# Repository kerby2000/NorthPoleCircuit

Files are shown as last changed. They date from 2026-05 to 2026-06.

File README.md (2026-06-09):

# North Pole BLE Audio Card

This is a work-in-progress derivative of the original
[Janky Jingle Crew NorthPoleCircuit](https://github.com/Janky-Jingle-Crew/NorthPoleCircuit).

The goal is to turn the original moving magnetic Christmas PCB card into a BLE-enabled audio postcard / mini-diorama with rechargeable battery power, real audio playback, capacitive touch controls, Hall checkpoints, and addressable RGB lighting.

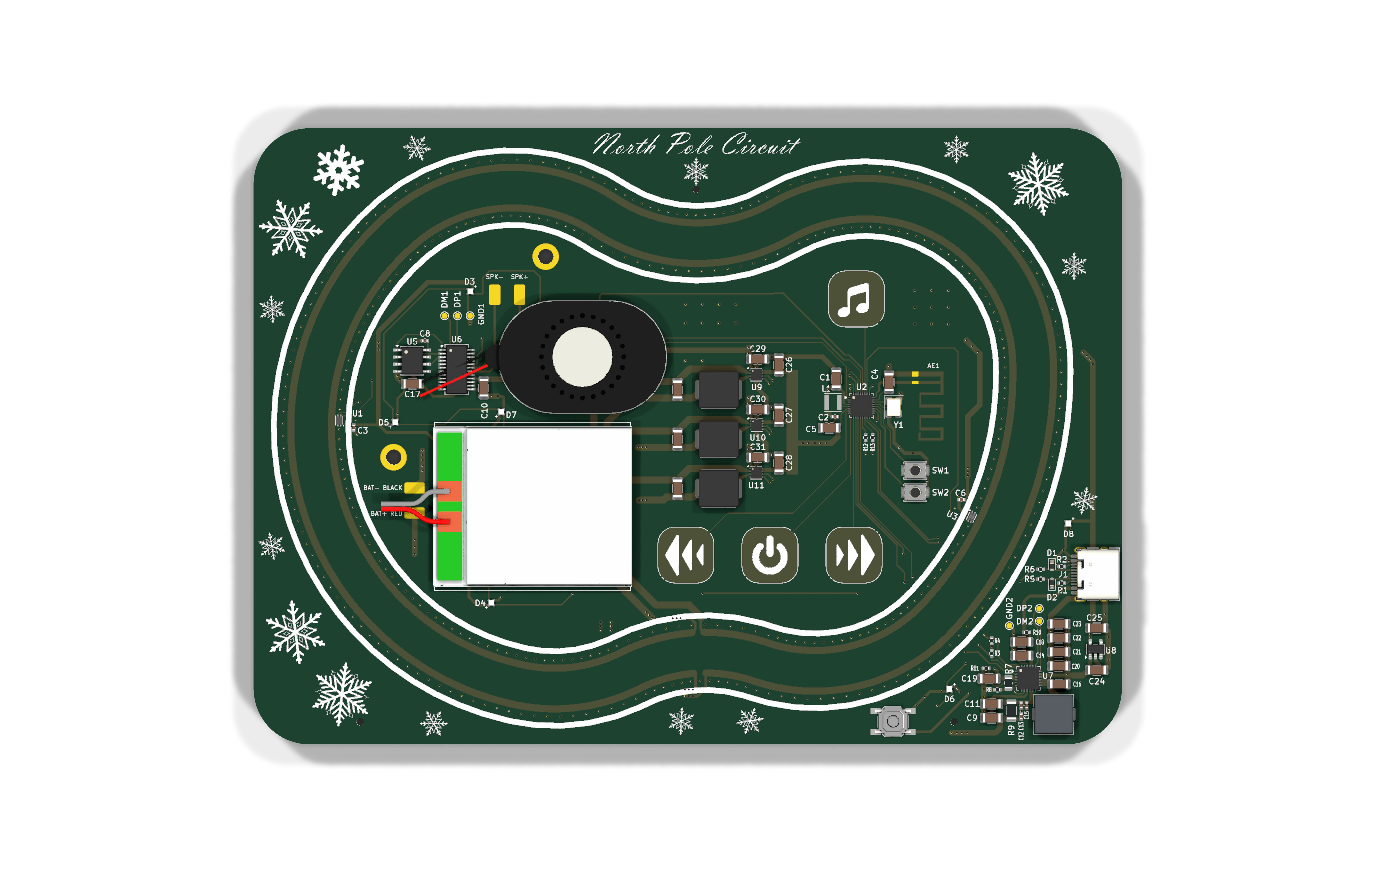
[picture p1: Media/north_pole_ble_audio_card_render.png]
North Pole BLE Audio Card PCB render


## Status

Current state: hardware revision in progress.

- KiCad 10 PCB project is included under `PCB/`.
- Draft JLCPCB manufacturing files are included under `PCB/production/`.
- Firmware bring-up scaffold lives under `Firmware/northpole_ch592_bringup/` and is based on the WCH CH592 EVT BLE Peripheral project.
- The board has not yet been validated on real hardware.
- The audio playback IC sourcing is still a risk and should be checked before ordering.

Do not treat the current production files as a proven release. Review ERC/DRC, BOM sourcing, assembly rotations, antenna keepout, LiPo safety, and audio availability before manufacturing.

## Repository Layout

```text
PCB/                     KiCad 10 hardware project and draft manufacturing files
Firmware/                CH592X BLE/audio firmware bring-up project and docs
audio_assets/            WT2003 external-flash manifest and copy-order packer
Code/                    Original upstream firmware, kept for reference only
CAD/                     Original upstream mechanical assets
Media/                   Original media plus new PCB renders
CHANGES_FROM_ORIGINAL.md Summary of the redesign
```

## Hardware Overview

This redesign keeps the magnetic track idea from the original project, but changes most of the control electronics.

Main blocks in the current KiCad design:

- CH592X BLE MCU
- 3 x DRV8837 H-bridge motor drivers
- WT2003H4-24SS audio playback IC
- PY25Q64HA SPI NOR flash for audio assets
- IP5209 1S LiPo charge / boost PMIC
- ME6211 3.3 V regulator
- 2 x DRV5032 Hall sensors
- 4 capacitive touch buttons
- 6 x 1010 addressable RGB LEDs, currently JLCPCB `C41347988`
- USB-C input
- 32 MHz crystal
- WCH-style PCB BLE antenna footprint
- J3 WCH-LinkE/debug Tag-Connect footprint
- J4 WT2003 USB update Tag-Connect footprint
- thin speaker and 1S LiPo battery placement helpers

## Opening The PCB

Use KiCad 10.

Open:

```text
PCB/NorthPoleCircuit_PCB.kicad_pro
```

The local custom libraries are kept in the repo:

- `PCB/cust_sym.kicad_sym`
- `PCB/cust_fp/`
- `PCB/footprints.pretty/`

## Manufacturing Files

Draft manufacturing outputs are in:

```text
PCB/production/
```

Included files:

- `NorthPoleCircuit_PCB14.zip` - Gerber/drill archive
- `bom.csv` - JLCPCB BOM
- `positions.csv` - JLCPCB pick-and-place
- `designators.csv` - Fabrication Toolkit designator output

Before ordering, re-export these from KiCad/Fabrication Toolkit and compare against the files here.

## Firmware

Firmware for this revision is under [Firmware/](./Firmware/). The initial target is `Firmware/northpole_ch592_bringup/`, copied from a working WCH CH592 EVT BLE Peripheral example and then modified at the application layer.

Important hardware notes:

- J3 is WCH-LinkE/debug: 1=3.3V target reference, 2=TIO/SWDIO/PB14, 4=TCK/SWDCK/PB15, 5=GND, 3/6=NC.
- PB14/PB15 are shared with IP5209 I2C through R15/R14 0 ohm links. Do not expect IP5209 I2C access during active WCH-LinkE debugging.
- J4 is intended as WT2003 USB update only, not ARM SWD, but the current PCB revision is blocked for update use: pin 1 is unconnected, so J4 has D+/D-/GND only. Do not use it for WT2003 USB update until +5 V is routed or a rework power path is documented.
- PB0 controls global DRV8837 `~SLEEP`; idle/fault state is `/SLEEP` low and all bridge IN pins low.

The existing `Code/` directory is from the original upstream NorthPoleCircuit project and is not firmware for the CH592X BLE/audio redesign.

## Major Changes

See [CHANGES_FROM_ORIGINAL.md](./CHANGES_FROM_ORIGINAL.md).

Short version:

- single BLE-capable CH592X control architecture
- rechargeable LiPo power path
- audio playback IC and speaker path
- capacitive touch buttons
- Hall checkpoint sensing
- addressable RGB LEDs
- revised KiCad 10 PCB with custom artwork and JLCPCB metadata

## Attribution

Original project:

- [Janky Jingle Crew - NorthPoleCircuit](https://github.com/Janky-Jingle-Crew/NorthPoleCircuit)

Related inspiration:

- [Jeff McBride - Gauss Speedway](https://jeffmcbride.net/gauss-speedway/)

This repository is a derivative redesign. The original concept, mechanical idea, and much of the visual/magnetic-track inspiration belong to the original authors.

## License

TODO.

Before publishing a release or manufacturing publicly, verify the license/permission status of the upstream NorthPoleCircuit project. If the upstream project has no explicit open-source license, only the new original work in this redesign can be licensed without additional permission.

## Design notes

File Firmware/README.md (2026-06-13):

# Firmware

Firmware for the CH592X BLE/audio revision now has a MounRiver/WCH EVT based bring-up project under `Firmware/northpole_ch592_bringup/`.

The original upstream firmware still exists in `../Code/`, but it targets the original NorthPoleCircuit architecture. Treat it as reference material only. New code should live under `Firmware/` and should be written around the current KiCad design: CH592X BLE MCU, 3 x DRV8837 phase drivers, WT2003H4 audio playback IC, PY25Q64HA audio flash, IP5209 LiPo charge/boost PMIC, ME6211 3.3 V regulator, 2 x DRV5032 Hall sensors, 4 capacitive touch pads, and 6 x addressable RGB LEDs.

## Current Implementation Status

The bring-up framework has been started under this folder and the active target project is copied from the WCH CH592 EVT BLE `Peripheral` example.

- KiCad hardware audit script: `tools/extract_kicad_pinmap.py`
- Generated hardware audit: `docs/hardware_pin_audit.md`
- Generated firmware hardware notes: `northpole_ch592_bringup/APP/include/board_pins_autogen_notes.h`
- MounRiver project: `northpole_ch592_bringup/`
- Safe board pin framework: `northpole_ch592_bringup/APP/include/board.h`, `northpole_ch592_bringup/APP/include/board_pins.h`, `northpole_ch592_bringup/APP/northpole/board.c`
- Bring-up and production entry split: `northpole_ch592_bringup/APP/northpole/app_bringup.c`, `northpole_ch592_bringup/APP/northpole/app_production.c`
- Diagnostic shell scaffold: `northpole_ch592_bringup/APP/northpole/shell.c`
- Peripheral driver scaffolds: motor, Hall, touch, RGB, audio, IP5209, battery, BLE, settings

The selected first target toolchain direction is WCH CH592 EVT SDK native style through MounRiver Studio. See `docs/toolchain.md`.

The unmodified WCH EVT BLE `Peripheral` example builds locally with the MounRiver-bundled `riscv-none-embed-gcc`. The copied North Pole bring-up project also builds locally.

## CH592 Upload Path Status

Primary development/debug path:

```text
MounRiver Studio + WCH-LinkE
```

MounRiver/WCH-LinkE remains the primary development path. A MounRiver LED probe under `mounriver_ch592_led_probe/` builds, downloads, verifies, resets, and runs through MounRiver.

The official native USB ISP GUI path is also proven on the CH592X-EVT-R1-LinkE board:

```text
WCHISPStudio V3.9
Internal tool: WCHISPTool_CH57x-59x V3.10
CH592 USB Download device: 4348:55E0
Driver: official WCH CH375/WCHLink driver stack
```

Secondary and experimental paths are tracked separately:

```text
docs/ch592_upload_matrix.md
docs/ch592_usb_isp_test_plan.md
docs/wlink_attach_debug.md
```

Current policy:

- Daily development/debug: MounRiver, WCH-LinkUtility, or PlatformIO custom `wlink` with manual Download-mode entry.
- Emergency/field flashing: WCHISPStudio GUI native USB ISP is proven; a Windows official CMD tool has not been found yet.
- PlatformIO: `wlink` upload is usable after manual Download-mode entry; native USB ISP through `wchisp` remains experimental.
- PlatformIO bundled `wchisp -V` / no-verify is not acceptable because a no-verify image did not run.
- Do not swap the CH592 USB Download driver with Zadig during normal work. WCHISPStudio and `wchisp` need different driver bindings for `4348:55E0`.

Critical recovery note:

If WCH-LinkUtility, MounRiver, or `wlink` suddenly stop identifying the CH592 after ISP/config
experiments, the chip may be protected. WCHISPStudio can still flash in this state, but WCH-Link
debug attach fails. The recovery that worked was:

```powershell
# Put CH592 into USB Download mode.
# Use Zadig only on USB Module / 4348:55E0, not WCH-Link / 1A86:8010.
$wchisp = "$env:USERPROFILE\.platformio\packages\tool-wchisp\wchisp.exe"
& $wchisp config unprotect
```

See `docs/ch592_unprotect_recovery.md`. Keep `Code and data protection mode` unchecked during
bring-up.

If the bootloader no longer stays visible long enough for normal tools, see
`docs/ch592_brick_recovery.md` and the polling recovery script
`tools/ch592_recovery/revive_ch59x.py`.

## Commands

Regenerate the hardware audit:

```powershell
python Firmware\tools\extract_kicad_pinmap.py --repo-root .
```

Run the build wrapper in audit-only mode:

```powershell
powershell -ExecutionPolicy Bypass -File Firmware\tools\build.ps1 -AuditOnly
```

Build wrappers for the intended profiles:

```powershell
powershell -ExecutionPolicy Bypass -File Firmware\tools\build.ps1 -Profile evt-baseline
powershell -ExecutionPolicy Bypass -File Firmware\tools\build.ps1 -Profile bringup
powershell -ExecutionPolicy Bypass -File Firmware\tools\build.ps1 -Profile production
powershell -ExecutionPolicy Bypass -File Firmware\tools\build_mvp_demo.ps1
powershell -ExecutionPolicy Bypass -File Firmware\tools\build_matrix.ps1
```

These wrappers default to `C:\WCH\CH592EVT` and `C:\MounRiver\MounRiver_Studio2`. Build outputs are expected under `Firmware/build/`, which is ignored by git.

The MVP demo wrapper writes its flashable image to:

```text
Firmware/build/mvp_demo/northpole_ch592_bringup.hex
```

Use this only with the documented Rev-A rework state:
`docs/mvp_demo.md`, `docs/rev_a_mvp_rework_state.md`, and
`docs/first_integrated_demo_checklist.md`.

Run host-side logic tests:

```powershell
python -m unittest discover Firmware\host_tests
```

Smoke-test scripts for first-board validation:

```powershell
python Firmware\tools\usb_shell_smoke_test.py --port COM7
python Firmware\tools\ble_diag_smoke_test.py --scan
```

## Hardware Audit Result

The current generated audit passes the major firmware-facing connections. The suspected WT2003 UART issue is not a board blocker in the current PCB: U2 UART nets reach WT2003 RX/TX through R12/R13 series resistors. The WCH UART backend and WT2003HX V2.00 protocol layer exist in the MounRiver bring-up project, but WT2003 command responses, BUSY timing, and playback still need hardware validation before production use.

## Firmware Strategy

Use two top-level firmware entry points with shared drivers:

- `main_production.c` - the final user-facing firmware. It should expose only safe controls, run quiet logging, enforce current/time limits, handle faults cleanly, and default to low-power idle.
- `main_bringup.c` - a diagnostic firmware with explicit test hooks for board validation. It should expose raw sensor readings, manual peripheral commands, motor safety interlocks, and verbose status output.

Both builds should share the same board support and peripheral drivers. The split should be at the application layer, not by duplicating low-level code.

Recommended structure:

```text
Firmware/
  README.md
  platformio.ini or wch_project/
  include/
    board.h
    build_profile.h
    fault.h
  src/
    main_production.c
    main_bringup.c
    board.c
    clock.c
    log.c
    fault.c
    power_ip5209.c
    battery.c
    touch.c
    rgb_ws2812.c
    hall.c
    motor_drv8837.c
    motor_track.c
    audio_wt2003.c
    audio_assets.c
    ble_service.c
    settings.c
    diagnostics.c
  tools/
    flash.ps1 or flash.sh
    read_log.ps1 or read_log.sh
    audio_asset_pack.py
```

If the selected CH592X toolchain makes separate entry files awkward, use one entry file plus a compile-time profile:

```c
#if defined(FIRMWARE_PROFILE_BRINGUP)
    app_bringup_run();
#else
    app_production_run();
#endif
```

## Shared Firmware Rules

- All outputs must start in the safest state: motor driver inputs low, motor enables off, RGB LED output idle, audio stopped or muted, unused pins configured deliberately.
- Production and bring-up builds must use the same `board.c` pin map so a wiring fix is made once.
- Motor commands must have a timeout/deadman. If the main loop stalls, BLE disconnects, or the command stream stops, PWM should go to zero and the DRV8837s should disable.
- Keep BLE, LED timing, touch sampling, and motor PWM from blocking each other. Use timer/DMA/peripheral support where possible, especially for WS2812 timing.
- Do not allow raw motor bridge commands in production BLE services.
- Keep current limits conservative until real board measurements exist.
- Store board revision, firmware profile, firmware version, and build date in a readable diagnostic command.
- Every bring-up command that can heat the coils, stress the battery, or make sound must be explicit and bounded.

## Toolchain And Project Setup

1. Select the CH592X build path.
   - Prefer the WCH-supported CH592X SDK/toolchain if it gives reliable BLE examples and flashing.
   - Confirm the linker script, startup code, BLE stack library, USB/UART support, and flash programming path before writing board-specific code.
   - Record the exact SDK version and flashing adapter in this README once selected.

2. Create a minimal firmware project.
   - Build an empty CH592X app.
   - Flash it to a known-good dev board or first PCB if available.
   - Confirm reset, boot mode, programming connection, and a basic delay loop.

3. Add build profiles.
   - `production`: optimized, limited logs, watchdog enabled, safe feature set.
   - `bringup`: verbose logs, diagnostic command interface, asserts enabled, extra telemetry.

4. Add repeatable commands.
   - Build production firmware.
   - Build bring-up firmware.
   - Flash selected profile.
   - Capture serial logs.
   - Stamp firmware version and git commit into the build.

5. Create the board pin map.
   - Extract every CH592X pin assignment from `../PCB/NorthPoleCircuit_PCB.kicad_sch`.
   - Define pins once in `board.h` and `board.c`.
   - Include signal direction, reset state, active polarity, alternate function, and safety notes.
   - Verify peripheral mux conflicts before writing drivers.

## Production Firmware Plan

The production firmware should behave like a finished BLE audio postcard, not like a test fixture.

Core production behavior:

- Boot into a safe idle state.
- Run a short self-test that checks firmware identity, stored settings, battery status if available, and peripheral readiness.
- Advertise BLE with a stable device name.
- Support touch controls for local operation.
- Play predefined scenes that coordinate audio, RGB animation, and track motion.
- Use Hall sensor events to synchronize or correct sled movement when possible.
- Use conservative motor acceleration, speed, duty, and runtime limits.
- Enter a low-power idle mode when inactive.
- Expose clear fault behavior: low battery, motor overrun timeout, audio failure, BLE command invalid, storage/settings invalid.

Suggested production touch mapping:

- Touch 1: play/pause current scene.
- Touch 2: next scene or next track.
- Touch 3: brightness or volume step.
- Touch 4: BLE/config action, long-press for pairing/config reset.

Suggested production BLE services:

- Device information: firmware version, board revision, profile, battery/status.
- Playback control: play, pause, stop, next scene, volume.
- Lighting control: brightness, selected palette, animation mode.
- Motion control: safe scene-level speed/intensity only. No raw phase commands.
- Settings: persistent volume, brightness, demo mode, shipping/low-power mode.
- Diagnostics: read-only fault/status counters.

Production safety requirements:

- Motor PWM starts disabled and only enables inside a scene or validated motion command.
- Motor runtime has a hard maximum per activation.
- Motor duty and acceleration are capped by constants measured during bring-up.
- BLE disconnect or invalid command leaves the active scene in a known state.
- Low battery or unstable supply prevents motor start.
- Watchdog resets into motor-off/audio-off/RGB-off state.

## Bring-Up Firmware Plan

The bring-up firmware should make the board easy to validate one subsystem at a time. It should be allowed to expose unsafe low-level commands, but each risky command must require arming and must time out automatically.

Preferred interfaces:

- Serial diagnostic shell over the available debug UART or USB CDC if practical.
- Optional BLE diagnostic service after BLE is proven.
- Human-readable command responses with machine-readable values where possible.

Suggested diagnostic commands:

```text
help
version
status
faults
pins
rail status
rail battery
touch raw
touch stream
touch threshold <pad> <value>
rgb off
rgb one <index> <r> <g> <b>
rgb chase <brightness>
hall read
hall stream
audio status
audio version
audio qstatus
audio qcount-ext
audio qperiph
audio volume <0-31>
audio play-index <file_id>
audio play-name <name-no-ext>
audio stop
i2c scan
ip5209 read
motor arm <seconds>
motor off
motor phase <driver> <a|b|coast|brake> <duty>
motor pwm <driver> <forward|reverse> <duty>
motor step <direction> <steps> <duty>
motor sweep <direction> <duty> <seconds>
scene demo
sleep
reset
```

Bring-up firmware guardrails:

- `motor arm` is required before any motor command.
- The arm window expires automatically.
- Motor duty has a compile-time bring-up maximum that starts very low.
- The shell prints the active current/duty/time limit before enabling motor outputs.
- Audio starts at low volume.
- RGB brightness starts low to limit current.
- Commands that change persistent settings should require explicit confirmation.

## Board Bring-Up Checklist

Use the bring-up firmware only after the hardware passes basic power checks. Do not connect a LiPo cell until the USB power path, charge behavior, and battery pad polarity are verified.

Required bench equipment:

- Current-limited bench supply.
- USB-C power meter or current-limited USB source.
- Digital multimeter.
- Oscilloscope or logic analyzer.
- CH592X-compatible programmer/debug adapter.
- BLE scanner phone or desktop BLE tool.
- Known-good small speaker or dummy load as appropriate.
- Magnet or assembled sled for Hall testing.
- Thermal camera or contact thermometer for motor/PMIC checks.

### Stage 0: Pre-Power Inspection

1. Confirm board revision and assembly options.
2. Inspect USB-C, IP5209, ME6211, CH592X, WT2003H4, DRV8837s, Hall sensors, RGB LEDs, and crystal orientation.
3. Check for solder bridges around the QFN/SSOP/QFP fine-pitch parts.
4. Measure resistance to ground on VBUS, battery pad, boosted rail if exposed, and 3.3 V.
5. Confirm battery pad polarity against board markings.
6. Confirm no visible copper damage around the antenna and matching network.
7. Record photos before applying power.

Exit criteria:

- No hard short on the main rails.
- Battery polarity is confirmed.
- Visual inspection has no unresolved assembly defects.

### Stage 1: Power Path Smoke Test

1. Power from USB-C with a conservative current limit and no battery installed.
2. Measure VBUS at the connector and downstream power path.
3. Measure battery pad voltage and confirm charge behavior is sane with no battery attached.
4. Measure the ME6211 3.3 V output.
5. Check rail ripple and startup shape with the oscilloscope.
6. Touch-check or thermal-check the IP5209, regulator, MCU, and audio IC for abnormal heating.
7. Repeat USB-C plug orientation tests.
8. If using a battery simulator or protected cell, verify charge current and termination behavior before installing a real cell.

Exit criteria:

- 3.3 V is within tolerance.
- No component heats unexpectedly.
- USB-C orientation does not change behavior.
- Battery/charger behavior is understood before a LiPo is attached.

### Stage 2: CH592X Programming And Clock Bring-Up

1. Connect the programmer/debug adapter.
2. Confirm the target can be identified.
3. Flash a minimal bring-up image.
4. Verify reset behavior and boot mode.
5. Start a debug UART or USB log if available.
6. Confirm the system clock and 32 MHz crystal behavior.
7. Blink or toggle a harmless GPIO if one is available, or print a heartbeat log.

Exit criteria:

- Firmware can be flashed repeatedly.
- Reset and boot are reliable.
- A stable debug log or heartbeat exists.

### Stage 3: Safe Pin Initialization

1. Boot the bring-up firmware with all high-power outputs disabled.
2. Verify DRV8837 input pins and enables are inactive after reset and after firmware startup.
3. Verify the RGB data line does not produce random LED colors at boot.
4. Verify audio control pins do not start playback or pop the speaker.
5. Confirm unused pins are configured to avoid floating high-current states.
6. Save oscilloscope captures of sensitive outputs during reset.

Exit criteria:

- Firmware startup does not move the sled, flash the LEDs unexpectedly, or start audio.
- All unsafe outputs remain off until commanded.

### Stage 4: Low-Speed Digital Interfaces

1. Run `i2c scan`.
2. Confirm the IP5209 responds if its I2C interface is present and enabled on this board.
3. Read battery/charge/status registers if supported.
4. Log fallback ADC or GPIO status if the PMIC interface is not usable.
5. Verify pullups, bus idle levels, and clock/data waveforms.

Exit criteria:

- I2C bus does not hang.
- Power/battery status path is either working or documented as unavailable.

### Stage 5: Capacitive Touch

1. Read raw counts from all 4 pads with the board untouched.
2. Read raw counts while touching each pad individually.
3. Repeat with USB powered, battery powered, and while audio/RGB/motor are idle.
4. Tune baseline tracking, debounce, hysteresis, and long-press timing.
5. Check false touches near the track, battery, speaker, and antenna areas.
6. Store initial thresholds as conservative defaults.

Exit criteria:

- Each pad has clear touch/no-touch separation.
- False triggers are rare during idle.
- Long press and short press behavior is repeatable.

### Stage 6: RGB LED Chain

1. Start with global brightness capped low.
2. Light one LED red, green, and blue to verify color order.
3. Step through all 6 LEDs to verify chain order and soldering.
4. Run a low-brightness chase pattern.
5. Check supply ripple and current draw at increasing brightness levels.
6. Confirm BLE and touch still work while LEDs update.

Exit criteria:

- All 6 LEDs respond in the expected order.
- Color order is documented.
- Production brightness limit is chosen from measured current draw.

### Stage 7: Hall Sensors

1. Read idle state from HALL1 and HALL2.
2. Move a magnet over each sensor and record transition polarity.
3. Test with the actual sled magnet orientation.
4. Decide whether polling or interrupts are more reliable.
5. Tune debounce and minimum interval filtering.
6. Log events while manually moving the sled around the track.

Exit criteria:

- Both Hall sensors detect the sled reliably.
- Event polarity and timing are documented.
- Production filtering constants are chosen.

### Stage 8: Audio Playback

1. Confirm WT2003H4 power rails and reset state.
2. Verify UART idle level and baud rate.
3. Run `audio version`, `audio qperiph`, and `audio qcount-ext`.
4. After the J4 +5 V update-power issue is fixed or a rework path is documented, program or install one minimal known-good `0001.mp3` asset, then disconnect WT2003 USB.
5. Set `audio volume 5` and play a short low-volume test file with `audio play-index 1`.
6. Test stop, volume, next-file, and error/status responses.
7. Measure current draw and check for speaker pops at startup/shutdown.
8. Document the audio file naming, indexing, and flash programming process.

Exit criteria:

- At least one audio file plays reliably.
- Volume and stop commands work.
- Audio asset packaging is repeatable.

### Stage 9: BLE Bring-Up

1. Advertise a bring-up device name that includes the board/profile.
2. Confirm discovery with a phone or desktop BLE scanner.
3. Connect, disconnect, and reconnect repeatedly.
4. Expose read-only version/status first.
5. Add safe commands for RGB, audio, and touch status.
6. Add production-level playback/settings controls after the basic service is stable.
7. Test BLE while RGB animations and touch scanning are active.

Exit criteria:

- Advertising and reconnect are reliable.
- GATT characteristics are documented.
- BLE does not break timing-sensitive peripherals.

### Stage 10: DRV8837 And Track Motor Bring-Up

Do this last. Use a current-limited supply and start with the lowest possible duty cycle. Keep the board accessible for temperature checks.

1. Confirm motor/coil resistance and expected current before enabling firmware control.
2. Scope each DRV8837 input while outputs are still disabled or unloaded if practical.
3. Enable one DRV8837 at a time with very low duty and short duration.
4. Test coast, brake, forward, and reverse behavior where applicable.
5. Verify no shoot-through command sequence is possible in the driver abstraction.
6. Measure supply current and component temperature after each short pulse.
7. Increase duty only after current and heating are understood.
8. Bring up phase stepping without the sled, then with the sled.
9. Determine phase order, direction sign, starting duty, running duty, acceleration ramp, and maximum safe runtime.
10. Use Hall events to validate speed and position assumptions.
11. Save measured safe limits into production constants.

Exit criteria:

- All 3 DRV8837 channels respond correctly.
- The sled can move under firmware control.
- Thermal/current limits are measured and documented.
- Production motor constants are conservative.

### Stage 11: Integrated Demo

1. Build one simple scene: touch starts audio, RGB animation, and low-speed sled movement.
2. Use Hall checkpoints to log movement timing during the scene.
3. Test scene stop from touch and BLE.
4. Test fault paths: BLE disconnect, low battery condition if simulated, motor timeout, audio failure.
5. Run a repeated demo loop and monitor battery voltage, current, and component temperature.
6. Tune scene timing, brightness, volume, and motor intensity.

Exit criteria:

- The board runs an integrated demo without resets or unsafe heating.
- The user-facing controls are understandable.
- Fault handling returns to a safe state.

## Driver Implementation Notes

### `board.c` / `board.h`

- Own all pin names, alternate functions, active polarity, and safe reset states.
- Provide `board_init_safe_pins()` before any subsystem driver starts.
- Provide `board_print_pin_map()` for bring-up firmware.

### `fault.c`

- Centralize faults and warnings.
- Track sticky faults until reset or explicit clear.
- Production faults should shut down motor/audio where appropriate.

### `log.c`

- Bring-up profile: verbose serial logs and command responses.
- Production profile: compact event counters and optional BLE-readable status.

### `power_ip5209.c` / `battery.c`

- Read PMIC status if available.
- Provide battery state abstraction even if the first revision only supports coarse status.
- Gate motor start on acceptable supply conditions.

### `touch.c`

- Support raw reads, baseline tracking, thresholds, debounce, short press, and long press.
- Bring-up firmware should stream raw values.
- Production firmware should emit semantic events only.

### `rgb_ws2812.c`

- Keep timing isolated from BLE and motor PWM.
- Provide global brightness limiting.
- Include color order and LED order constants discovered during bring-up.

### `hall.c`

- Support direct reads, optional interrupts, timestamped events, debounce, and event counters.
- Production code should consume events without depending on exact mechanical timing.

### `audio_wt2003.c`

- Wrap WT2003HX UART protocol details behind clear commands: init, status, query, play file, stop, pause, next/previous, output mode, sleep, and volume.
- Keep frame encode/parser tests for datasheet examples, plus timeouts and error reporting.
- Keep the audio asset manifest in firmware or generated from the audio packaging tool.

### `motor_drv8837.c` / `motor_track.c`

- Low-level driver owns each DRV8837 input state and PWM duty.
- Track driver owns phase stepping, direction, ramping, run timeout, and Hall feedback.
- Production code commands motion intent, not raw bridge state.
- Bring-up code may command raw bridge state only while armed.

### `ble_service.c`

- Start with read-only status.
- Add safe write characteristics one group at a time.
- Keep raw diagnostics out of the production profile unless they are read-only.

### `settings.c`

- Store persistent user settings with versioning and checksum.
- Include factory reset path from touch long-press and diagnostic command.
- Never let corrupt settings produce unsafe motor or audio behavior.

## Test And Validation Plan

Bench validation:

- Each driver has a bring-up command that proves it independently.
- Each risky command has a timeout.
- Every subsystem logs pass/fail and measured values.
- Capture rail voltage/current notes for each stage.

Firmware validation:

- Production and bring-up profiles both build from a clean checkout.
- Static pin map review matches the schematic.
- Startup state leaves high-power outputs disabled.
- Watchdog or main-loop health monitor is tested.
- Settings corruption path is tested.
- BLE reconnect path is tested.

System validation:

- Integrated demo runs from USB power.
- Integrated demo runs from battery after charger validation.
- Touch works while audio and RGB are active.
- BLE remains usable during a running scene.
- Motor current and temperature remain inside measured limits.
- The board can recover from reset during a scene without leaving outputs enabled.

Release validation:

- Tag firmware version.
- Save build artifacts for production and bring-up profiles.
- Record audio asset pack version.
- Record board revision and any required hardware rework.
- Update this README with measured limits and known issues.

## Initial Milestones

1. Create CH592X firmware skeleton and confirm flashing.
2. Add `main_bringup.c`, logging, and safe pin initialization.
3. Add board pin map from the KiCad schematic.
4. Bring up power/status and basic digital interfaces.
5. Bring up touch, RGB, Hall, audio, then BLE.
6. Bring up DRV8837/motor control last.
7. Create `main_production.c` with safe scene-level behavior.
8. Tune production constants from measured board data.
9. Run integrated demo and fault testing.
10. Freeze firmware release candidate and keep bring-up firmware available for future board revisions.

## Known Risks To Track

- WT2003H4 sourcing, UART protocol details, and audio asset layout.
- CH592X peripheral mux conflicts once exact pins are confirmed.
- WS2812 timing interference from BLE stack interrupts.
- Capacitive touch thresholds changing with battery state, enclosure, humidity, or hand position.
- DRV8837 current and heating during track operation.
- BLE antenna tuning and nearby copper/mechanical effects.
- IP5209 telemetry availability and behavior on this exact variant.
- LiPo charge current, battery protection, and safe shipping/storage behavior.

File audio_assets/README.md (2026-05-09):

# WT2003 Audio Assets

This folder tracks the intended WT2003 external-flash audio set. The files themselves are not committed by default.

Use short root-directory names such as `0001.mp3`. Keep the name before the extension to 8 characters or fewer. Filename playback uses the name without the extension, for example `audio play-name 0001`.

Index playback depends on copy order, not filename sort order. Use `pack_audio_assets.py` to create an ordered folder, then copy that folder's contents to the WT2003 USB drive through J4.

First hardware validation should use one low-volume file named `0001.mp3` only. Disconnect the WT2003 USB cable before UART playback; the chip may ignore serial commands while mounted as USB storage on a computer.

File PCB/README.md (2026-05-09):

# PCB

This folder contains the KiCad 10 hardware project for the BLE/audio redesign.

Open `NorthPoleCircuit_PCB.kicad_pro` in KiCad 10.

Local project assets:

- `cust_sym.kicad_sym` - custom symbols
- `cust_fp/` - custom footprints used by the board
- `footprints.pretty/` - local STEP models referenced by the PCB
- `production/` - draft manufacturing outputs

The production files are draft outputs for review. Re-export them from KiCad/Fabrication Toolkit before ordering boards.

## Firmware And Bring-Up

The detailed CH592X firmware implementation and first-board bring-up plan is maintained in `../Firmware/README.md`.

Use the bring-up/test firmware profile first. It should keep all high-power outputs disabled at boot and expose explicit diagnostic hooks for power, touch, RGB LEDs, Hall sensors, audio, BLE, and DRV8837 motor testing before running the production firmware.

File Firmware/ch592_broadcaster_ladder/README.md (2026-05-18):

# CH592 Broadcaster Ladder

This is a dev-board-only BLE isolation project.

It starts from the WCH `EVT/EXAM/BLE/Broadcaster` structure that is already proven on the CH592X-EVT-R1-LinkE board. The goal is to change one thing at a time until the first failing change is found.

Build from repo root:

```powershell
& .\Firmware\tools\build.ps1 -Profile broadcaster-ladder
```

Expected scanner result:

```text
abc
```

Build with only the advertising payload changed:

```powershell
& .\Firmware\tools\build.ps1 -Profile broadcaster-ladder -ExtraDefine LADDER_ADV_NORTHPOLE=1
```

Expected scanner result:

```text
NorthPole BLE
```

or short name:

```text
NPB
```

Build with the exact NorthPole broadcaster module:

```powershell
& .\Firmware\tools\build.ps1 -Profile broadcaster-ladder -ExtraDefine LADDER_USE_NORTHPOLE_BROADCASTER=1
```

Expected scanner result:

```text
NorthPole BLE
```

Build with the NorthPole support modules linked but not initialized:

```powershell
& .\Firmware\tools\build.ps1 -Profile broadcaster-ladder -ExtraDefine @('LADDER_USE_NORTHPOLE_BROADCASTER=1','LADDER_LINK_NORTHPOLE_MODULES=1','APP_USB_CDC_SHELL_ENABLE=0')
```

Expected scanner result:

```text
NorthPole BLE
```

Build with low-risk NorthPole state initialization:

```powershell
& .\Firmware\tools\build.ps1 -Profile broadcaster-ladder -ExtraDefine @('LADDER_USE_NORTHPOLE_BROADCASTER=1','LADDER_LINK_NORTHPOLE_MODULES=1','LADDER_INIT_NORTHPOLE_CORE=1','APP_USB_CDC_SHELL_ENABLE=0')
```

Expected scanner result:

```text
NorthPole BLE
```

Build with NorthPole board safe-pin initialization:

```powershell
& .\Firmware\tools\build.ps1 -Profile broadcaster-ladder -ExtraDefine @('LADDER_USE_NORTHPOLE_BROADCASTER=1','LADDER_LINK_NORTHPOLE_MODULES=1','LADDER_INIT_NORTHPOLE_CORE=1','LADDER_INIT_NORTHPOLE_BOARD_SAFE=1','APP_USB_CDC_SHELL_ENABLE=0')
```

This is expected to be risky on CH592X-EVT-R1-LinkE because the dev-board pinout is not the NorthPole PCB pinout.

Build with the rest of the NorthPole app/profile sources linked but not initialized:

```powershell
& .\Firmware\tools\build.ps1 -Profile broadcaster-ladder -ExtraDefine @('LADDER_USE_NORTHPOLE_BROADCASTER=1','LADDER_LINK_NORTHPOLE_MODULES=1','LADDER_INIT_NORTHPOLE_CORE=1','LADDER_INIT_NORTHPOLE_BOARD_SAFE=1','LADDER_LINK_FULL_NORTHPOLE_APP=1','APP_USB_CDC_SHELL_ENABLE=0')
```

Expected scanner result:

```text
NorthPole BLE
```

Build with the exact NorthPole `peripheral_main.c` as `main`, using broadcaster-smoke mode:

```powershell
& .\Firmware\tools\build.ps1 -Profile broadcaster-ladder -ExtraDefine @('LADDER_USE_NORTHPOLE_MAIN=1','APP_DEV_BOARD_BLE_BROADCASTER_SMOKE=1','APP_USB_CDC_SHELL_ENABLE=0')
```

Expected scanner result:

```text
NorthPole BLE
```

Flash output:

```text
Firmware\build\broadcaster_ladder_abc\broadcaster_ladder.hex
Firmware\build\broadcaster_ladder_northpole\broadcaster_ladder.hex
Firmware\build\broadcaster_ladder_northpole_module\broadcaster_ladder.hex
Firmware\build\broadcaster_ladder_northpole_linked\broadcaster_ladder.hex
Firmware\build\broadcaster_ladder_init_core\broadcaster_ladder.hex
Firmware\build\broadcaster_ladder_init_board_safe\broadcaster_ladder.hex
Firmware\build\broadcaster_ladder_full_link\broadcaster_ladder.hex
Firmware\build\broadcaster_ladder_northpole_main\broadcaster_ladder.hex
```

Do not use this project as production firmware. It exists only to isolate CH592 BLE bring-up behavior before the NorthPole target board arrives.

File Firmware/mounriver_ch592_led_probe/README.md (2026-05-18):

# MounRiver CH592 LED Probe

This is a MounRiver/WCH-SDK-native LED probe for the CH592X-EVT-R1-LinkE development board.

It is copied from the WCH `LCD` example project structure and replaces only the application file with a simple LED test. It is separate from the North Pole firmware and is only for proving that MounRiver-built firmware runs on the dev board.

## Source

The project links to the WCH SDK at:

```text
C:\WCH\CH592EVT\EVT\EXAM\SRC
```

Keep the SDK in that location.

## Known-Good MounRiver Settings

This probe was successfully built and downloaded from MounRiver with these project settings stored in `mounriver_ch592_led_probe.wvproj`:

| Setting | Value |
|---|---|
| Vendor/toolchain | WCH / RISC-V |
| Series / MCU | CH59X / CH592X |
| Link setting | WCH-Link |
| SDK linked folders | `C:\WCH\CH592EVT\EVT\EXAM\SRC\Ld`, `RVMSIS`, `Startup`, `StdPeriphDriver` |
| Build output | `obj/mounriver_ch592_led_probe.hex` |
| Flash MCU type | `CH59x` |
| Flash address | `0x00000000` |
| Flash clock speed | Low |
| Flash operations | erase, program, verify, reset |
| Debug OpenOCD config | `${WCH:OpenOCD:default}/bin/wch-riscv.cfg` |

Keep the SDK installed at `C:\WCH\CH592EVT\`. The MounRiver project uses absolute links into that SDK tree.

## Programming Path

On this CH592X-EVT-R1-LinkE board, the working MounRiver path appears to be:

```text
PC -> WCH-LinkE USB interface -> WCH-LinkE controller -> CH592 debug/download interface
```

The project is configured as a WCH-Link project, not as a direct CH592 USB bootloader project.

The board still needs to be placed in Download mode because this board/firmware state does not yet support normal always-available debug attach from reset. Download mode gives the WCH tool a reliable short window to take control, erase/program/verify, then reset and run the flashed application.

This is different from PlatformIO `isp`, which uses the CH592 native USB bootloader device directly:

| Path | Physical interface | Needs Download mode | Uses WCH-LinkE |
|---|---|---:|---:|
| MounRiver working path | WCH-LinkE to target debug/download wiring | Yes on this board/setup | Yes |
| PlatformIO `isp` | PC USB to CH592 native USB bootloader | Yes | No |
| PlatformIO `wch-link` / `wlink` | WCH-LinkE to TCK/TIO debug wires | Normally no, if debug attach works | Yes |

## LED / LCD Mapping

From the CH592X-EVT-R1-LinkE schematic:

| LED | MCU pin | Notes |
|---|---|---|
| D4 / LED2 | Header net `LED2` | Not directly tied to PA4 unless jumpered |
| D3 / LED1 | Header net `LED1` | Not directly tied to PB23 unless jumpered |
| D1 power | 3.3 V rail | Always on, not firmware-controlled |

The current probe toggles PA4 and PB23 alternately every 250 ms. PA4 and PB23 are also LCD segment pins on this dev board, so without jumpers the visible result can be blinking LCD segments instead of LEDs. That still proves the downloaded program is running.

To blink the board LEDs, add jumper wires from the MCU header pins to the LED header pins:

| Jumper | Expected result |
|---|---|
| PA4 to `LED2` | D4 / LED2 blinks |
| PB23 to `LED1` | D3 / LED1 blinks, but this pin is also the Download/reset-side pin and may affect boot behavior |

## MounRiver Use

1. Open MounRiver Studio.
2. If this probe was already imported, remove it from the MounRiver workspace first. Do not delete project contents from disk.
3. Open `Firmware\mounriver_ch592_led_probe\mounriver_ch592_led_probe.wvproj`, or import the folder as an existing project.
4. Confirm the linked folders `Ld`, `RVMSIS`, `Startup`, and `StdPeriphDriver` are not marked invalid.
5. Build the `obj` configuration.
6. Flash the generated HEX using the MounRiver download path that already works on your machine.
7. After reset, D4 and D3 should alternate. If only D4 blinks, PB23 is being held or affected by Download wiring.

Expected generated file:

```text
Firmware\mounriver_ch592_led_probe\obj\mounriver_ch592_led_probe.hex
```

If MounRiver still reports `CH59x_common.h` missing, check that this SDK file exists:

```text
C:\WCH\CH592EVT\EVT\EXAM\SRC\StdPeriphDriver\inc\CH59x_common.h
```

This project does not test BLE, USB CDC, audio, or the North Pole board.

Upload path status and command-line experiments are tracked in:

```text
Firmware/docs/ch592_upload_matrix.md
Firmware/docs/ch592_usb_isp_test_plan.md
Firmware/docs/wlink_attach_debug.md
```

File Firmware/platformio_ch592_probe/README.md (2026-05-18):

# CH592X PlatformIO Probe

This is a small PlatformIO probe project for the CH592X-EVT-R1-LinkE development board. It is only for isolating upload paths from VS Code. It is not the source of truth for the North Pole firmware.

The active North Pole firmware remains the WCH EVT/MounRiver project in:

```text
Firmware/northpole_ch592_bringup/
```

The known-good LED probe is:

```text
Firmware/mounriver_ch592_led_probe/
```

## Status

| Path | Status | Notes |
|---|---|---|
| MounRiver GUI download through WCH-LinkE | PASS | Golden reference. Same HEX runs on the board. |
| WCHISPStudio native USB ISP GUI | PASS | WCHISPStudio V3.9 / WCHISPTool_CH57x-59x V3.10 works with the official WCH driver. |
| PlatformIO `ch592x_wlink_download_mode` | PASS | Requires manually putting CH592 into Download mode first. Uses `wlink --chip CH59X --speed low --erase`. |
| PlatformIO `ch592x_wlink_mounriver_hex_download_mode` | PASS | Same `wlink` path, but flashes the known-good MounRiver HEX. |
| PlatformIO `ch592x_isp_mounriver_hex` | EXPERIMENTAL | Keeps one USB ISP target for future bootloader experiments. Current result was verify mismatch or WinUSB/WCH-driver conflict. |

Do not treat any no-verify `wchisp` result as a successful flash on this board.

## Build Only

The default environment is intentionally build-only:

```powershell
pio run -d Firmware\platformio_ch592_probe
```

If you accidentally run upload against `ch592x_build_only`, it fails with an explanatory message.

## WCH-LinkE Download-Mode Upload

This is the first confirmed working PlatformIO-controlled WCH-LinkE path.

Required sequence:

1. Power the CH592X-EVT-R1-LinkE board.
2. Put the CH592 into Download mode.
3. Run one of the commands below before Download mode times out.

Build and upload the PlatformIO probe firmware:

```powershell
pio run -d Firmware\platformio_ch592_probe -e ch592x_wlink_download_mode -t upload
```

Upload the known-good MounRiver HEX through the same `wlink` path:

```powershell
pio run -d Firmware\platformio_ch592_probe -e ch592x_wlink_mounriver_hex_download_mode -t upload
```

Before using the MounRiver HEX upload target, build the MounRiver probe so this generated file exists:

```text
Firmware\mounriver_ch592_led_probe\obj\mounriver_ch592_led_probe.hex
```

The custom upload command shape is:

```powershell
wlink flash --chip CH59X --speed low --erase <firmware.hex>
```

Known direct command that passed:

```powershell
C:\Users\lukin\.platformio\packages\tool-wlink\wlink.exe flash --chip CH59X --speed low --erase --address 0x00000000 "Firmware\mounriver_ch592_led_probe\obj\mounriver_ch592_led_probe.hex"
```

`wlink` warns that `--address` is ignored for Intel HEX and ELF inputs, so the PlatformIO wrapper omits it and relies on the HEX load addresses.

PlatformIO's packaged `tool-wlink @ 0.23.241116+sha.f44158e` contains a 32-bit `wlink.exe`:

```text
C:\Users\lukin\.platformio\packages\tool-wlink\wlink.exe
PE machine: 0x014C, x86 / PE32
wlink --version: 0.1.1
```

The downloaded upstream `wlink 0.1.2` x86 build works with the same Download-mode sequence. The x64 build can list the probe through `nusb`, but currently fails on status/flash with:

```text
USB error: incompatible driver is installed for this interface
```

Do not replace PlatformIO's managed `tool-wlink` package by hand. `wlink 0.1.2` was tested and is not retained in this repository because PlatformIO's packaged `wlink 0.1.1` already works in Download mode.

## Experimental USB ISP

This environment uses the CH592 native USB Download/ISP bootloader and PlatformIO's bundled `wchisp`. It does not use WCH-LinkE.

```powershell
pio run -d Firmware\platformio_ch592_probe -e ch592x_isp_mounriver_hex -t upload
```

Known result on this board:

| Test | Result |
|---|---|
| `ch592x_isp_mounriver_hex` with WinUSB/libusb driver | FAIL, verify mismatch |
| `ch592x_isp_mounriver_hex` with official WCH driver | FAIL, `wchisp` cannot open `4348:55E0` |
| Standalone `wchisp 0.3.0` with official WCH driver | FAIL, `wchisp` cannot open `4348:55E0` |
| WCHISPStudio V3.9 native USB ISP GUI | PASS |

This target is retained only for future USB bootloader experiments. The current recommended CLI path is `ch592x_wlink_download_mode`.

Driver note:

```text
CH592 USB Download VID:PID: 4348:55E0
Official WCHISPStudio expects the WCH CH375/WCHLink driver stack.
ch32-rs/wchisp expects WinUSB/libusb/nusb.
Windows can bind only one driver to that USB interface at a time.
```

Do not switch the working WCH driver binding with Zadig unless deliberately testing `wchisp`.

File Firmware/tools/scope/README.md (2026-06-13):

# IP5209 LX Scope Capture

These tools automate HANMATEK DOS1104 / OWON-compatible SCPI captures through the local InstrumentKit driver used by the Magnetic Levitation Chess hardware project.

## Safety

Use a short ground spring or very short ground lead if possible.
Scope ground is earth-referenced; connect only to board GND.
Do not connect scope ground to LX, VBAT, VOUT, or any non-ground node.
Start with 1x probes.

Expected signals:

- CH1 CSIN: DC around battery voltage, about 3.7-4.1 V.
- CH2 LX: switching node, may swing from near 0 V to around 5 V with ringing.
- CH3 optional: +5V/VOUT.
- CH4 optional: KEY or VREG.

## Connections

Minimum setup:

```text
CH1 = L2 CSIN / battery side of boost inductor
CH2 = L2 LX side / IP5209 LX switching node
Scope GND = local board GND near U7/IP5209
```

Optional 4-channel setup:

```text
CH3 = +5V/VOUT
CH4 = VREG
```

The workflow now assumes this 4-channel setup. CH4 can still be used for KEY with
`--ch4 key` when explicitly debugging button timing.

## Quick Scope Check

```powershell
python Firmware\tools\scope\ip5209_lx_capture.py --check-scope
```

The default InstrumentKit path is:

```text
C:\Users\lukin\Documents\VS code projects\InstrumentKit\src
```

Override it with `--instrumentkit-src` if needed.

## Capture Commands

```powershell
python Firmware\tools\scope\ip5209_lx_capture.py --mode idle
python Firmware\tools\scope\ip5209_lx_capture.py --mode wake-single --battery-voltage 3.9 --usb-state disconnected
python Firmware\tools\scope\ip5209_lx_capture.py --mode steady-switching --ch3 vout --ch4 vreg
python Firmware\tools\scope\ip5209_lx_capture.py --mode load-test --load-ohms 220 --ch3 vout --ch4 vreg
```

Add optional DMM references when the CSV voltage scale looks suspicious:

```powershell
python Firmware\tools\scope\ip5209_lx_capture.py --rewrite-report-only --ch2-dmm-v 3.87
python Firmware\tools\scope\ip5209_lx_capture.py --mode wake-single --ch3 vout --ch4 vreg --ch2-dmm-v 3.87 --ch3-dmm-v 2.8 --ch4-dmm-v 3.1
```

The report will flag `CSV_SCALE_SUSPECT` when raw waveform means disagree with
DMM references. The analyzer does not silently correct voltages; it reports the
ratio so the scope/driver scaling can be debugged.

Or run the guided workflow:

```powershell
powershell -ExecutionPolicy Bypass -File Firmware\tools\scope\ip5209_capture_workflow.ps1 -BatteryVoltage 3.9 -UsbState disconnected
```

## Outputs

Evidence is written under:

```text
Firmware/docs/ip5209_scope_evidence/
```

The latest markdown report is written to:

```text
Firmware/docs/ip5209_lx_scope_report.md
```

The report is rebuilt from a local capture manifest so captures from separate `idle`, `wake-single`, `steady-switching`, and `load-test` commands remain visible together.

Generated CSV and image captures are ignored by Git by default. Keep selected evidence intentionally only when it is small and useful for a hardware decision.

## Motor Bridge PWM Capture

The current target-board `bringup` firmware enables the timer PWM backend by
default:

```text
APP_MOTOR_PWM_BACKEND_ENABLE=1
```

Build and flash the normal bring-up image before motor captures:

```powershell
powershell -ExecutionPolicy Bypass -File Firmware\tools\build.ps1 -Profile bringup
```

If the shell reports `motor wave-status ... backend=0`, the flashed HEX was
built with the old safe default and cannot generate wave motion.

Probe setup for bridge B:

```text
CH1 = B2 / /PWM_B2
CH2 = B1 / /PWM_B1
Scope GND = board GND
```

Use the same CH1=IN2, CH2=IN1 convention for the other bridges:

```text
Bridge A: CH1 = A2 / /PWM_A2, CH2 = A1 / /PWM_A1
Bridge G: CH1 = G2 / /PWM_G2, CH2 = G1 / /PWM_G1
```

Scope-only setup, leaving the scope running:

```powershell
python Firmware\tools\scope\motor_bridge_pwm_capture.py --mode setup-only
```

Capture a short B forward command through the USB CDC shell:

```powershell
python Firmware\tools\scope\motor_bridge_pwm_capture.py --port COM19 --mode single-forward --duty-permille 50 --duration-ms 300
```

The default acquisition mode is `run-stop`: the script starts the scope, starts
the motor command, stops the scope while the waveform is still active, then saves
the screenshot and waveform. This is more reliable on the DOS1104 than depending
on a single-trigger capture during early bring-up.

To capture and print CH592 PWMX register state while the command is active:

```powershell
python Firmware\tools\scope\motor_bridge_pwm_capture.py --port COM19 --mode single-forward --duty-permille 50 --duration-ms 1000 --pwm-debug --verbose-shell
```

Expected with PWM backend enabled:

- `single-forward`: CH2/B1 pulses at about 20 kHz, CH1/B2 low.
- `single-reverse`: CH1/B2 pulses at about 20 kHz, CH2/B1 low.

If you specifically want to debug the scope trigger path, force single-trigger
mode:

```powershell
python Firmware\tools\scope\motor_bridge_pwm_capture.py --port COM19 --mode single-forward --acquire-mode single-trigger --trigger-sweep SINGle --trigger-channel 2 --trigger-level 1.5 --duration-ms 1000
```

If the command is accepted but both traces remain flat, run the static input
diagnostic before debugging PWM routing:

```text
motor diag-inputs B forward 5000
motor diag-inputs B reverse 5000
motor diag-inputs B brake 5000
```

This command drives the DRV8837 input nets as static GPIO while the bridge is
wake-enabled. For bridge B, `forward` should make B1 high and B2 low; `reverse`
should make B2 high and B1 low; `brake` should make both high. Use this only
for deliberate bridge-output checks.

The same checks can be automated through the scope helper:

```powershell
python Firmware\tools\scope\motor_bridge_pwm_capture.py --port COM19 --mode diag-forward --duration-ms 5000
python Firmware\tools\scope\motor_bridge_pwm_capture.py --port COM19 --mode diag-reverse --duration-ms 5000
python Firmware\tools\scope\motor_bridge_pwm_capture.py --port COM19 --mode diag-brake --duration-ms 5000
```

To capture both directions in one longer sweep:

```powershell
python Firmware\tools\scope\motor_bridge_pwm_capture.py --port COM19 --mode sequence-forward-reverse --duty-permille 50 --duration-ms 300
```

To generate a reference plot for the pseudo-sine diagnostic envelope:

```powershell
python Firmware\tools\scope\motor_sine_reference_plot.py --speed-hz 1 --amplitude-permille 50
```

This writes:

```text
Firmware/docs/motor_sine_reference/motor_sine_reference.png
Firmware/docs/motor_sine_reference/motor_sine_reference.md
```

For the full A/B phase check, use a 4-channel scope setup:

```text
CH1 = A1 / /PWM_A1 / DRV A IN1
CH2 = A2 / /PWM_A2 / DRV A IN2
CH3 = B1 / /PWM_B1 / DRV B IN1
CH4 = B2 / /PWM_B2 / DRV B IN2
Scope GND = board GND only
```

If the probe placement is easier around the PCB, this alternate physical order
is also supported by the script:

```text
CH1 = B2 / /PWM_B2 / DRV B IN2
CH2 = A2 / /PWM_A2 / DRV A IN2
CH3 = B1 / /PWM_B1 / DRV B IN1
CH4 = A1 / /PWM_A1 / DRV A IN1
```

Use `--channel-map ab-physical` for that order.

Do not connect the scope ground to a bridge output. If bridge outputs need to be
checked, probe them relative to board GND in a separate test.

For the current target-board physical hookup:

```text
CH1 = B2
CH2 = A2
CH3 = B1
CH4 = A1
```

Use the paired-overlay mode for reference-style screenshots:

```powershell
python Firmware\tools\scope\motor_bridge_pwm_capture.py --port COM19 --mode sine-scope-plot --sine-target AB --channel-map ab-physical --speed-hz 1 --amplitude-permille 1000 --duration-ms 1200 --acquire-mode single-trigger --trigger-channel 3 --trigger-slope rising --trigger-level 1.5 --trigger-sweep SINGle --scope-arm-mode single --scope-horizontal-offset-div 6 --scope-acquire-mode sample --scope-memory-depth 5000 --trigger-holdoff-ns 100 --pair-overlay --no-waveform --verbose-shell
```

The pair overlay intentionally places channels in two rows:

```text
CH1/CH3 B row = -3.5 div
CH2/CH4 A row = +0.5 div
```

This makes the scope screen look like the reference logic plot: one B row and
one A row, instead of four separate traces.

For continuous clock-divider style diagnostic captures, use
`sine-scope-clkdiv`. The logical shape is the same as `sine-scope-plot`, but it
is repeated for the full command duration so the scope can be stopped while the
waveform is still live:

```powershell
python Firmware\tools\scope\motor_bridge_pwm_capture.py --port COM19 --mode sine-scope-clkdiv --sine-target AB --channel-map ab-physical --fast-clkdiv 1024 --amplitude-permille 1000 --duration-ms 5000 --acquire-mode run-stop --scope-horizontal-offset-div 0 --scope-acquire-mode sample --scope-memory-depth 5000 --pair-overlay --no-waveform --verbose-shell
```

In this diagnostic, `fast_clkdiv` maps directly to the per-sample slot width in
microseconds. One electrical cycle is always 32 slots. A useful sweep is:

```text
fast_clkdiv  slot_us  approx electrical frequency
1024         1024     30.5 Hz
512          512      61.0 Hz
256          256      122 Hz
128          128      244 Hz
64           64       488 Hz
32           32       977 Hz
16           16       1.95 kHz
8            8        3.91 kHz
4            4        7.81 kHz
2            2        15.6 kHz
1            1        31.25 kHz requested, but software GPIO overhead dominates
```

Values below about 4 us are diagnostic stress tests. They are useful for finding
the practical limit of the current bit-banged scope visualization, but they are
not yet a production timing guarantee.

## Hardware-Timed Motor Wave

After the GPIO visualization is proven, build and flash the hardware-timed
motor-wave image:

```powershell
powershell -ExecutionPolicy Bypass -File Firmware\tools\build.ps1 -Profile bringup -ExtraDefine APP_MOTOR_PWM_BACKEND_ENABLE=1
```

Flash:

```text
Firmware\build\bringup\northpole_ch592_bringup.hex
```

The new shell commands are:

```text
motor wave-start <electrical_hz_x1000> <amplitude_permille> [AB|A|B|G|all] [sleep0|sleep1]
motor wave-clkdiv <slot_us> <amplitude_permille> [AB|A|B|G|all] [sleep0|sleep1]
motor wave-dma-a <slot_us> <amplitude_permille> [sleep0|sleep1]
motor wave-dma-hybrid <slot_us> <amplitude_permille> [AB|A|all] [sleep0|sleep1]
motor wave-run <electrical_hz_x1000> <amplitude_permille> <ms> [AB|A|B|G|all] [sleep0|sleep1]
motor wave-status
motor wave-stop
```

This path uses hardware PWM for the bridge inputs and TMR3 only as a duty-update
scheduler:

```text
A1/A2 = TMR2/TMR1 PWM
B1/B2 = PWM9/PWM7 PWM
G1/G2 = PWM5/PWM4 PWM
TMR3  = sine-table sample scheduler
```

Do not confuse the two rates:

```text
20 kHz = PWM carrier frequency
electrical frequency = full A/B sine-table cycle frequency
sample update rate = electrical frequency * 32 samples
```

For example, `wave-clkdiv 256` means one sine-table sample every `256 us`, or
one full electrical cycle every `8.192 ms` (`122 Hz`). It is not a 20 kHz sine
wave. The 20 kHz signal is the carrier inside each duty slot.

Keep `/SLEEP` low for the first scope work:

```text
motor wave-clkdiv 10000 1000 AB sleep0
motor wave-status
motor wave-stop
```

Then compress the sample slot while watching the same physical probe hookup
(`CH1=B2`, `CH2=A2`, `CH3=B1`, `CH4=A1`):

```text
motor wave-clkdiv 1024 1000 AB sleep0
motor wave-stop
motor wave-clkdiv 256 1000 AB sleep0
motor wave-stop
```

At long timebase the duty envelope should match the 32-sample reference shape.
At short timebase each active input should be a 20 kHz PWM carrier, with duty
updated by TMR3. `wave-status` should report `running=1`, `sleep=0`, and an
increasing `ticks` count.

On 2026-06-05, `wave-clkdiv 64 1000 AB sleep0` still produced PWM activity on
the scope but starved the USB CDC shell before `wave-stop` could be acknowledged.
Treat values below `128 us` as stress tests only; the Python wrapper now rejects
them unless `--allow-wave-starvation-risk` is explicitly provided.

That starvation is not caused by continuous debug printing. At `64 us` slots,
TMR3 interrupts at about `15.6 kHz` and updates multiple PWM channels, leaving
too little service time for USB CDC, BLE/TMOS, and the main loop. DMA/offload
would help only if it removes those high-rate duty updates from the CPU. The
current CH59x SDK shows TMR1/TMR2 DMA support, which is promising for A1/A2, but
we have not yet proven an equivalent DMA path for the PWMX channels used by B/G.
No board rework is needed for the next firmware experiments.

First DMA experiment:

```text
motor wave-dma-a 400 1000 sleep0
motor wave-status
motor wave-stop
```

This uses TMR2 DMA for A1 and TMR1 DMA for A2. The firmware expands each
32-sample sine-table duty value into repeated 20 kHz PWM carrier entries, then
loops those buffers in timer DMA. `wave-status` should report `dma=1`,
`targets=A`, nonzero `entries`, and nonzero `repeat`. This intentionally does
not drive B/G yet because the local SDK has not shown a PWMX DMA feeder for
those channels. The full USB/BLE bring-up image keeps the first DMA buffer
small enough to fit CH592 RAM, so start with a 400 us slot. At the current 20 kHz
carrier this uses 8 repeats per sample and 256 DMA entries total.

B/G DMA mapping result:

```text
TMR1/TMR2 expose DMA registers and WCH SDK APIs.
PWMX channels PWM4/PWM5/PWM7/PWM9 do not expose DMA registers or SDK APIs on CH592.
```

So the current B/G mapping experiment is intentionally hybrid:

```text
motor wave-dma-hybrid 400 1000 AB sleep0
motor wave-status
motor wave-stop
```

Expected status:

```text
running=1 targets=AB sleep=0 ... dma=1 dma_supported=A dma_error=0
```

This means A1/A2 are fed by TMR2/TMR1 DMA, while B1/B2 and G1/G2 are still
updated by the sample scheduler because their PWMX block has no documented DMA
feeder. B/G-only targets are rejected by `wave-dma-hybrid`; use `wave-clkdiv`
for B/G-only scheduler tests.

Current hardware-timed scope capture examples:

```powershell
python Firmware\tools\scope\motor_bridge_pwm_capture.py --port COM19 --mode wave-clkdiv --sine-target AB --channel-map ab-physical --fast-clkdiv 1024 --amplitude-permille 1000 --duration-ms 1000 --acquire-mode run-stop --scope-horizontal-offset-div 0 --scope-acquire-mode sample --scope-memory-depth 5000 --pair-overlay --no-waveform --pwm-debug --verbose-shell
python Firmware\tools\scope\motor_bridge_pwm_capture.py --port COM19 --mode wave-clkdiv --sine-target AB --channel-map ab-physical --fast-clkdiv 256 --amplitude-permille 1000 --duration-ms 1000 --acquire-mode run-stop --scope-horizontal-offset-div 0 --scope-acquire-mode sample --scope-memory-depth 5000 --pair-overlay --no-waveform --pwm-debug --verbose-shell
python Firmware\tools\scope\motor_bridge_pwm_capture.py --port COM19 --mode wave-clkdiv --sine-target AB --channel-map ab-physical --display-channels 3 --fast-clkdiv 1024 --amplitude-permille 1000 --duration-ms 300 --stop-during-active-s 0.005 --timebase 20e-6 --acquire-mode run-stop --scope-horizontal-offset-div 0 --scope-acquire-mode sample --scope-memory-depth 5000 --no-waveform --pwm-debug --verbose-shell
python Firmware\tools\scope\motor_bridge_pwm_capture.py --port COM19 --mode wave-dma-a --channel-map ab-physical --display-channels 2,4 --fast-clkdiv 400 --amplitude-permille 1000 --duration-ms 1000 --wave-sleep sleep0 --acquire-mode run-stop --scope-horizontal-offset-div 0 --scope-acquire-mode sample --scope-memory-depth 5000 --pair-overlay --no-waveform --pwm-debug --verbose-shell
python Firmware\tools\scope\motor_bridge_pwm_capture.py --port COM19 --mode wave-dma-hybrid --sine-target AB --channel-map ab-physical --fast-clkdiv 400 --amplitude-permille 1000 --duration-ms 1000 --wave-sleep sleep0 --acquire-mode run-stop --scope-horizontal-offset-div 0 --scope-acquire-mode sample --scope-memory-depth 5000 --pair-overlay --no-waveform --pwm-debug --verbose-shell
```

2026-06-05 first DMA test results:

- `motor wave-dma-a 400 1000 sleep0` passed with `rc=0`, `dma=1`,
  `entries=256`, and `repeat=8`.
- Overview screenshot:
  `Firmware/docs/motor_pwm_scope_evidence/20260605_151945_wave-dma-a_ab_physical_AB.png`.
- A1 carrier zoom screenshot:
  `Firmware/docs/motor_pwm_scope_evidence/20260605_152104_wave-dma-a_ab_physical_AB.png`.
- `motor wave-dma-a 800 1000 sleep0` rejected cleanly with `rc=-3`,
  `dma_error=3`, and `running=0`; this is expected with the RAM-safe 256-entry
  DMA buffers.
- `motor wave-dma-hybrid 400 1000 AB sleep0` passed with `rc=0`, `targets=AB`,
  `dma=1`, `dma_supported=A`, and `dma_error=0`. A1/A2 were DMA-driven while
  B1/B2 were scheduler-updated PWMX.
- `motor wave-dma-hybrid 400 1000 all sleep0` passed with `rc=0`,
  `targets=ABG`, `dma=1`, `dma_supported=A`, and `dma_error=0`. `pwm-debug`
  showed nonzero PWMX data on B/G channels during the run, proving the hybrid
  scheduler path exercises B and G while A remains DMA-driven.

The older `motor_sine_clkdiv_sweep.ps1` workflow below is for the software
scope-visualization commands, not for the hardware-timed `wave-clkdiv` engine.
To run that full divider progression as separate screenshots:

```powershell
powershell -ExecutionPolicy Bypass -File Firmware\tools\scope\motor_sine_clkdiv_sweep.ps1 -Port COM19 -Dividers "1024,512,256,128,64,32,16,8,4,2,1"
```

The wrapper first probes the USB CDC shell with a short
`motor sine-scope-clkdiv 1024 1000 20 AB` command. If the board is still running
older firmware, it stops before configuring the scope and prints:

```text
Target firmware does not support 'motor sine-scope-clkdiv'.
Flash Firmware\build\bringup\northpole_ch592_bringup.hex and rerun this sweep.
```

Use `-SkipPreflight` only when you have already verified the target command by
hand and want to avoid opening the serial port before the scope capture.

For high-rate single-channel captures, reduce the displayed channels. For
example, CH3 is B1 in the current physical hookup and is the default trigger
reference:

```powershell
powershell -ExecutionPolicy Bypass -File Firmware\tools\scope\motor_sine_clkdiv_sweep.ps1 -Port COM19 -Dividers "16,8,4,2,1" -DisplayChannels "3"
```

The DOS1104 sample rate depends on timebase, memory depth, and displayed channel
count. Use the four-channel overview for phase/order. For high-rate timing, use
fewer channels:

```powershell
python Firmware\tools\scope\motor_bridge_pwm_capture.py --port COM19 --mode sine-scope-clkdiv --sine-target AB --channel-map ab-physical --fast-clkdiv 8 --amplitude-permille 1000 --duration-ms 5000 --timebase 50e-6 --display-channels 3 --scope-memory-depth 20000 --acquire-mode run-stop --scope-horizontal-offset-div 0 --scope-acquire-mode sample --pair-overlay --no-waveform --verbose-shell
```

Do not infer pass/fail from the color of the sample-rate text on the scope.
Treat trigger status, visible waveform, numeric sample rate, timebase, and memory
depth as the evidence. Metadata readback is opt-in because deep-memory metadata
queries can wedge this DOS1104 USB protocol if used at the wrong time:

```powershell
python Firmware\tools\scope\motor_bridge_pwm_capture.py ... --read-waveform-metadata --waveform-metadata-source screen
```

Use `--waveform-metadata-source deep` or `--waveform-source deep` only after a
basic screenshot capture is working and the scope USB link is healthy.

Manual shell command for the 4-channel A/B check:

```text
motor sine-demo 1 50 5000 AB
```

Expected behavior:

- A positive half-cycle: A1 has PWM duty, A2 is low.
- A negative half-cycle: A2 has PWM duty, A1 is low.
- B is the same split waveform shifted by 90 degrees, so B1/B2 transition a quarter electrical cycle from A1/A2.
- At `1 Hz`, the 32-sample table holds each step for about 31 ms.
- The waveform is not an analog sine. It is a 20 kHz PWM carrier with a stepped sine duty envelope.

For a non-energizing logic-only phase check, use:

```text
motor sine-diag-inputs 1 5000 AB
```

This drives the same A/B sign sequence as `sine-demo`, but keeps DRV8837
`/SLEEP` low. The bridge outputs should stay disabled. Expected scope behavior
with the 4-channel A/B hookup:

- A positive half-cycle: A1 high, A2 low.
- A negative half-cycle: A2 high, A1 low.
- B is the same binary sign waveform shifted by 90 degrees.
- At `1 Hz`, each table step is about 31 ms, and each half-cycle is about 500 ms.

For a 2-channel automated capture of one bridge or target pair, flash a PWM-enabled image and run:

```powershell
python Firmware\tools\scope\motor_bridge_pwm_capture.py --port COM19 --mode sine-demo --driver A --sine-target A --speed-hz 1 --amplitude-permille 50 --duration-ms 5000
python Firmware\tools\scope\motor_bridge_pwm_capture.py --port COM19 --mode sine-demo --driver B --sine-target B --speed-hz 1 --amplitude-permille 50 --duration-ms 5000
python Firmware\tools\scope\motor_bridge_pwm_capture.py --port COM19 --mode sine-demo --sine-target AB --channel-map ab-physical --speed-hz 1 --amplitude-permille 50 --duration-ms 5000
python Firmware\tools\scope\motor_bridge_pwm_capture.py --port COM19 --mode sine-diag-inputs --sine-target AB --channel-map ab-physical --speed-hz 1 --duration-ms 5000
```

The `driver` channel map records CH1/CH2 only. The `ab-reference` and
`ab-physical` channel maps record CH1..CH4. Use the fixed `single-forward` and
`single-reverse` modes when you need to inspect individual 20 kHz PWM pulses.

Generated evidence is written under:

```text
Firmware/docs/motor_pwm_scope_evidence/
```

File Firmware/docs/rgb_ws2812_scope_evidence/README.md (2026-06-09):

# RGB WS2812 PA14 Bring-Up Evidence

This folder stores local oscilloscope evidence for the Rev-A MVP rework where
MCU PA14 (`/BUSY`) is jumpered to the WS2812 `/LED` data net after the WT2003
BUSY trace is cut.

## Current Result

Firmware image under test:

```text
Firmware/build/bringup/northpole_ch592_bringup.hex
RGB backend: pa14-rework
```

Confirmed over USB CDC:

```text
rgb brightness 24
rgb off
rgb all 255 0 0
rgb all 0 255 0
rgb all 0 0 255
rgb order test
rgb chase 24
```

2026-06-06 Rev-A hardware result:

- WT2003 `BUSY` trace is cut.
- MCU-side PA14/BUSY is jumpered to the WS2812 data input.
- The old PA15 `/LED` trace was also cut/isolated.
- After isolating PA15, the LED data net returned to about 3.3 V and PA14 can
  control all six LEDs.

The PA15 result matters: before the cut, something on the old PA15 path was
pulling the LED data net down. It may have been firmware pin initialization or
another load on that route, but the Rev-A conclusion is simple: do not leave
PA15 and PA14 both connected to the WS2812 data net.

Remaining issue:

- LED0 can stay green after otherwise valid `rgb` commands.
- Scope capture of `rgb off` showed a suspicious leading high/meander before
  the first normal LED frame.
- That points to a first-bit/startup artifact, not to a dead LED chain.

The PA14 GPIO bit-bang experiment was tried as an alternative, but bench
captures showed invalid-looking WS2812 frames and all LEDs could latch white.
The current reference returns to the SPI0-MOSI PA14 backend. The driver now
keeps SPI ownership of PA14 and sends zero-byte reset/latch windows before and
after every WS2812 frame, so any SPI enable artifact is reset away before LED0
data begins.

## Evidence Files

- `20260606_164539_rgb_pa14_green_resetlow_fix.*`: first capture after the
  reset-low fix. Shows the long HIGH before the frame was removed.
- `20260606_164717_rgb_pa14_green_resetlow_fix_overview_100usdiv.*`: frame
  overview.
- `20260606_172424_rgb_pa14_square_1khz_ch2.*`: post-PC-restart 1 kHz PA14 GPIO
  square-wave attempt on scope CH2.
- `20260606_173506_rgb_pa14_square_2hz_ch2.png`: slow PA14 GPIO square-wave
  attempt on scope CH2.

## Interpretation

The expected WS2812 message construction is:

```text
color order: GRB
bit order: MSB first
encoding: 0 = 1000, 1 = 1110
SPI clock: about 3.2 MHz
WS2812 bit cell: about 1.25 us
6 LEDs frame length: about 180 us
reset/latch low: 240 us
```

If LED0 remains green with the SPI0-MOSI PA14 backend, capture the first 50 us
of `rgb off` on the LED data net. The useful pass/fail question is whether the
pre-frame reset window is low all the way until the first normal WS2812 `0` bit,
or whether there is still an extra high pulse before the real frame.

## Required Next Test

Flash:

```text
Firmware/build/bringup/northpole_ch592_bringup.hex
```

Then run:

```text
rgb backend
rgb brightness 24
rgb off
rgb all 255 0 0
rgb all 0 255 0
rgb all 0 0 255
```

Expected:

```text
backend reports spi0-mosi-pa14
LED0 no longer stuck green after rgb off
all six LEDs follow red/green/blue commands
```

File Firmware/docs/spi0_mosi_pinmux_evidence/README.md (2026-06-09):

# SPI0 MOSI Pinmux Evidence

Local scope screenshots and waveform CSV files for the CH592 SPI0 MOSI-only
pinmux experiment go here.

These files are ignored by Git by default. Commit only a small selected evidence
set if it becomes useful for a board-revision decision.

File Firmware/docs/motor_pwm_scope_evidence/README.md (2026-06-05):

# Motor PWM Scope Evidence

Local captures from `Firmware/tools/scope/motor_bridge_pwm_capture.py` are written here.

Generated screenshots, CSV waveform dumps, and JSON-like evidence files are ignored by Git.
Keep only small selected evidence intentionally if it is needed for a hardware decision.

Probe setup used for bridge B validation:

```text
CH1 = B2 / /PWM_B2
CH2 = B1 / /PWM_B1
Scope GND = board GND
```

Use a short ground lead where practical. Start with low duty and short command windows.

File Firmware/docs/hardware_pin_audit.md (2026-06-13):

# Hardware Pin Audit

Generated by `Firmware/tools/extract_kicad_pinmap.py` from the current KiCad files.

- PCB file: `PCB\NorthPoleCircuit_PCB.kicad_pcb` sha256 `80ec7a54917bd0ee`
- Schematic file: `PCB\NorthPoleCircuit_PCB.kicad_sch` sha256 `a72fa80a1a631e47`
- Generated UTC: `2026-06-13T12:34:16+00:00`

## Summary

| Subsystem | Status |
| --- | --- |
| CH592X U2 pin extraction | PASS - all parsed U2 pads are listed below |
| Audio UART | PASS - WT2003 RX/TX are connected to CH592X UART TX/RX |
| Audio BUSY | PASS - /BUSY connects WT2003 to U2 pad 29 |
| Motor inputs | PASS - DRV8837 input nets match A/B/G phase naming |
| DRV8837 sleep control | PASS - PB0 controls all DRV8837 ~SLEEP pins through /SLEEP |
| Hall sensors | PASS - both Hall outputs connect to CH592X pads |
| Touch pads | PASS - all touch pads connect to AIN-capable U2 pads |
| RGB LEDs | PASS - six LEDs form a chain starting at /LED |
| IP5209 control | PASS - SCL/SDA/INT connect between IP5209 and CH592X; I2C passes through R14/R15 debug-share links |
| WCH-LinkE J3 | PASS - debug connector maps TIO/TCK to PB14/PB15 and shares IP5209 I2C through R15/R14 |
| WT2003 USB update J4 | BLOCKED - WT2003 USB update connector does not match expected nets |

## CH592X / U2 Pads

| Pad | Pin function | Net | Firmware role | Connected parsed pads |
| --- | --- | --- | --- | --- |
| 1 | TMR1_1 | /PWM_A2 | DRV8837 A IN2 phase output | U10:IN2_5, A2:1_1 |
| 2 | PB6_2 | /HALL1 | Hall 1 input | U1:OUT_2, HALL1:1_1 |
| 3 | PB0_3 | /SLEEP | DRV8837 global nSLEEP output | U10:~{SLEEP}_7, SLEEP1:1_1, U9:~{SLEEP}_7, U11:~{SLEEP}_7, R16:(none) |
| 4 | VDCID_4 | Net-(U2-VDCIA) | CH592X internal/power support | C2:(none), C1:(none), L1:(none) |
| 5 | VSW_5 | Net-(U2-VSW) | CH592X internal/power support | L1:(none) |
| 6 | VDD33/VIO33_6 | +3.3V | 3.3 V power | D8:VCC_2, C3:(none), U10:VCC_8, D3:VCC_2, J3:VCC_1, C5:(none), C26:(none), C6:(none), U1:VCC_1, D4:VCC_2, U3:VCC_1, C27:(none), U9:VCC_8, U11:VCC_8, D5:VCC_2, C28:(none), +3.3V1:1_1, C25:(none), D6:VCC_2, U8:V_{OUT}_5, D7:VCC_2 |
| 7 | AIN10_7 | /SPD-- | capacitive touch SPD- | TP1:1_1 |
| 8 | AIN11_8 | /RUN | capacitive touch RUN | TP2:1_1 |
| 9 | AIN12_9 | /SPD++ | capacitive touch SPD+ | TP3:1_1 |
| 10 | PA9_10 | /INT | IP5209 interrupt input | U7:L3_2 |
| 11 | SCL_11 | /SWDCK | PB15/SCL shared WCH-LinkE TCK; IP5209 SCL through R14 0 ohm link | J3:SWCLK_4, R14:(none) |
| 12 | SDA_12 | /SWDIO | PB14/SDA shared WCH-LinkE TIO; IP5209 SDA through R15 0 ohm link | J3:SWDIO_2, R15:(none) |
| 13 | TXD1__13 | Net-(U2-PB13) | UART TXD1 to WT2003 RXD via R12 | R12:(none) |
| 14 | RXD1__14 | Net-(U2-PB12) | UART RXD1 from WT2003 TXD via R13 | R13:(none) |
| 15 | UD+_15 | /DP | USB D+ | R6:(none) |
| 16 | UD-_16 | /DN | USB D- | R5:(none) |
| 17 | PWM9_17 | /PWM_B1 | DRV8837 B IN1 phase output | B1:1_1, U11:IN1_6 |
| 18 | PWM7_18 | /PWM_B2 | DRV8837 B IN2 phase output | B2:1_1, U11:IN2_5 |
| 19 | RST_19 | Net-(U2-PB23) | reset/debug support net | SW2:1_1 |
| 20 | PB22_20 | Net-(U2-PB22) | BOOT/user button input | SW1:1_1 |
| 21 | ~{X32MO}_21 | Net-(U2-~{X32MO}) | 32 MHz crystal | Y1:3_3 |
| 22 | X32MI_22 | Net-(U2-X32MI) | 32 MHz crystal | Y1:1_1 |
| 23 | VINTA_23 | Net-(U2-VINTA) | CH592X internal/power support | C4:(none) |
| 24 | ANT_24 | Net-(AE1-A) | BLE antenna feed | AE1:A_1, AE1:A_1, AE1:A_1, AE1:A_1, AE1:A_1, AE1:A_1, AE1:A_1, AE1:A_1, AE1:A_1, AE1:A_1, AE1:A_1, AE1:A_1, AE1:A_1 |
| 25 | VDCIA_25 | Net-(U2-VDCIA) | CH592X internal/power support | C2:(none), C1:(none), L1:(none) |
| 26 | PA4_26 | /HALL2 | Hall 2 input | HALL2:1_1, U3:OUT_2 |
| 27 | AIN1_27 | /MUSIC | capacitive touch MUSIC | TP4:1_1 |
| 28 | PA15_28 | /LED | addressable RGB LED data | D3:DI_4, LED1:1_1 |
| 29 | PA14_29 | /BUSY | WT2003 busy/status input | U6:LED5_20 |
| 30 | PWM5_30 | /PWM_G1 | DRV8837 G IN1 guard output | U9:IN1_6, G1:1_1 |
| 31 | PWM4_31 | /PWM_G2 | DRV8837 G IN2 guard output | U9:IN2_5, G2:1_1 |
| 32 | TMR2_32 | /PWM_A1 | DRV8837 A IN1 phase output | U10:IN1_6, A1:1_1 |
| 33 | GND_33 | GND | ground | C29:(none), D8:GND_3, SW2:2_2, C3:(none), C9:(none), R8:(none), U10:GND_4, U10:GND_9, D3:GND_3, C13:(none), SW3:1_1, SW3:1_1, J3:GND_5, C12:(none), BAT_PAD1:(none), C5:(none), C26:(none), Y1:G_2, Y1:G_4, C8:(none), J4:GND_5, R1:(none), U7:AGND_7, U7:PGND_12, U7:LIGHT_22, U7:GND_25, C6:(none), C21:(none), C30:(none), U1:GND_3, U1:GND_5, C4:(none), R11:(none), D4:GND_3, C11:(none), U3:GND_3, U3:GND_5, C27:(none), U9:GND_4, U9:GND_9, U11:GND_4, U11:GND_9, C15:(none), D5:GND_3, D1:A1_1, U6:AGND_13, U6:GND_17, C28:(none), C25:(none), C2:(none), C19:(none), J1:GND_A1, J1:GND_A12, J1:GND_B1, J1:GND_B12, J1:SHIELD_SH, J1:SHIELD_SH, J1:SHIELD_SH, J1:SHIELD_SH, C18:(none), C1:(none), C14:(none), C17:(none), GND3:1_1, D6:GND_3, AE1:Shield_2, AE1:Shield_2, GND2:1_1, C31:(none), U5:GND_4, R2:(none), C23:(none), C24:(none), D2:A1_1, C20:(none), C10:(none), C22:(none), SW1:2_2, R16:(none), U8:V_{SS}_2, D7:GND_3 |

### Critical Firmware GPIO Mapping Notes

- `/PWM_A2` is U2 pad 1, `PA10/TMR1`. Firmware must use the non-remapped `TMR1` signal on `PA10`.
- Do not use `PB10/TMR1_` for `/PWM_A2`; on CH592X `PB10` is also `UD-` and is connected to USB `/DN` on U2 pad 16.
- `/PWM_A1` is U2 pad 32, `PA11/TMR2`. Do not remap `TMR2` to `PB11`, because `PB11` is USB `/DP` on U2 pad 15.

## Audio UART Check

| Signal | MCU | WT2003 | Status |
| --- | --- | --- | --- |
| MCU TX to WT RX | U2 pad 13 TXD1__13 Net-(U2-PB13) | U6 pad 11 RXD_11 /RX1 | PASS - series resistor R12 (2.7kohm) |
| MCU RX from WT TX | U2 pad 14 RXD1__14 Net-(U2-PB12) | U6 pad 23 TXD_23 /TX1 | PASS - series resistor R13 (2.7kohm) |
| WT BUSY | U2 pad 29 /BUSY | U6 pad 20 /BUSY | PASS |

Conclusion: audio UART is usable. The TX/RX nets are routed through detected series resistors, so direct net names differ but the signal path exists.

## DRV8837 Motor Driver Mapping

| Driver | Ref | IN1 net | IN2 net | ~SLEEP net | Status |
| --- | --- | --- | --- | --- | --- |
| A | U10 | /PWM_A1 | /PWM_A2 | /SLEEP | PASS |
| B | U11 | /PWM_B1 | /PWM_B2 | /SLEEP | PASS |
| G | U9 | /PWM_G1 | /PWM_G2 | /SLEEP | PASS |

PB0 controls global DRV8837 `~SLEEP` on `/SLEEP`. Firmware idle and fault state must drive `/SLEEP` low and all IN pins low/coast.

## Hall Sensors

| Ref | OUT net | MCU pad | Status |
| --- | --- | --- | --- |
| U1 | /HALL1 | 2 | PASS |
| U3 | /HALL2 | 26 | PASS |

## Capacitive Touch Pads

| Ref | Value | Net | MCU pad | MCU function | Status |
| --- | --- | --- | --- | --- | --- |
| TP1 | SPD- | /SPD-- | 7 | AIN10_7 | PASS |
| TP2 | RUN | /RUN | 8 | AIN11_8 | PASS |
| TP3 | SPD+ | /SPD++ | 9 | AIN12_9 | PASS |
| TP4 | MUSIC | /MUSIC | 27 | AIN1_27 | PASS |

## RGB LED Chain

| Order | Ref | DI net | DO net |
| --- | --- | --- | --- |
| 0 | D3 | /LED | Net-(D3-DO) |
| 1 | D5 | Net-(D3-DO) | Net-(D5-DO) |
| 2 | D7 | Net-(D5-DO) | Net-(D4-DI) |
| 3 | D4 | Net-(D4-DI) | Net-(D4-DO) |
| 4 | D6 | Net-(D4-DO) | Net-(D6-DO) |
| 5 | D8 | Net-(D6-DO) | unconnected-(D8-DO-Pad1) |

## IP5209 Power/Charge Interface

| Signal | IP5209 pad/net | MCU pad/net | Path | Status |
| --- | --- | --- | --- | --- |
| SDA | SDA_1//SDA | pad 12//SWDIO | series resistor R15 (0ohm) | PASS |
| SCL | SCL_24//SCL | pad 11//SWDCK | series resistor R14 (0ohm) | PASS |
| INT | L3_2//INT | pad 10//INT | direct net | PASS |

IP5209 I2C: PASS via R14/R15 0 ohm debug-share links when the table above shows PASS for SCL and SDA.

Warning: when WCH-LinkE debug is active, PB15/PB14 are used as debug pins. IP5209 I2C should not be expected to work at the same time. If debug communication is unreliable, remove R14/R15 or leave them unpopulated temporarily.

## WCH-LinkE Debug Connector J3

| Item | Expected | Observed | Status |
| --- | --- | --- | --- |
| J3 pin 1 | +3.3V | +3.3V | PASS |
| J3 pin 2 | /SWDIO | /SWDIO | PASS |
| J3 pin 3 | (none) | unconnected-(J3-~{RESET}-Pad3) | PASS |
| J3 pin 4 | /SWDCK | /SWDCK | PASS |
| J3 pin 5 | GND | GND | PASS |
| J3 pin 6 | (none) | unconnected-(J3-SWO-Pad6) | PASS |
| R14 | /SCL <-> /SWDCK 0 ohm | /SCL, /SWDCK | PASS |
| R15 | /SDA <-> /SWDIO 0 ohm | /SDA, /SWDIO | PASS |

Intended connection: CH592 PB14 / SDA / WCH TIO / SWDIO -> R15 0 ohm -> IP5209 SDA. CH592 PB15 / SCL / WCH TCK / SWDCK -> R14 0 ohm -> IP5209 SCL.

## WT2003 USB Update Connector J4

| Item | Expected | Observed | Status |
| --- | --- | --- | --- |
| J4 pin 1 | +5V | unconnected-(J4-VCC-Pad1) | BLOCKED |
| J4 pin 2 | /DP2 | /DP2 | PASS |
| J4 pin 3 | (none) | unconnected-(J4-~{RESET}-Pad3) | PASS |
| J4 pin 4 | /DM2 | /DM2 | PASS |
| J4 pin 5 | GND | GND | PASS |
| J4 pin 6 | (none) | unconnected-(J4-SWO-Pad6) | PASS |
| U6 D- | /DM2 | /DM2 | PASS |
| U6 D+ | /DP2 | /DP2 | PASS |

J4 is not ARM SWD. Current PCB is BLOCKED for WT2003 USB update: J4 pin 1 is not on +5V, so only D+/D-/GND are present. Do not use J4 for WT2003 USB update until +5V is routed or a rework power path is documented.

## Explicit No-Connect Or Isolated U2 Nets

| Pad | Function | Net | Reason |
| --- | --- | --- | --- |

## Relevant Schematic Labels Observed

`BUSY`, `DM2`, `DN`, `DP`, `DP2`, `HALL1`, `HALL2`, `INT`, `LED`, `MUSIC`, `PWM_A1`, `PWM_A2`, `PWM_B1`, `PWM_B2`, `PWM_G1`, `PWM_G2`, `RUN`, `RX1`, `SCL`, `SDA`, `SLEEP`, `SPD++`, `SPD--`, `SWDCK`, `SWDIO`, `TX1`

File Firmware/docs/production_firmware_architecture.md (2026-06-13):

# Production Firmware Architecture Proposal

The current firmware is a successful bring-up/MVP image, not a production
architecture. It intentionally contains shell commands, scope diagnostics,
register pokes, raw motor controls, and bench-only recovery paths. The next
milestone should split this into a minimal production application plus separate
test images.

## Goals

Production firmware should:

- Start deterministically from reset.
- Keep all outputs safe until the app intentionally enters RUN.
- Run the sled, RGB, audio, touch, Hall, and BLE service with bounded latency.
- Avoid arbitrary raw hardware commands.
- Leave meaningful RAM and stack margin.
- Keep diagnostics available through separate factory/bring-up builds.

It should not carry the full bench shell into the final demo/product image.

## Proposed Build Profiles

| Profile | Purpose | Keep |
|---|---|---|
| `bringup` | Hardware diagnosis | Full USB CDC shell, raw I2C/audio/motor/RGB commands, scope hooks |
| `mvp-demo` | Current Rev-A hand-reworked demo | USB CDC shell, selected debug prints, demo scene, motion/RGB/audio |
| `factory-test` | Board production test | Small command set: pins, RGB, audio, Hall/touch, motor-safe pulse, version |
| `production` | Final behavior | Demo app, BLE control/status if needed, touch controls, audio/RGB/motion |

The current `Firmware\tools\build_mvp_demo.ps1` should remain the bench MVP
wrapper. Add a future `Firmware\tools\build_production.ps1` with stricter
defines.

## Production Runtime Model

Keep the current no-RTOS model:

```text
interrupts:
  BLE/TMOS timing
  motor control update
  timer/PWM/DMA peripherals
  optional USB only in non-production

foreground loop:
  input scan
  demo state machine
  audio queue
  RGB scene scheduler
  BLE service/status update
  safety/fault handling
```

There is no task-switching overhead. The main constraints are interrupt
latency, foreground-loop blocking time, and RAM.

## Production Modules

### Safety Manager

Responsibilities:

- Own the global fault mask.
- Force motor off and `/SLEEP` low on faults.
- Bound run duration.
- Clamp motor duty, guard duty, and speed.
- Provide one emergency-stop path callable from touch/BLE/internal faults.

Production should not allow raw motor writes that bypass safety.

### Motion Engine

Use the proven smooth engine:

```text
sine table: 256 phase positions
control update: 8000 Hz baseline
carrier: 40000 or 100000 Hz after final tuning
A/B amplitude: up to 1000 permille for Rev-A sled
guard: fixed direction, default duty around 600 permille
```

Production commands should be high level:

```text
start
stop
speed up/down
set scene speed
set intensity within allowed bounds
```

Do not expose:

```text
raw phase
raw PWM pin
raw duty per bridge input
unbounded duration
unbounded carrier/update changes
```

### Input Manager

Touch behavior:

- `RUN`: start/stop; long press emergency stop.
- `SPD+`: increase signed speed.
- `SPD-`: decrease signed speed, cross through zero into reverse.
- `MUSIC`: next/start music depending on app state.

Hall behavior:

- Use only after Rev-B footprint is corrected or Rev-A manual rework is known.
- Production Hall use should be debounced and fail-safe.
- Hall is not a hard dependency for the current MVP profile.

### RGB Manager

Use the PA14/SPI0 MOSI WS2812 backend for the current Rev-A rework.

Production should keep a small set of effects:

- `stars` default.
- `rainbow` for blended-color visual.
- `breathe`.
- `strobe` only if desired.
- `off`.

Avoid updating WS2812 too frequently during aggressive motor motion. The current
SPI-assisted implementation blocks for under 1 ms, but a badly timed motor ISR
gap can corrupt WS2812 frames. If this remains visible in production, choose one:

- reduce RGB frame rate;
- schedule RGB updates during low-motion windows;
- temporarily mask/pause motor updates during the short LED frame only if the
  motion disturbance is acceptable;
- implement SPI DMA for RGB;
- move RGB to a small external LED controller in a later hardware revision.

### Audio Manager

Keep the WT2003 queue non-blocking.

Production should expose only:

- volume set within `0..31`;
- play known track index/name;
- stop;
- next/previous if needed.

Remove or compile out:

- raw WT2003 command;
- format external flash;
- verbose byte dumps.

### BLE Service

Production BLE should be small and explicit.

Suggested characteristics:

- identity/version;
- status summary;
- command/control with a limited command enum;
- optional counters/faults.

Do not expose raw motor or raw I2C over BLE.

If BLE is not needed for the demo, production can keep advertising/status only
or disable BLE entirely in a special show build. That decision has a large RAM
impact because the WCH BLE heap is `6144 B`.

## Remove From Production

Compile out or move to `bringup`/`factory-test`:

- USB CDC shell and its 2 KB TX ring.
- Shell command parser and report buffers.
- Raw `i2c read/write/scan` except maybe a factory probe.
- IP5209 full register dump and diagnostic bit writes.
- `hall watch`, `touch watch`, and long verbose polling output.
- RGB walk/order/scope diagnostic commands.
- Raw motor wave, static PWM, sine-scope, DMA debug, pin-level commands.
- Audio raw command and flash format command.
- Scope automation dependencies from firmware behavior.
- Long descriptive help text.

Keep docs and tools in the repository; just do not compile the bench surface into
the production image.

## Example Production Defines

This is a starting point, not final code:

```text
APP_BUILD_PROFILE_NAME="production"
APP_FIRMWARE_VERSION="0.2.0-production"
APP_USB_CDC_SHELL_ENABLE=0
APP_DEMO_SCENE_ENABLE=1
APP_DEMO_USB_POWER_ONLY=1
APP_RGB_WS2812_USE_SPI0_MOSI_PA14=1
APP_MOTOR_PWM_BACKEND_ENABLE=1
APP_MOTOR_PWM_MAX_DUTY_PERMILLE=1000
APP_MOTOR_WAVE_TABLE_SIZE=256
APP_MOTOR_CONTROL_UPDATE_HZ=8000
APP_MOTOR_PWM_CARRIER_HZ=40000
APP_MOTION_RAMP_ENABLE=1
APP_MOTION_TOUCH_CONTROL_ENABLE=1
APP_DEMO_DEFAULT_AUDIO_VOLUME=31
APP_DEMO_DEFAULT_RGB_BRIGHTNESS=24
APP_DEMO_DEFAULT_RGB_EFFECT=1
APP_DEMO_DEFAULT_SPEED_HZ_X1000=8000
APP_DEMO_DEFAULT_AMPLITUDE_PERMILLE=1000
APP_DEMO_DEFAULT_GUARD_MODE=<latest proven polarity>
APP_DEMO_DEFAULT_GUARD_DUTY_PERMILLE=600
```

Add new compile gates as needed:

```text
APP_DIAG_COMMANDS_ENABLE=0
APP_RAW_MOTOR_COMMANDS_ENABLE=0
APP_RAW_I2C_COMMANDS_ENABLE=0
APP_AUDIO_FORMAT_COMMAND_ENABLE=0
APP_RGB_TEST_COMMANDS_ENABLE=0
APP_VERBOSE_DEMO_LOG_ENABLE=0
APP_FACTORY_TEST_COMMANDS_ENABLE=0
```

## RAM Targets

The current MVP image uses about `25580 / 26624 B` by linker accounting.
Production should not ship this close to the limit.

Targets:

```text
static/linker RAM <= 21 KB
static/linker RAM <= 80%
measured stack margin >= 2 KB after worst-case demo run
no unbounded shell/log buffers in production
```

Expected first savings:

- USB CDC shell off: about `2.6 KB` data plus possible `.highcode`.
- Remove shell/parser/debug buffers: several hundred bytes.
- Remove WCH SimpleProfile if not used: a few hundred bytes.
- Convert motor DMA tables to 16-bit if safe: about `1 KB`.

See `Firmware/docs/ram_usage_audit.md` for the detailed breakdown.

## Runtime Instrumentation Before Stripping

Before removing diagnostics, add one compact profiler/status path in MVP:

```text
runtime status
```

Suggested fields:

```text
loop_count
loop_hz
max_loop_gap_us
motor_tick_count
motor_missed_update_count
rgb_frame_count
rgb_last_status
audio_queue_depth
audio_last_error
ble_poll_count
usb_tx_busy_count
```

Once production is stable, keep only a minimal internal counter set and expose it
through BLE or a factory build.

## Migration Plan

1. Freeze the current MVP demo as the bench reference.
2. Add runtime loop/missed-update instrumentation to MVP.
3. Create `build_production.ps1` with USB CDC disabled and diagnostics compiled
   out.
4. Verify production image still:
   - boots safely;
   - advertises or intentionally does not advertise;
   - responds to touch controls;
   - starts/stops motion;
   - plays audio;
   - runs RGB effect;
   - faults safe on emergency stop.
5. Measure RAM again and record in `ram_usage_audit.md`.
6. Only after that, tune BLE heap and motor DMA table size.

## Design Rule

Bring-up firmware is allowed to be convenient. Production firmware must be
boring: few states, few commands, bounded timing, bounded memory, and one clear
safe-off path.

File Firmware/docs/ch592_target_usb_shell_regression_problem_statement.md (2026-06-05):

# CH592 Target Board USB CDC / Bring-Up Regression Problem Statement

Date: 2026-05-26

## Short Summary

North Pole CH592 target hardware can run BLE and USB CDC with an older dev-board-smoke bring-up image, but current target-oriented bring-up images either break USB enumeration or enumerate USB CDC without any shell response.

We need help isolating why the target-mode firmware stops responding, and whether the safest route is to restart from the last known-good firmware configuration and add target-board behavior in small increments.

## Hardware

- MCU: WCH CH592X BLE MCU
- Board: North Pole BLE/Audio final JLCPCB target board
- Programming/debug: WCH-LinkE / WCH-LinkUtility / MounRiver path
- USB: CH592 native USB CDC shell on target board USB-C
- BLE: CH592 BLE advertising verified with nRF Connect
- Relevant target nets:
  - USB D+ = U2 pad 15 `/DP`
  - USB D- = U2 pad 16 `/DN`
  - DRV8837 global `/SLEEP` = U2 pad 3 PB0
  - RGB WS2812 data = U2 pad 28 PA15 `/LED`
  - Motor A IN2 = U2 pad 1 PA10/TMR1 `/PWM_A2`

## Known-Good Firmware Artifact

This HEX works on the target board:

```text
Firmware/build/bringup_dev_ble_diag_usb_cdc_smoke/northpole_ch592_bringup.hex
```

Observed behavior:

- Windows enumerates USB CDC as COM19.
- USB shell responds to commands.
- BLE advertises as `NorthPole BLE`.
- nRF Connect can see/read custom diagnostic service `0xFD90`.
- RGB LEDs stay off.
- Example shell responses observed:

```text
version=0.1.0-bringup profile=bringup board=north-pole-ble-audio-current-pcb ...
fault_mask=0x00000000
settings valid=1 version=1 volume=6 brightness=8 scene=0 motor_limit=25 demo=0 crc=0x325a flash=0
audio validation=HARDWARE_VALIDATION_PENDING hw=HW_NOT_TESTED ...
```

This image was built as a dev-board / BLE diagnostic smoke profile, so many target-board hardware reads were intentionally disabled:

```text
hall input reads disabled in dev-board smoke build
touch reads disabled in dev-board smoke build
i2c commands disabled in dev-board smoke build
ip5209 commands disabled in dev-board smoke build
```

## Known-Bad Firmware Artifact

This HEX is bad on the target board:

```text
Firmware/build/bringup/northpole_ch592_bringup.hex
```

Observed behavior before recent pin fix:

- Windows shows USB descriptor failure / device not recognized.
- All 6 WS2812 LEDs emit white.
- Reflashing the known-good smoke image restores USB CDC and LEDs off.

## Important Bug Already Found

The firmware had a serious pin mapping bug:

- U2 pad 1 `/PWM_A2` is `PA10/TMR1`, not `PB10/TMR1_`.
- `PB10` is U2 pad 16 and is USB D- `/DN`.

Old firmware code incorrectly mapped pad 1/TMR1 to PB10 and could configure or drive USB D- as a motor output. This plausibly explains the original USB descriptor failures.

Fix applied in:

```text
Firmware/northpole_ch592_bringup/APP/northpole/ch592_board_port.c
Firmware/tools/extract_kicad_pinmap.py
Firmware/docs/hardware_pin_audit.md
```

Key fixed behavior:

```c
case 1: hw->port = HW_PORT_A; hw->mask = bTMR1; break; /* /PWM_A2 */
GPIOPinRemap(DISABLE, RB_PIN_TMR1); /* Keep TMR1 on PA10; PB10 is USB D-. */
```

After this fix, the smaller ladder images no longer obviously kill USB enumeration, but the USB shell still does not respond.

## Current Failure After Pin Fix

Target ladder images were built to isolate the failure:

```text
Firmware/build/target_ladder/
```

Important images:

```text
00_dev_smoke_reference
01_core_no_target_gpio
02aa_early_safe_inputs_only
02ab_early_safe_sleep_only
02ac_early_safe_rgb_only
02a_early_safe_sleep_rgb_only
02b_board_safe_sleep_rgb_only
02_safe_pins_only
03_power_i2c_only
...
```

The user flashed at least two of the new `02*` ladder images after the pin fix and still saw:

- USB CDC COM port appears.
- Sending `version\r\n` produces no response.
- Automated smoke test can open COM19 but all commands timeout.

Automated test command:

```powershell
python Firmware\tools\usb_shell_smoke_test.py --port COM19 --profile target --timeout 2
```

Observed output:

```text
>>> version
<no response>
>>> status
<no response>
...
USB CDC smoke test failed: no response for version, status, pins verify, safe check, faults, settings show, rgb off, motor off, audio status, ip5209 status
```

Follow-up split on 2026-05-26:

- `00_dev_smoke_reference` still works on the target board.
- `01_core_no_target_gpio` already fails on the target board.

Therefore the failure is not caused by target GPIO safe states or target peripheral drivers. It is caused by a startup/build-mode difference between dev-smoke mode and target-core mode.

## Root Cause Identified: WCH DEBUG/PRINT UART1 Path

The build script previously compiled all profiles with:

```text
-DDEBUG=1
```

In the WCH SDK, `PRINT()` is active whenever `DEBUG` is defined, and `_write()` routes `printf()` to the selected debug UART:

```c
#ifdef DEBUG
int _write(int fd, char *buf, int size)
{
    ...
#if DEBUG == Debug_UART1
        while(R8_UART1_TFC == UART_FIFO_SIZE);
        R8_UART1_THR = *buf++;
#endif
}
#endif
```

The working dev-smoke startup initializes UART1 before BLE init:

```c
GPIOA_SetBits(bTXD1);
GPIOA_ModeCfg(bTXD1, GPIO_ModeOut_PP_5mA);
UART1_DefInit();
PRINT("%s\n", VER_LIB);
```

The failing target-core startup does not initialize UART1 because UART1 is routed to the WT2003 audio chip on the target board. However, `peripheral.c` still contains many WCH `PRINT()` calls, including BLE state callbacks:

```c
PRINT("Initialized..\n");
PRINT("Advertising..\n");
PRINT("Connected..\n");
```

This is the confirmed target-core failure path: target-core firmware left WCH `PRINT()` enabled but removed the WCH UART1 debug startup, so WCH BLE state logging could block or disturb startup before the USB shell responded.

Two new diagnostic ladder images were added:

```text
Firmware/build/target_ladder/01a_core_no_target_gpio_no_wch_debug/northpole_ch592_bringup.hex
Firmware/build/target_ladder/01b_core_no_target_gpio_evt_uart_startup/northpole_ch592_bringup.hex
```

Observed interpretation:

- `01a_core_no_target_gpio_no_wch_debug` works.
- `01b_core_no_target_gpio_evt_uart_startup` works.
- Therefore the correct target-board fix is to disable WCH `DEBUG`/`PRINT()` for normal target builds.
- The EVT UART startup path is only acceptable for dev-board/debug-isolation builds because target UART1 is routed to WT2003 audio.

`Firmware/tools/build.ps1` was updated so normal `bringup` and `production` target builds no longer define WCH `DEBUG` by default. WCH `DEBUG` remains enabled automatically for WCH EVT baseline and dev-board smoke builds, and can be explicitly enabled with `-WchDebugPrint` for one-off experiments.

## Key Code Paths

Target startup:

```text
Firmware/northpole_ch592_bringup/APP/peripheral_main.c
```

Target mode does:

```c
SetSysClock(CLK_SOURCE_PLL_60MHz);
northpole_ch592_early_safe_pins();        // if enabled
CH59x_BLEInit();
HAL_Init();
GAPRole_PeripheralInit();
Peripheral_Init();
app_bringup_init();
Main_Circulation();
```

Main loop:

```c
while (1) {
    TMOS_SystemProcess();
    app_bringup_poll();
}
```

USB shell init/poll:

```text
Firmware/northpole_ch592_bringup/APP/northpole/usb_cdc_shell.c
Firmware/northpole_ch592_bringup/APP/northpole/shell.c
Firmware/northpole_ch592_bringup/APP/northpole/app_bringup.c
```

`app_bringup_init()` initializes:

```c
timebase_init();
log_init(LOG_LEVEL_INFO);
fault_init();
board_init_safe_pins();       // target mode if enabled
usb_cdc_shell_init();
LOG_INFO("bring-up profile active\r\n");
settings_init();
...
ble_service_init();
shell_init();
```

`app_bringup_poll()` does:

```c
shell_poll();
usb_cdc_shell_poll();
...
ble_service_poll();
```

## Dev Smoke Path Difference

The known-good smoke path defines one or both of:

```text
APP_DEV_BOARD_BLE_SMOKE=1
APP_DEV_BOARD_BRINGUP_APP_SMOKE=1
```

This causes:

- NorthPole target safe pins are skipped:

```c
#define APP_DEV_BOARD_SKIP_NORTHPOLE_SAFE_PINS \
    (APP_DEV_BOARD_BLE_SMOKE || APP_DEV_BOARD_BLE_BROADCASTER_SMOKE || APP_DEV_BOARD_BRINGUP_APP_SMOKE)
```

- WCH EVT-style UART startup remains present:

```c
#if APP_DEV_BOARD_BLE_SMOKE || APP_DEV_BOARD_BLE_BROADCASTER_SMOKE || APP_DEV_BOARD_BRINGUP_APP_SMOKE
    GPIOA_SetBits(bTXD1);
    GPIOA_ModeCfg(bTXD1, GPIO_ModeOut_PP_5mA);
    UART1_DefInit();
    PRINT("%s\n", VER_LIB);
#endif
```

- Target peripherals are skipped in `app_bringup_init()`.

The target mode removes the WCH EVT-style debug UART init and applies target pin initialization.

## Current Hypotheses

1. The original full-target USB failure was caused by the PA10/PB10 pin mapping bug. That part is likely fixed.
2. The current "COM port but no shell response" is probably not a Windows driver issue, because the known-good HEX responds on the same board and COM port.
3. The new failure likely happens after USB enumerates but before or inside the main loop/shell polling path.
4. Possible causes:
   - `app_bringup_init()` is blocking or faulting before `shell_init()`.
   - `LOG_INFO()` via USB CDC blocks or behaves differently when USB is configured early.
   - Target-mode BLE/GATT/service path or TMOS startup differs from the proven dev smoke path.
   - Early safe GPIO still touches a pin that affects CH592 USB/BLE/runtime, even after the PB10 fix.
   - Stack/RAM pressure or link/order difference changed behavior.
   - Interrupt priority / USB IRQ / BLE interaction differs between target mode and smoke mode.

## Suggested Next Debug Strategy

Restart from the known-good behavior and move forward one small step at a time.

### Step 1: Prove the current source can still reproduce known-good behavior

Flash this current-source rebuild:

```text
Firmware/build/target_ladder/00_dev_smoke_reference/northpole_ch592_bringup.hex
```

Expected:

- USB shell responds.
- BLE advertises.
- LEDs stay off.

If this fails, current source no longer reproduces the known-good image and we should diff current source against the source state that produced:

```text
Firmware/build/bringup_dev_ble_diag_usb_cdc_smoke/northpole_ch592_bringup.hex
```

### Step 2: Prove target mode with all target GPIO/peripherals disabled

Flash:

```text
Firmware/build/target_ladder/01_core_no_target_gpio/northpole_ch592_bringup.hex
```

Expected:

- USB shell responds.
- BLE advertises.
- No target GPIO safe init.

If `00` works but `01` fails, the bug is not a hardware pin side effect. It is in target-mode startup, compile-time mode differences, BLE/GATT, or app init ordering.

### Step 3: Add one target safe action at a time

Only if `01` works:

```text
Firmware/build/target_ladder/02aa_early_safe_inputs_only/northpole_ch592_bringup.hex
Firmware/build/target_ladder/02ab_early_safe_sleep_only/northpole_ch592_bringup.hex
Firmware/build/target_ladder/02ac_early_safe_rgb_only/northpole_ch592_bringup.hex
```

Expected:

- USB shell still responds.
- `/SLEEP` low when enabled.
- RGB data low when enabled.

If one of these breaks the shell, inspect that exact GPIO config.

### Step 4: Only then add target peripherals

Do not proceed to I2C, touch, Hall, RGB writes, audio, or motor until the shell responds reliably.

## Questions For Review

1. Is there any CH592 USB requirement that can be violated by configuring PA9, PA14, PB12, PB13, PB0, or PA15 before `CH59x_BLEInit()` / `HAL_Init()`?
2. Can `LOG_INFO()` after `usb_cdc_shell_init()` deadlock or starve the main loop if USB is configured but host is not draining IN packets?
3. Does WCH CH592 require a specific order for `SetSysClock`, USB device init, BLE init, and HAL init?
4. Is the custom USB CDC implementation safe to use together with BLE/TMOS, or does it miss a WCH-required interrupt/DMA detail?
5. Could the dev smoke image work only because `APP_DEV_BOARD_BRINGUP_APP_SMOKE` skips target GATT/control paths or target subsystem references?
6. Is RAM usage close enough to the CH592 limit that small build-mode differences can corrupt USB/BLE state?

## Files To Inspect

```text
Firmware/northpole_ch592_bringup/APP/peripheral_main.c
Firmware/northpole_ch592_bringup/APP/peripheral.c
Firmware/northpole_ch592_bringup/APP/northpole/app_bringup.c
Firmware/northpole_ch592_bringup/APP/northpole/usb_cdc_shell.c
Firmware/northpole_ch592_bringup/APP/northpole/shell.c
Firmware/northpole_ch592_bringup/APP/northpole/ch592_board_port.c
Firmware/northpole_ch592_bringup/APP/include/app_config.h
Firmware/northpole_ch592_bringup/APP/include/board_pins_autogen_notes.h
Firmware/tools/build.ps1
Firmware/tools/build_target_ladder.ps1
Firmware/docs/hardware_pin_audit.md
```

## Current Practical Recommendation

Do not keep trying the full target image.

Use the old known-good HEX as the behavioral baseline, then make the source reproduce that baseline. Once current source can reliably produce a working `00_dev_smoke_reference`, add target-mode behavior one step at a time and stop at the first image that loses shell response.

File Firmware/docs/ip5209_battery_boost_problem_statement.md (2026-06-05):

# IP5209 Battery Boost Bring-Up Problem Statement

Date: 2026-05-27

## Board

- Project: North Pole BLE/Audio Card
- MCU: WCH CH592X
- PMIC: IP5209T
- 3.3 V regulator: ME6211C33M5
- Battery: 1-cell LiPo, measured about 3.9 V
- Firmware: `Firmware/build/bringup/northpole_ch592_bringup.hex`

## Relevant Power Path

From the KiCad PCB:

- Battery positive net: `Net-(U7-VBAT)`
- IP5209:
  - U7 pin 9 `VBAT` -> `Net-(U7-VBAT)`
  - U7 pin 10 `CSIN` -> `Net-(U7-CSIN)`
  - U7 pin 11 `CSIN_S` -> `Net-(U7-CSIN)`
  - U7 pins 13/14/15 `LX`
  - U7 pins 16/17 `VOUT` -> `/VOUT`
  - U7 pin 3 `VREG` -> `/VREG`
  - U7 pin 8 `KEY` -> `Net-(U7-KEY)`
- R9: 10 milliohm current sense resistor between `Net-(U7-CSIN)` and `Net-(U7-VBAT)`.
- L2: 1 uH boost inductor between `Net-(U7-CSIN)` and `Net-(C16-Pad1)` / IP5209 LX-side switching node.
- L1: 10 uH inductor for the CH592 internal DC/DC path, not the IP5209 boost inductor.
- ME6211 input is fed from IP5209 `/VOUT` / nominal +5 V rail.
- ME6211 output is board `+3.3V`.

## Known Good USB-Powered Behavior

With USB connected and battery absent:

- Board boots.
- CH592 USB CDC shell works.
- BLE advertises as `NorthPole BLE`.
- After `i2c release-debug`, IP5209 ACKs at 7-bit address `0x75`.
- `i2c scan` reports `0x75`.
- `ip5209 probe` returns `rc=0`.
- `ip5209 dump` works.

Example:

```text
i2c release-debug
i2c scan
i2c found=1 0x75
ip5209 probe
ip5209 probe addr=0x75 rc=0
```

## Battery-First Behavior

With battery connected first, USB disconnected:

Initial measurements before pressing SW3:

```text
BAT+ to GND          ~3.9 V
U7 VBAT to GND      ~3.9 V
U7 CSIN to GND      ~3.9 V
U7 CSIN_S to GND    ~3.9 V
U7 VREG to GND      ~0.2 V
+5V/VOUT to GND     ~1.1 V
+3.3V to GND        ~1.1 V
SCL to GND          ~0.2 V
SDA to GND          ~0.2 V
/INT to GND         ~0.0 V
KEY to GND          ~0.45 V
```

This indicates the battery voltage reaches U7, but IP5209 `VREG` does not start by itself.

After pressing SW3 briefly:

```text
U7 VREG to GND      ~3.1 V
U7 VOUT pins 16/17  ~2.8 V
+5V rail            ~2.8 V
ME6211 input        ~2.8 V
ME6211 output/+3.3V ~2.8 V
```

So SW3 wakes the IP5209 internal LDO, but the boost output does not reach 5 V.

With a temporary 220 ohm load from +5 V to GND, rated at least 0.25 W:

```text
+5V rail after SW3/load  ~2.4 V
```

This argues against a simple light-load auto-shutdown explanation. The rail collapses further under a very small load, so the boost stage is either not really regulating, is current limiting/protecting, or the VOUT/LX power path has an assembly or component issue.

## Resistance Checks With Power Removed

Measured resistance to GND:

```text
+5V rail to GND              ~440-470 kOhm
+3.3V rail to GND            ~460-490 kOhm
IP5209 VOUT pins 16/17 to GND ~450 kOhm
IP5209 boost inductor area    ~240-270 kOhm
```

These values do not look like a hard short on +5 V or +3.3 V.

## Important Clarification About Inductors

The IP5209 boost inductor is board reference `L2`, value `1uH`.

Board reference `L1` is a separate 10 uH inductor associated with the CH592 internal DC/DC path. It is not the IP5209 boost inductor.

The expected IP5209 boost behavior after a valid short press on SW3 is:

```text
U7 VREG     about 3.1 V
U7 VOUT     about 5.0-5.2 V
+5V rail    about 5.0-5.2 V
+3.3V rail  about 3.3 V
```

Actual behavior:

```text
U7 VREG     about 3.1 V
U7 VOUT     about 2.8 V
+5V rail    about 2.8 V
+3.3V rail  about 2.8 V
```
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

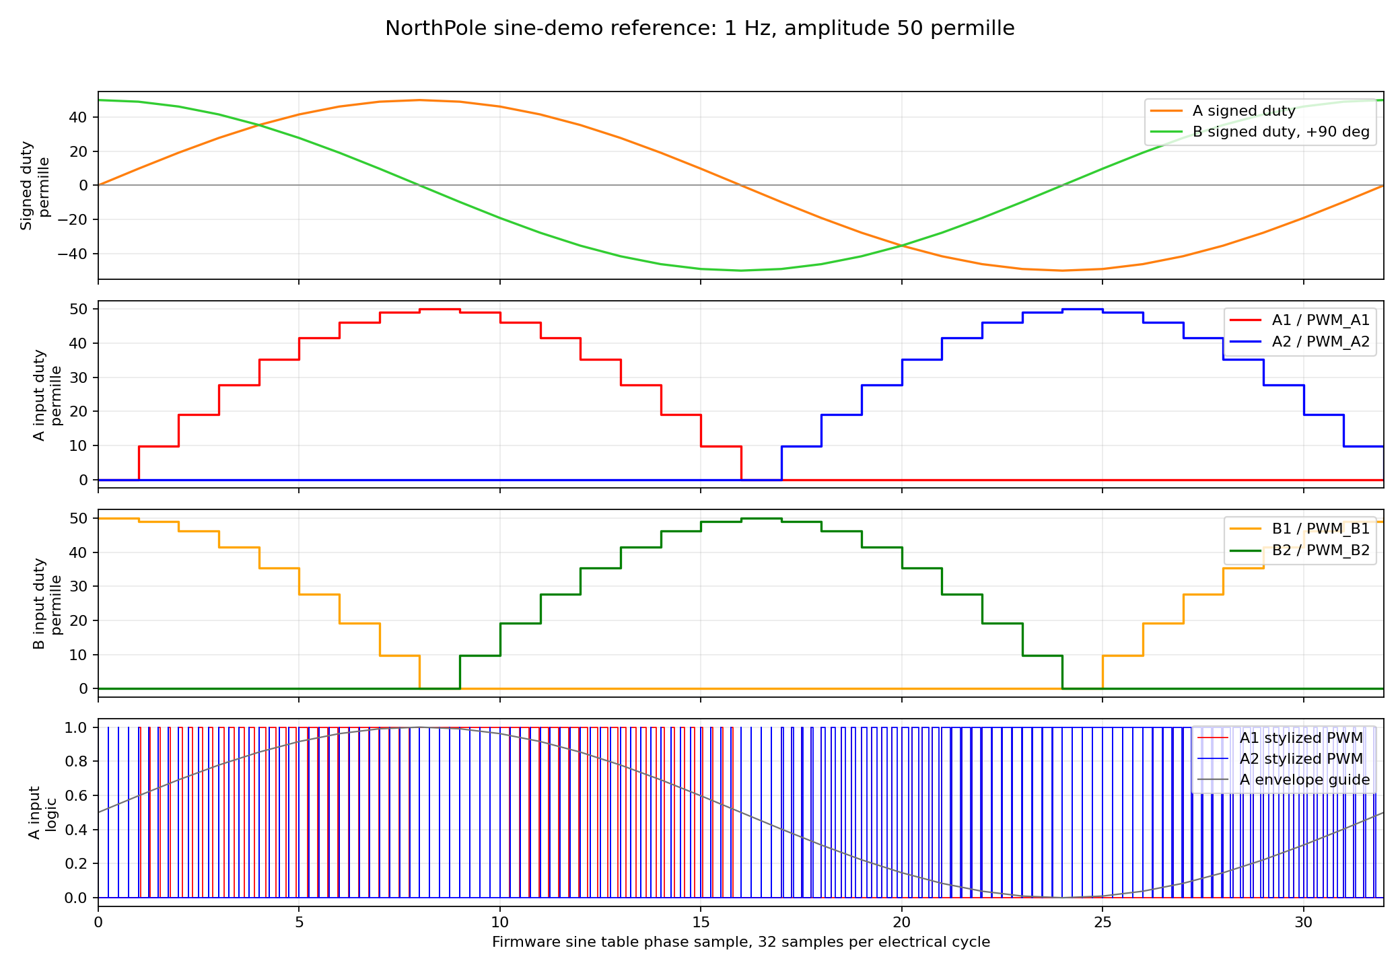
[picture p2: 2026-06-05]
Firmware/docs/motor_sine_reference/motor_sine_reference.png

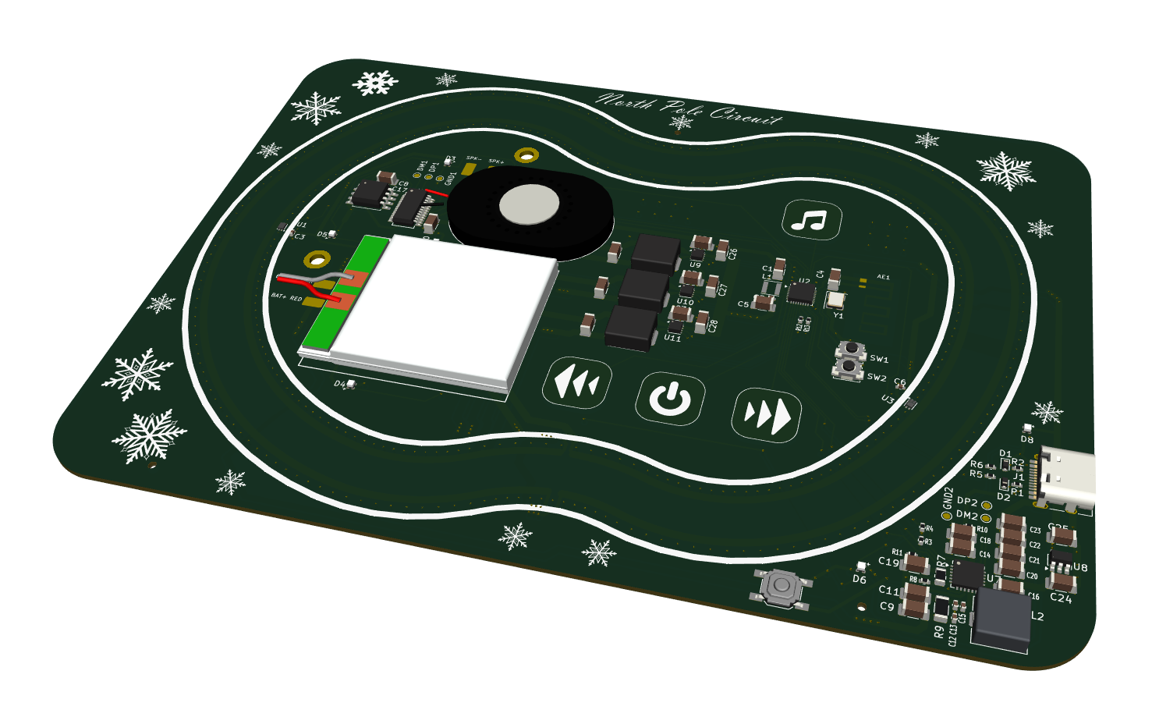
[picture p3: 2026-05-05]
Media/north_pole_ble_audio_card_render_3D.png

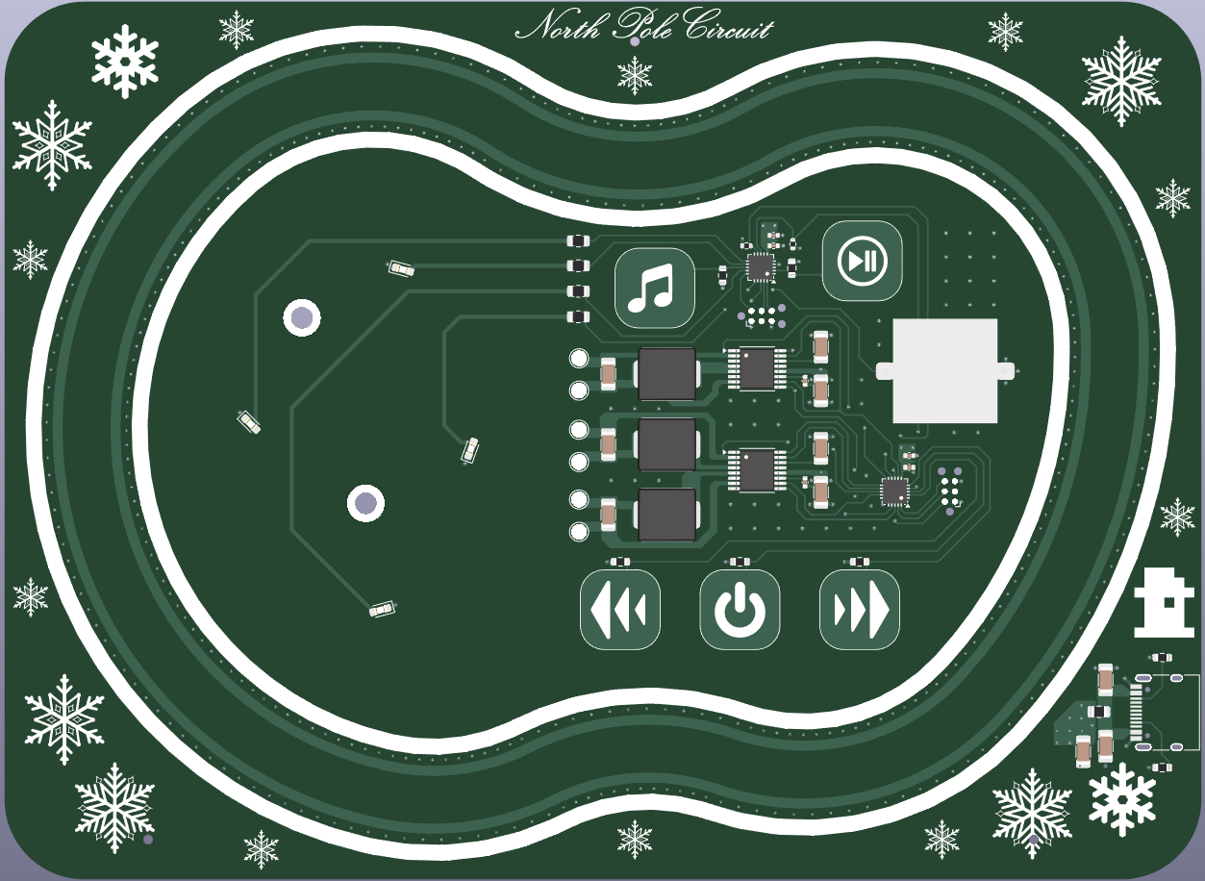
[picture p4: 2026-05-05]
Media/north_pole_ble_audio_card_pcb_preview.png

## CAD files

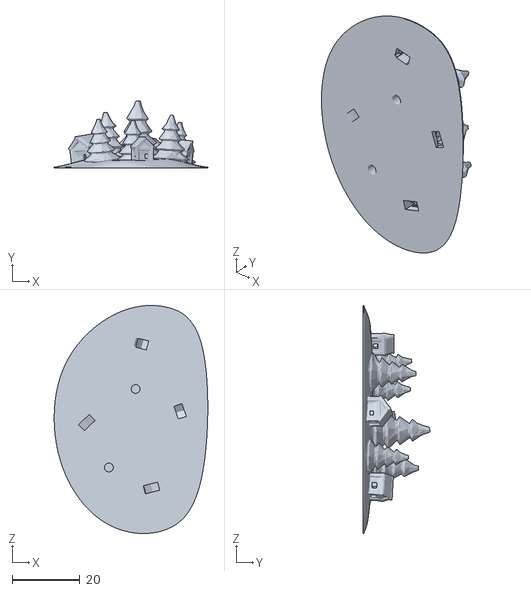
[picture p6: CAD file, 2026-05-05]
CAD/STL/decoration2.stl
45.4 x 19.7 x 67.4

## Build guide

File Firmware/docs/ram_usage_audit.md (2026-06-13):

# RAM Usage Audit

This audit is for the current integrated MVP image:

```text
Firmware\build\mvp_demo\northpole_ch592_bringup.elf
```

The numbers below were captured from the MounRiver RISC-V GCC tools after a
`Firmware\tools\build_mvp_demo.ps1` build.

## Summary

CH592 RAM budget:

```text
RAM size: 26 KB = 26624 bytes
Current used: 25580 bytes
Free by linker accounting: 1044 bytes
Static/linker usage: 96.08%
```

Section breakdown:

| Section | Bytes | Notes |
|---|---:|---|
| `.highcode` | 9160 | Executable code placed in RAM by WCH SDK/linker |
| `.data` | 1808 | Initialized global/static data copied into RAM |
| `.bss` | 14100 | Zero-initialized global/static data |
| `.stack` | 512 | Linker stack reservation |
| Total RAM accounted | 25580 | Leaves only 1044 bytes |

Important: the 96% number is not just global variables. About 9 KB is
RAM-resident executable code. Buffer reductions help, but production margin also
depends on what the linker places in `.highcode`.

Refresh commands:

```powershell
$toolbin = "C:\MounRiver\MounRiver_Studio2\resources\app\resources\win32\components\WCH\Toolchain\RISC-V Embedded GCC\bin"
$elf = "Firmware\build\mvp_demo\northpole_ch592_bringup.elf"
& "$toolbin\riscv-none-embed-size.exe" -A $elf
& "$toolbin\riscv-none-embed-nm.exe" -S --size-sort --radix=d $elf |
    Where-Object { $_ -match ' [bBdD] ' } |
    Select-Object -Last 80
```

## Largest RAM Data Symbols

Top current `.bss` / `.data` consumers:

| Symbol | Bytes | Area | Meaning / owner |
|---|---:|---|---|
| `MEM_BUF` | 6144 | `.bss` | WCH BLE heap, declared in `APP/peripheral_main.c` |
| `tx_ring` | 2048 | `.bss` | USB CDC shell TX ring |
| `motor_wave_dma_a1` | 1024 | `.bss` | Motor A1 DMA table |
| `motor_wave_dma_a2` | 1024 | `.bss` | Motor A2 DMA table |
| `buffer.2595` | 512 | `.bss` | Local static buffer emitted by compiler; inspect map before changing |
| `__global_locale` | 364 | `.data` | C library locale data |
| `devInfoAttrTbl` | 304 | `.data` | BLE Device Information service attributes |
| `gBleLlPara` | 296 | `.bss` | WCH BLE link-layer parameters |
| `simpleProfileAttrTbl` | 272 | `.data` | WCH example SimpleProfile GATT attributes |
| `rx_ring` | 256 | `.bss` | USB CDC shell RX ring |
| `queue` | 208 | `.bss` | WT2003 audio command queue |
| `northpoleAttrTbl` | 208 | `.data` | NorthPole custom GATT attributes |
| `report` | 168 | `.bss` | Shell/reporting buffer |
| `gapAttrTbl` | 144 | `.data` | GAP service attributes |
| `gapParameters` | 132 | `.bss` | BLE GAP parameters |
| `demo` | 132 | `.bss` | Demo scene state |
| `ep1_buf` | 128 | `.bss` | USB CDC endpoint buffer |
| `line.4477` | 96 | `.bss` | Shell line/input buffer |
| `motion` | 76 | `.bss` | Motion controller state |
| `ep0_buf`, `ep4_buf`, `registered`, `string_desc` | 64 each | `.bss` | USB/BLE support buffers |

These names are useful because they point to concrete reduction candidates.

## Largest RAM-Resident Code Symbols

The `.highcode` section is `9160` bytes. Largest visible symbols inside that
range:

| Symbol | Bytes | Notes |
|---|---:|---|
| `USB_IRQHandler` | 886 | USB interrupt path, only useful when USB CDC is enabled |
| `FLASH_EEPROM_CMD` | 874 | Flash/EEPROM command helper |
| `ll_get_connect_anchorPoint` | 752 | BLE controller |
| `LL_HopGetChannel2` | 618 | BLE controller |
| `TMOS_SystemProcess` | 518 | WCH TMOS/BLE scheduler |
| `SetSysClock` | 448 | Clock init |
| `lleIrqHandler` | 406 | BLE low-level interrupt |
| `tmos_proces_system_time` | 354 | TMOS timing |
| `ll_tx_wait_finish` | 348 | BLE controller |
| `ll_connect_send_data` | 306 | BLE controller |
| `BB_IRQLibHandler` | 262 | BLE/RF interrupt |
| `tmos_memory_free` | 264 | BLE/TMOS heap |
| `tmos_memory_allocate` | 242 | BLE/TMOS heap |
| `ll_connect_recv_data` | 224 | BLE controller |
| `ll_connect_event_continue` | 202 | BLE controller |
| `TMR3_IRQHandler` | 138 | Motor wave control update ISR |

Most `.highcode` is WCH BLE/USB/flash support, not NorthPole application code.
That means a production build with no USB CDC shell and fewer debug paths can
save both RAM variables and RAM-resident code.

## Reduction Plan

### 1. Split Profiles Harder

Keep the current MVP profile for bench work, but create a separate production
profile with fewer features compiled in.

Candidate profiles:

| Profile | Purpose | USB CDC shell | Diagnostic commands | BLE | Demo |
|---|---|---:|---:|---:|---:|
| `bringup` | hardware debug | on | full | on | optional |
| `mvp-demo` | Rev-A demo bench image | on | selected | on | on |
| `production` | final minimal app | off by default | off | selected | on |
| `factory-test` | manufacturing / board test | on or UART | limited | optional | off |

Expected production savings:

- USB CDC data buffers: about `64 + 128 + 64 + 256 + 2048 + 64 = 2624 B`.
- Shell parser/report/line and command state: several hundred bytes more.
- USB-related `.highcode`, especially `USB_IRQHandler`, if fully excluded.

This is the highest-value reduction if production can be operated by BLE, fixed
touch behavior, and safe defaults.

### 2. Reduce USB CDC TX Ring In MVP

Current:

```c
#define CDC_TX_RING_SIZE 2048u
```

Potential experiments:

```text
2048 -> 1024: save 1024 B
2048 -> 512:  save 1536 B
```

Risk:

- Long diagnostic prints may truncate/block more often.
- MVP debug usability may degrade.

Recommendation:

- Try `1024` first in an MVP RAM experiment.
- For production, compile USB CDC out instead of tuning the ring.

### 3. Shrink Or Rework Motor DMA Tables

Current:

```text
motor_wave_dma_a1 = 1024 B
motor_wave_dma_a2 = 1024 B
```

These are probably `256` entries each as `uint32_t`.

Potential reductions:

- Use `uint16_t` DMA entries if the DMA peripheral can safely write 16-bit timer
  compare values: save about `1024 B`.
- Reduce production table entries if 128 positions are acceptable: save up to
  `1024 B`, but this may hurt slow-speed smoothness.
- Generate/update a smaller rolling DMA buffer instead of full-cycle tables:
  more CPU complexity, less RAM.
- Compile out old/coarse diagnostic wave backends from production while keeping
  one proven engine.

Recommendation:

- Keep 256 phase positions for motion quality.
- First investigate whether A1/A2 compare DMA entries can be `uint16_t`.

### 4. Remove WCH Example GATT Service From Production

The image still contains WCH example SimpleProfile data:

```text
simpleProfileAttrTbl      272 B
simpleProfileChar* names   90 B total
simpleProfile values       small
```

If the NorthPole custom GATT service is enough, compile out SimpleProfile in the
production profile.

Potential saving:

- A few hundred RAM bytes.
- Some flash/code simplification.

Risk:

- Existing nRF Connect test expectations may need updating.

### 5. Tune BLE Heap Only After Feature Split

Current:

```text
MEM_BUF = 6144 B
```

This is the largest single RAM block. It is tempting to shrink first, but it is
owned by the WCH BLE stack and failures may be subtle.

Plan:

1. Build production without USB CDC and debug shell first.
2. Confirm BLE advertising, connection, and GATT writes.
3. Then test smaller heap values, for example:

```text
6144 -> 5632
6144 -> 5120
6144 -> 4608
```

Acceptance:

- Advertises after reset.
- nRF Connect can connect/read/write.
- Demo can run while connected.
- No memory allocation failures in repeated connect/disconnect cycles.

### 6. Move Constants To Flash

Some `.data` symbols are mutable only because they are not declared `const` or
because SDK APIs expect RAM pointers. Audit:

- GATT static strings and descriptors.
- Shell help text.
- RGB scene names.
- Demo status labels.

Use `const` where SDK/API semantics allow it. Do not force `const` into places
where the WCH stack writes into the buffer.

Expected saving:

- Dozens to a few hundred bytes.

### 7. Remove Diagnostic State From Production

Production should not need:

- IP5209 full dump decode structures.
- Shell line parser and command table.
- Scope diagnostic commands.
- RGB walk/strobe/test patterns except one internal self-test if desired.
- Raw I2C read/write.
- Raw motor commands.
- Audio format/raw commands.
- `hall watch`, `touch watch`.

Expected saving:

- Mostly flash/code, but also some buffers and parser state.

### 8. Stack Margin

The linker reserves only `512 B` for `.stack` in the current accounting. That
does not prove runtime stack safety.

Plan:

- Add a stack watermark/fill check in bring-up/MVP builds.
- Record worst observed stack use during:
  - BLE connected.
  - Demo running.
  - RGB active.
  - Audio command queued.
  - USB shell printing status.
- Production target should leave a static RAM margin plus measured stack margin.

Suggested production target:

```text
Static/linker RAM <= 80% before stack watermark confidence.
Absolute static/linker RAM <= 21 KB on a 26 KB part.
At least 2 KB practical headroom after measured worst-case stack.
```

## Proposed RAM Experiment Matrix

Create these as build profiles or temporary build wrappers:

| Experiment | Expected saving | Must still pass |
|---|---:|---|
| MVP with CDC TX ring 1024 | ~1024 B | Shell usable, demo starts |
| MVP with CDC TX ring 512 | ~1536 B | Short commands usable |
| MVP with USB CDC shell off | ~2.6 KB+ | BLE advertises, demo auto/touch works |
| Production without SimpleProfile | ~300-500 B | NorthPole GATT works |
| A-DMA tables as uint16_t | ~1024 B | Scope A1/A2 waveform unchanged |
| BLE heap 5120 after USB off | ~1024 B | Repeated BLE connect/disconnect |

Do these one at a time. Do not combine reductions until each individual
failure mode is understood.

## Current Priority

For the next milestone, prioritize:

1. Keep MVP stable for the physical demo.
2. Add runtime-loop/latency counters so we know whether RGB/touch/audio issues
   are CPU starvation or logic bugs.
3. Start a separate production profile with USB CDC and diagnostics compiled
   out.
4. Only then shrink BLE heap or motor DMA tables.

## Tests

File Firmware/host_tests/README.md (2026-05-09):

# Host Tests

These tests exercise firmware-equivalent logic that does not need CH592 hardware.

Run from the repository root:

```powershell
python -m unittest discover Firmware\host_tests
```

The tests intentionally model pure logic only: shell tokenization, settings CRC/defaults/recovery, motor command validation, RGB brightness limiting, and audio timeout behavior.

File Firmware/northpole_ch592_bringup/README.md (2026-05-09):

# North Pole CH592 Bring-Up Project

This MounRiver project is copied from the WCH CH592 EVT BLE `Peripheral` example after verifying that the original example builds unchanged with the MounRiver-bundled RISC-V toolchain.

Baseline verified locally:

- EVT SDK: `C:\WCH\CH592EVT\`
- Example: `C:\WCH\CH592EVT\EVT\EXAM\BLE\Peripheral`
- Toolchain: MounRiver `RISC-V Embedded GCC`, `riscv-none-embed-gcc`
- Baseline output: `Firmware\build\evt_peripheral_unmodified\Peripheral.hex`

The copied project preserves the WCH startup file, linker script, HAL, StdPeriphDriver, BLE library linkage, and BLE system initialization through linked SDK resources in `.project`.

Only the `APP/` layer is changed:

- `APP/peripheral_main.c` keeps the WCH BLE init order but inserts North Pole safe pin bring-up.
- `APP/northpole/` contains the board/framework drivers.
- `APP/include/` contains the North Pole framework headers plus the original `peripheral.h`.
- The original WCH `APP/peripheral.c` remains as the known-good BLE peripheral role scaffold and now registers the North Pole diagnostic GATT service.

Implemented bring-up transports and test hooks:

- USB CDC diagnostic shell for host commands.
- `safe check` and `pins verify` board-state reports.
- Time-bounded motor commands with mandatory arming; WCH PWM/timer backend present but disabled by default.
- WS2812 write backend for 6 LEDs with low default brightness.
- Minimal diagnostic BLE service `0xFD90` with no raw motor writes.
- Settings defaults/CRC/corruption test path.
- WT2003 nonblocking state machine marked hardware-validation pending.
- I2C scan/read/write helpers and conservative IP5209 probe/register access.

## Build

From the repo root:

```powershell
powershell -ExecutionPolicy Bypass -File Firmware\tools\build.ps1 -Profile evt-baseline
powershell -ExecutionPolicy Bypass -File Firmware\tools\build.ps1 -Profile bringup
```

Outputs are written under `Firmware\build\` and are ignored by git.

## MounRiver Import

Import/open `Firmware\northpole_ch592_bringup` in MounRiver Studio. The project name is `northpole_ch592_bringup`.

The linked SDK paths currently assume:

```text
C:\WCH\CH592EVT\EVT\EXAM\BLE\HAL
C:\WCH\CH592EVT\EVT\EXAM\BLE\LIB
C:\WCH\CH592EVT\EVT\EXAM\SRC\Ld
C:\WCH\CH592EVT\EVT\EXAM\SRC\RVMSIS
C:\WCH\CH592EVT\EVT\EXAM\SRC\Startup
C:\WCH\CH592EVT\EVT\EXAM\SRC\StdPeriphDriver
```

## Safety Defaults

At firmware entry, `northpole_ch592_early_safe_pins()` drives all DRV8837 inputs low and keeps the RGB data line low before BLE/application initialization.

The original EVT UART debug setup is not used as-is because it drives PA9, which is `/INT` on this PCB. UART logging is compiled off by default with `NORTHPOLE_ENABLE_UART1_LOG=0`.

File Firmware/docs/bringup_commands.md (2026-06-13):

# Bring-Up Commands

The bring-up firmware exposes a USB CDC diagnostic shell. UART1 is reserved for the WT2003 audio path and is not the default host console.

On the current PCB, UART1 is routed to the WT2003 audio IC. The original EVT debug UART used PA9, which is `/INT` on this board, so UART shell/log I/O is compiled off by default. Enable `NORTHPOLE_ENABLE_UART1_LOG=1` only on reworked hardware or a fixture where PB12/PB13 are connected to a host instead of the audio IC.

## Automated Smoke Tests

CH592 dev-board smoke build, already validated on the CH592X-EVT-R1-LinkE:

```powershell
python Firmware\tools\usb_shell_smoke_test.py --profile dev-board --port COM19 --timeout 3 --reset-recovery --ble-name "NorthPole BLE"
python Firmware\tools\ble_diag_smoke_test.py --scan --timeout 10
```

Target-board first pass, after replacing `COMxx` with the enumerated USB CDC port:

```powershell
python Firmware\tools\usb_shell_smoke_test.py --profile target --port COMxx --timeout 3
python Firmware\tools\ble_diag_smoke_test.py --scan --timeout 10
```

The dev-board profile avoids commands that would touch NorthPole target-only hardware. Use the target profile only on the real NorthPole PCB.

Low-volume WT2003 audio smoke test, after copying at least one MP3 to the WT2003 external flash and disconnecting any WT2003 USB storage cable:

```powershell
python Firmware\tools\audio_wt2003_smoke_test.py --port COMxx --volume 5 --index 1 --play-seconds 3
```

Faster playback-only check after the control path is already proven:

```powershell
python Firmware\tools\audio_wt2003_smoke_test.py --port COMxx --quick-play --volume 31 --index 1 --play-seconds 3
```

Use `--verbose` when full shell responses are needed. Without `--verbose`, the script prints a concise command summary.

Interactive Hall/touch physical test:

```powershell
python Firmware\tools\hall_touch_interactive_test.py --port COMxx
```

The Hall/touch script prints initial state and then only changed values while you move a magnet or touch a pad. If touch values stay at zero, the pads are not validated yet; the firmware touch backend may still need implementation or threshold tuning.

## Core

```text
help
version
status
faults
pins verify
safe check
reset
settings show
settings reset
settings save
settings corrupt
```

## MVP Demo

Build the integrated Rev-A MVP image:

```powershell
powershell -ExecutionPolicy Bypass -File Firmware\tools\build_mvp_demo.ps1
```

Flash:

```text
Firmware\build\mvp_demo\northpole_ch592_bringup.hex
```

Demo shell commands:

```text
demo status
demo clear-faults
demo start
demo stop
demo emergency-stop
demo speed <signed_hz_x1000>
demo duration <ms>
demo intensity <0-100>
demo audio <on|off|track <id>|volume <0-31>|next>
demo rgb <on|off|brightness <0-255>|effect <chase|stars|rainbow|breathe|strobe|christmas>>
demo hall <on|off|reset>
```

Current manual movement checkpoint:

```text
motor wave-run-smooth 8000 1000 10000 all sleep1 fwd guard-fwd guard-duty 600
```

The MVP demo profile owns the touch pads. Touch actions are applied on release
edges and now print the intended action. `RUN` short release toggles start/stop,
long `RUN` is emergency stop, `SPD+` and `SPD-` adjust signed speed, and
`MUSIC` starts/advances playback. `demo rgb effect stars` is the default MVP
effect; use `demo rgb effect rainbow` to check blended color transitions. See
`mvp_demo.md` and `first_integrated_demo_checklist.md`.

On the Rev-A MVP image, Hall is disabled by default because the Hall footprint is
wrong on this board revision. RGB and audio are still enabled by default. If
`demo status` shows `state=FAULT` or `faults=0x...`, run `demo clear-faults`
before `demo start` after confirming the board is safe.

`settings save` reports `flash=0` in the default pre-hardware builds because `APP_SETTINGS_FLASH_ENABLE` is disabled. CRC/default/corruption recovery logic exists, but persistent storage is not proven until a flash/SNV backend is implemented and target-tested.

See `mvp_runtime_timing.md` for the current MVP scheduling/timing model,
including RGB SPI timing, motor update interrupts, audio queue behavior, and
RAM/CPU headroom notes.

## Power

```text
i2c lines
i2c release-debug
i2c scan
i2c read <addr7> <reg>
i2c write <addr7> <reg> <value>
ip5209 status
ip5209 dump
ip5209 probe
ip5209 read <reg>
ip5209 write <reg> <value>
ip5209 boost <on|off>
ip5209 light-load <enable|disable>
ip5209 ntc <enable|disable>
```

I2C transfers use the WCH master peripheral with short timeouts. `ip5209 status` gives a short summary, while `ip5209 dump` prints each known IP5209 raw register byte in hex/binary and decodes the known bit fields from `PCB/datasheets/IP5209 IP5109 IP5207 IP5108 I2C registers.pdf`. The `boost_cfg` field is register `0x01` bit 2 only; it is not a physical VOUT measurement and does not prove that the +5 V rail is regulating. Writes remain manual only; do not change configuration registers casually because the datasheet marks reserved bits as stateful and requires read-modify-write.

The diagnostic write helpers are read-modify-write only and preserve reserved bits:

- `ip5209 boost on|off`: modifies `SYS_CTL0[0x01]` bit 2.
- `ip5209 light-load enable|disable`: modifies `SYS_CTL1[0x02]` bit 1.
- `ip5209 ntc enable|disable`: modifies `SYS_CTL5[0x07]` bit 6, where `0` means NTC enabled and `1` means NTC disabled.

Each helper prints register, mask, old value, new value, write result, and readback value.

`i2c lines` prints the raw CH592 PB15/PB14 SCL/SDA input levels and the I2C peripheral status registers. Use it before `i2c scan` when debugging a silent bus. Both lines should normally read high when idle.

`i2c release-debug` is a target-board diagnostic for the PB14/PB15 debug/I2C share. It disables the CH592 runtime two-wire debug function so SCL/SDA can own PB15/PB14, then reinitializes I2C. WCH-Link attach may require reset or download mode after this command.

The first target-board I2C pass proved that `i2c release-debug` changes `R16_PIN_ALTERNATE` from `0x0000` to `0x2000`, after which `ip5209 probe` ACKs at `0x75` and `i2c scan` finds `0x75`. This confirms the PCB I2C path, R14/R15 links, and pull-ups. Keep `i2c release-debug` manual during bring-up so WCH-LinkE access remains predictable.

## Touch And Hall

```text
touch raw
touch watch [ms] [period_ms]
hall read
hall watch [ms] [period_ms]
```

Touch measurement currently returns a GPIO-level placeholder through the WCH board port. The old CH32V003 charge-time idea can be reused conceptually, but the CH592X touch/ADC peripheral should be preferred if it is stable.

`touch watch` is the preferred physical touch-pad test. Example:

```text
touch watch 15000 20
```

It prints raw changes for `spd-`, `run`, `spd+`, and `music`. In the current
GPIO-placeholder implementation, `pressed` mirrors nonzero `raw` when no
calibrated threshold is configured.

`hall watch` is the preferred physical magnet test after Hall rework. Example:

```text
hall watch 15000 20
```

It polls both Hall inputs for 15 seconds, prints changes immediately, and emits
a heartbeat once per second.

## RGB

```text
rgb backend
rgb brightness <0-255>
rgb diag-pa14 high [ms]
rgb diag-pa14 low [ms]
rgb diag-pa14 square <hz> <ms>
rgb idle-low
rgb off
rgb one <index> <r> <g> <b>
rgb all <r> <g> <b>
rgb walk <r> <g> <b> [ms]
rgb scene stars [seconds] [brightness]
rgb scene breathe <r> <g> <b> [cycles] [step_ms]
rgb scene strobe [count] [brightness]
rgb scene christmas [seconds] [step_ms]
rgb scene rainbow [seconds] [brightness] [step_ms]
rgb chase <brightness>
rgb order test
rgb show
```

`rgb idle-low` only forces the CH592 `/LED` data pin low and does not transmit a WS2812 frame. Use it before WS2812 timing is trusted on a new board.

Brightness is capped by `APP_RGB_BRINGUP_BRIGHTNESS_LIMIT`. Use `rgb backend`
to confirm whether the build is using the normal PA15 bit-bang backend, the
PA14/SPI0 MOSI backend, or the PA14 GPIO bit-bang backend.

Use `rgb walk` for the most deterministic six-LED check. It clears the strip,
lights one LED, waits for the optional dwell time, then moves to the next LED:

```text
rgb brightness 24
rgb walk 24 0 0 250
rgb walk 0 24 0 250
rgb walk 0 0 24 250
```

Standalone RGB scene tests:

```text
rgb scene stars 8 24
rgb scene rainbow 10 24 120
rgb scene breathe 0 0 255 3 35
rgb scene strobe 8 24
rgb scene christmas 10 180
```

Expected visuals: `stars` gives random white/blue twinkles, `breathe` fades all
LEDs in and out together, `strobe` flashes all LEDs white together, and
`christmas` rotates a red/green pattern around the strip. `rainbow` moves a dim
blended rainbow across the strip and is the best quick check that mixed colors
are being rendered correctly.

The CH592 PA15 WS2812 bit-bang backend is implemented, but timing still needs
logic-analyzer validation with BLE interrupts active. For the Rev-A MVP rework,
cut/isolated WT2003 `BUSY`, jumper MCU-side PA14 to the WS2812 data input, and
isolate the old PA15 `/LED` trace. The old PA15 path was observed to pull the
reworked LED data net down until it was cut. Preferred Rev-A test build:

```powershell
powershell -ExecutionPolicy Bypass -Command "& { & 'Firmware\tools\build.ps1' -Profile bringup -ExtraDefine @('APP_RGB_WS2812_USE_SPI0_MOSI_PA14=1','APP_MOTOR_PWM_BACKEND_ENABLE=1') }"
```

The PA14 GPIO bit-bang experiment remains available with
`APP_RGB_WS2812_USE_PA14_BITBANG=1`, but bench captures showed invalid-looking
WS2812 frames and all LEDs could latch white. Do not use that backend as the
current LED reference. The SPI0 MOSI backend is the preferred Rev-A test path
because the pinmux experiment proved PA14/MOSI can emit WS2812-compatible
pulses. The SPI backend now sends explicit SPI zero-byte reset/latch windows
before and after every LED frame so any SPI-output enable artifact is followed
by a valid reset-low period before LED0 data begins.

For the Rev-A PA14/BUSY-to-LED jumper, use `rgb diag-pa14 high 5000` and
`rgb diag-pa14 square 1000 5000` with the scope on the jumper before debugging
WS2812 timing. These commands bypass SPI and WS2812 encoding and directly drive
PA14 as GPIO. If they are flat at the jumper, check the cut/jumper/probe point
before changing RGB firmware.

For WS2812 captures, the idle/reset portions before and after the data burst
must be low. A long high level before the burst is not part of a valid WS2812
message. If LED0 stays green while later LEDs respond, capture the first 50 us
of `rgb off` on the LED data net and check for a startup pulse before the first
encoded `0` bit.

## Audio

```text
audio status
audio raw <hex bytes>
audio version
audio qvol
audio qstatus
audio qcount-ext
audio qperiph
audio busy
audio volume <0-31>
audio play-index <1-65535>
audio play-name <name-no-ext>
audio stop
audio pause
audio next
audio prev
audio mode <single|single-loop|all-loop|random>
audio output <spk|dac>
audio sleep <idle|deep>
audio format-ext-flash CONFIRM
```

`audio ping` and `audio play <id>` remain accepted as compatibility aliases for `audio qstatus` and `audio play-index <id>`.

The KiCad audit currently shows the UART path is present through R12/R13. The WT2003HX V2.00 frame encoder/parser is implemented and host-tested against datasheet examples, but WT2003 UART responses, BUSY behavior, output mode, file indexing, and volume persistence still need target-board validation.

`audio format-ext-flash CONFIRM` is rejected unless the firmware is built with `APP_AUDIO_ALLOW_FORMAT_COMMAND=1`. Do not enable that flag for production builds.

## Motor

```text
motor status
motor arm <seconds>
motor off
motor pwm <A|B|G> <forward|reverse|coast|brake> <duty_permille> <ms>
motor sine-demo <speed_hz> <amplitude_permille> <ms> [AB|A|B|G|all]
motor wave-status
motor wave-stop
motor wave-start <electrical_hz_x1000> <amplitude_permille> [AB|A|B|G|all] [sleep0|sleep1] [fwd|rev] [guard-off|guard-fwd|guard-rev|guard-a|guard-b] [guard-duty <permille>]
motor wave-start-smooth <electrical_hz_x1000> <amplitude_permille> [AB|A|B|G|all] [sleep0|sleep1] [fwd|rev] [guard-off|guard-fwd|guard-rev|guard-a|guard-b] [guard-duty <permille>]
motor wave-run <electrical_hz_x1000> <amplitude_permille> <ms> [AB|A|B|G|all] [sleep0|sleep1] [fwd|rev] [guard-off|guard-fwd|guard-rev|guard-a|guard-b] [guard-duty <permille>]
motor wave-run-smooth <electrical_hz_x1000> <amplitude_permille> <ms> [AB|A|B|G|all] [sleep0|sleep1] [fwd|rev] [guard-off|guard-fwd|guard-rev|guard-a|guard-b] [guard-duty <permille>]
motion status
motion start
motion stop
motion speed <signed_hz_x1000>
motion step <signed_delta_hz_x1000>
motion guard <off|forward|reverse|phase-a|phase-b> [duty_permille]
motion tune status
motion tune proven
motion tune original-like
motion tune carrier <hz>
motion tune update <hz>
motion tune speed <signed_hz_x1000>
motion tune amplitude <permille>
motion tune guard <off|forward|reverse|phase-a|phase-b> <duty_permille>
motion tune ramp <start_ms> <stop_ms> <speed_ms>
```

Rules:

- `motor arm` is required before any non-coast command.
- Arm duration is capped by `APP_BRINGUP_MOTOR_ARM_MAX_MS`.
- `motor arm` wakes the DRV8837s by driving PB0 `/SLEEP` high after all IN pins are low.
- Duty is capped by `APP_BRINGUP_MOTOR_DUTY_LIMIT_PERMILLE` in bring-up builds.
- Command duration is capped by `APP_MOTOR_COMMAND_TIMEOUT_MS`.
- `motor off` immediately disarms, coasts all DRV8837 inputs, then drives PB0 `/SLEEP` low.
- The current target-board `bringup` build enables the Rev-A bench defaults:
  `APP_RGB_WS2812_USE_SPI0_MOSI_PA14=1`, `APP_MOTOR_PWM_BACKEND_ENABLE=1`,
  and `APP_MOTOR_PWM_MAX_DUTY_PERMILLE=1000`. If `motor wave-status` reports
  `backend=0`, the flashed HEX is not a motion-capable target bring-up image.
- `motor wave-run` is the known-good coarse 32-position timing path. Keep it
  as the reference command while tuning.
- `motor wave-run-smooth` uses the newer fixed-update 256-phase path. Test it
  against `wave-run` before replacing the motion preset.
- `motion tune proven` configures the motion wrapper to match the first
  confirmed moving smooth command: 20 kHz PWM carrier, 4 kHz control update,
  3 Hz electrical speed, 1000 permille A/B amplitude, fixed forward guard at
  1000 permille, and zero ramp. Use this as the motion-controller checkpoint.
- `motion tune original-like` configures the smoother 256-phase control path:
  100 kHz PWM carrier, 4 kHz control update, 8 Hz electrical speed, 700 permille
  A/B amplitude, fixed forward guard at 600 permille, and start/stop/speed ramps.
  This is still an experimental tuning target on the Rev-A bench sled; it may
  not move the sled even though the firmware reports the wave engine running.
- `motion stop` ramps down before disabling `/SLEEP`; `motor off` remains the
  immediate emergency stop.
- Carrier and update-rate changes are accepted only while motion is stopped.

`motor sine-demo` is a bounded diagnostic for checking pseudo-sine PWM envelopes on the DRV8837 input pins. It self-arms, steps a 32-sample sine table, then forces `motor off`. The default target is `AB`, where A uses phase 0 and B uses phase +90 degrees. Use `A`, `B`, or `G` to put the same signed sine envelope on one bridge while probing that bridge. Use low values first, for example:

```text
motor sine-demo 2 50 5000 A
motor sine-demo 2 50 5000 G
```

On the scope, the raw DRV8837 inputs remain digital 20 kHz PWM. The sine is visible as a slowly changing duty-cycle envelope, not as an analog sine voltage on the MCU pins.

For first real shuttle/sledge motion, drive physical phases `A` and `B`
together. `A1/A2` are only the two polarity legs of the A DRV8837 bridge, not
two track phases. Likewise `B1/B2` are the two polarity legs of B. The live
motion command should therefore target `AB`, normally with `B` phase shifted
90 degrees from `A`.

Initial finite live-motion commands with `/SLEEP` high:

```text
motor off
motor wave-run 500 50 1000 AB sleep1
motor wave-run 1000 50 1000 AB sleep1
motor off
```

If this is too weak for motion, rebuild with a higher
`APP_MOTOR_PWM_MAX_DUTY_PERMILLE` and keep the command duration short while
watching coil temperature and supply current.

2026-06-06 first-motion build used these defines, which are now the default
for the `bringup` profile:

```powershell
powershell -ExecutionPolicy Bypass -File Firmware\tools\build.ps1 -Profile bringup
```

This enables the PA14 RGB rework path, enables the motor wave backend, and
removes the software duty cap for finite `sleep1` wave commands. It does not
make the motor run indefinitely; use short `wave-run` commands and finish with
`motor off`.

2026-06-06 first real shuttle/sledge motion milestone:

```text
motor wave-run 3000 1000 20000 all sleep1
```

Result: the sledge moved within the `G` guardrails in one direction. USB-C
input current rose to about `900 mA`. This is the first confirmed Rev-A target
board motion with the DRV8837 bridges enabled.

Important interpretation:

- `3000` means `3.000 Hz` electrical sine-table frequency, not a 3000 Hz sine.
- `1000` means `1000 permille`, or full-scale duty envelope.
- `all` drives A, B, and G.
- A uses sine phase 0.
- B uses sine phase +90 degrees.
- G now defaults to fixed guard mode, not a sine phase.

With `all`, the guard bridge is now driven as a fixed inward-force guard by
default: `guard-fwd` means G1 PWM / G2 low. Use `guard-rev` if the physical
force is the wrong direction. `guard-a` and `guard-b` remain diagnostic modes
that phase-link G to A or B; they are not the default motion strategy.

Finite forward/reverse tests:

```text
motor wave-run 3000 1000 20000 all sleep1 fwd guard-fwd
motor wave-run 3000 1000 20000 all sleep1 rev guard-fwd
motor wave-run 3000 1000 20000 all sleep1 fwd guard-rev
motor off
```

Continuous motion controller:

```text
motion status
motion start
motion step 500
motion step -500
motion speed -3000
motion guard forward 1000
motion stop
```

Touch-pad behavior in the continuous controller:

- RUN toggles continuous motion on/off.
- SPD+ increases signed electrical frequency by the configured step.
- SPD- decreases signed electrical frequency by the configured step.
- If SPD- pushes a positive speed through zero, direction flips and the speed
  continues increasing in the reverse sign. SPD+ does the symmetric operation
  from reverse back through zero.
- Motion defaults to A/B propulsion plus fixed G guard and `/SLEEP` high.

The current bring-up default is 3 Hz electrical frequency, 0.5 Hz button step,
12 Hz max, full-scale A/B duty envelope, and full-scale G guard duty. Watch USB
input current and bridge/coil temperature during early runs.

## Measuring Real Coil Current

The USB-C meter shows total input current. It is useful for safety, but it is
not the same as current through an individual coil/track segment.

Better ways to see the physical coil current:

- Use a current probe around one bridge-output/coil conductor if available.
- Insert a low-value current shunt in series with one coil/track feed and
  measure differential voltage across it. Example: `0.05 ohm` or `0.1 ohm`,
  adequate power rating. Current is `I = Vshunt / Rshunt`.
- If using a grounded oscilloscope, do not clip scope ground to a floating
  H-bridge output. Use a differential probe or a known safe differential
  measurement setup.
- Probing `A1_OUT`, `B2_OUT`, or `G1_OUT` relative to board GND shows bridge
  voltage and inductive ringing. It does not directly show coil current.

The scope waveform from bridge outputs is not expected to look like an analog
sine. The sine model is encoded as duty and polarity commands into chopped
H-bridge outputs. When probing `B2_OUT`, `G1_OUT`, or `A1_OUT` relative to GND,
the scope shows bridge switching, coil/track inductance, flyback behavior, and
ringing. The reference sine plots document the intended input-duty envelope and
phase order; they are not literal analog voltages expected on the bridge output
pads.

`safe check` must report `MOTOR_SLEEP` on U2 pad 3 `/SLEEP` with expected safe state `output_low`.

## Debug And Update Connectors

J3 is the WCH-LinkE/debug connector, not a generic ARM SWD header:

```text
1 = 3.3V target reference
2 = TIO / SWDIO / PB14 / SDA-side MCU net
3 = NC unless reset is later wired
4 = TCK / SWDCK / PB15 / SCL-side MCU net
5 = GND
6 = NC
```

PB14/PB15 are shared with IP5209 I2C through R15/R14 0 ohm links. Normal firmware uses them as SDA/SCL. WCH-LinkE uses them as TIO/TCK. Do not expect IP5209 I2C access during active WCH-Link debugging.

J4 uses the Tag-Connect footprint only as a WT2003 USB update connector, but the current PCB revision is `BLOCKED` for update use because J4 pin 1 is unconnected:

```text
1 = BLOCKED: expected +5V, actual unconnected
2 = WT2003 D+
3 = NC
4 = WT2003 D-
5 = GND
6 = NC
```

J4 is not ARM SWD. Do not use it for WT2003 USB update until the missing +5 V path is fixed or a rework procedure is documented.

## BLE Diagnostic Service

The firmware registers a minimal North Pole diagnostic GATT service `0xFD90`:

- `0xFD91` firmware version, read
- `0xFD92` board revision, read
- `0xFD96` build profile, read
- `0xFD93` status packet, read
- `0xFD94` Hall/touch counters, read
- `0xFD95` safe control, write: RGB all, clear faults, audio stop, audio play index, audio volume, audio pause/resume, audio query status

No raw motor commands are exposed over BLE.

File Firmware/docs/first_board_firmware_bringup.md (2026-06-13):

# First Board Firmware Bring-Up

This sequence is intentionally conservative. Do not run motor movement tests until safe states, USB, BLE, RGB, sensors, audio, and I2C have been checked.

## Starting Point

The CH592 firmware base has already passed on the CH592X-EVT-R1-LinkE dev board:

- BLE advertisement as `NorthPole BLE`.
- Diagnostic GATT service `0xFD90` reads.
- USB CDC shell on Windows.
- USB CDC `reset` recovery.
- Automated BLE advertisement scan after reset.

The first real NorthPole PCB session should therefore focus on electrical safety and pin behavior, not on proving the CH592 BLE stack from scratch.

## Build Target-Board Firmware

Use the normal bring-up profile, with no dev-board smoke defines:

```powershell
powershell -ExecutionPolicy Bypass -File Firmware\tools\build.ps1 -Profile bringup
```

Expected output:

```text
BUILD_OK ...\Firmware\build\bringup\northpole_ch592_bringup.hex
```

Flash this HEX to the target board:

```text
Firmware\build\bringup\northpole_ch592_bringup.hex
```

Do not flash a dev-board smoke build to the target board for first electrical validation.

## Required Order

1. Inspect the board under magnification for solder bridges, reversed ICs, USB-C connector damage, and regulator/PMIC orientation.
2. Power the board from a current-limited supply or a protected USB port.
3. Verify 3.3 V before flashing application firmware.
4. Flash an unmodified WCH CH592 EVT example first, preferably `C:\WCH\CH592EVT\EVT\EXAM\BLE\Peripheral`.
5. Verify the USB bootloader or WCH-LinkE programming path through J3 is reliable.
6. Flash `northpole_ch592_bringup`.
7. Open the USB CDC shell.
8. Run `version`.
9. Run `safe check`.
10. Run `pins verify`.
11. Scope PB0 `/SLEEP` and all six DRV8837 inputs at reset and after `motor off`.
12. Scope the RGB data line idle state.
13. Confirm J4 is treated as WT2003 USB update only, not SWD/debug, and note that current PCB revision has J4 pin 1 unconnected.
14. Test BLE advertising and read the diagnostic service.
15. Only then test RGB commands. Start with `rgb idle-low`, then `rgb off`; if `rgb off` lights the LEDs, stop RGB testing and capture `/LED` timing with a logic analyzer.
16. Test Hall inputs.
17. Test touch raw readings.
18. Test WT2003 audio status and protocol commands only after the J4 +5 V update-power issue is fixed or a rework path is documented, then prepare one low-volume `0001.mp3` asset and disconnect the WT2003 USB cable.
19. Test `i2c lines`, then `i2c scan` and `ip5209 status` without WCH-LinkE actively debugging. If SCL/SDA are high but START never completes, try `i2c release-debug` and repeat the scan.
20. Test motor logic with no load or disconnected coils first.
21. Test motor PWM with current limiting and a logic analyzer before allowing any real motion.
22. Only after finite motor motion is proven, test continuous motion and touch controls.

## First-Flash Checklist

Use this checklist the first time the actual NorthPole PCB is flashed.

### 1. Pre-Power Inspection

- Confirm no obvious solder bridges on CH592X, DRV8837s, WT2003, IP5209, USB-C, and regulator pins.
- Confirm J3 is the WCH-LinkE/debug connector.
- Confirm J4 is the WT2003 USB update connector, not debug, but mark it blocked for file update on this PCB revision because J4 pin 1 is unconnected.
- If practical, leave the motor/load disconnected for the first power-up.
- If R14/R15 are populated, remember that PB14/PB15 are shared between WCH-LinkE debug and IP5209 I2C.

### 2. First Power

- Use a current-limited bench supply or protected USB source.
- Start with a conservative current limit.
- Verify `+3.3V` is present and stable.
- Stop immediately if current is unexpectedly high, the regulator heats, or 3.3 V is out of tolerance.

### 3. Flash

Preferred debug/programming path:

```powershell
& "$env:USERPROFILE\.platformio\packages\tool-wlink\wlink.exe" flash --chip CH59X --speed low --erase "Firmware\build\bringup\northpole_ch592_bringup.hex"
```

If `wlink` is unreliable, use MounRiver or WCH-LinkUtility with:

| Setting | Value |
|---|---|
| Core | RISC-V |
| Series | CH590/1/2 |
| Address | `0x00000000` |
| CLK Speed | Low |
| Operations | Erase All, Program, Verify, Reset and Run |

Do not change code-protection or debug-protection settings during normal bring-up.

### 4. USB CDC Shell

After reset, Windows should enumerate a CDC serial port. If it does, run:

```powershell
python Firmware\tools\usb_shell_smoke_test.py --profile target --port COMxx --timeout 3
```

Replace `COMxx` with the target board's COM port. If the script is too broad for the first pass, manually run:

```text
version
status
faults
settings show
pins verify
safe check
audio status
motor status
```

Expected:

- `faults=0x00000000` unless a known, documented first-board condition exists.
- `motor_armed=0`.
- `safe check` reports `/SLEEP` and all six DRV8837 inputs expected low.
- `audio status` remains `HARDWARE_VALIDATION_PENDING`.

### 5. Mandatory Scope Checks Before Any Output Test

Do these with the board freshly reset and before running RGB, audio, I2C, or motor commands:

| Signal | Expected |
|---|---|
| PB0 `/SLEEP` | Low |
| `/PWM_A1` | Low |
| `/PWM_A2` | Low |
| `/PWM_B1` | Low |
| `/PWM_B2` | Low |
| `/PWM_G1` | Low |
| `/PWM_G2` | Low |
| `/LED` | Low, no boot pulse |
| WT2003 UART TX | Safe input before audio command; idle high only once UART is enabled |

Then run:

```text
motor off
safe check
```

Confirm the same safe states again.

### 6. BLE Diagnostic Check

After the electrical safe state passes, verify BLE:

```powershell
python Firmware\tools\ble_diag_smoke_test.py --scan --timeout 10
```

Expected:

- Device name `NorthPole BLE`.
- Version, board revision, build profile, status packet, and counters packet read successfully.
- Clear-faults write succeeds.

Do not use BLE RGB/audio writes until the relevant hardware path has been tested locally from USB CDC.

### 7. Stop Point For First Session

The first target-board session is successful if:

- 3.3 V is stable.
- Firmware flashes and boots.
- USB CDC or BLE diagnostics work.
- `/SLEEP`, all DRV8837 inputs, and `/LED` are safe at reset.
- `safe check` and `pins verify` match the PCB audit.

Stop there and save notes before moving to RGB, sensors, audio, I2C, or motor tests.

## Initial Shell Commands

```text
version
status
safe check
pins verify
faults
settings show
motor off
rgb idle-low
rgb off
audio status
audio version
audio qperiph
ip5209 status
ip5209 dump
```

## Continuous Motion Start Point

Do not start here on an unvalidated board. Use this only after safe pins, RGB,
audio idle, I2C, and finite motor motion have already passed.

Build and flash the target bring-up HEX with RGB on the Rev-A PA14 rework and
full-scale motor duty enabled:

```powershell
powershell -ExecutionPolicy Bypass -File Firmware\tools\build.ps1 -Profile bringup
```

The `bringup` profile now includes those Rev-A bench defaults. If
`motor wave-status` reports `backend=0`, the flashed HEX is not a
motion-capable target bring-up image.

Flash:

```text
Firmware\build\bringup\northpole_ch592_bringup.hex
```

Manual shell checks:

```text
motion status
motor wave-run 3000 1000 20000 all sleep1 fwd guard-fwd
motor off
motor wave-run 3000 1000 20000 all sleep1 rev guard-fwd
motor off
motion start
motion step 500
motion step -500
motion stop
```

Touch-pad behavior:

- RUN toggles continuous motion on/off.
- SPD+ increases signed electrical frequency.
- SPD- decreases signed electrical frequency and reverses direction after
  crossing zero.
- G defaults to fixed guard mode, not a sine wave.

Watch USB input current, bridge temperature, and coil/track temperature during
every early run. The first motion test reached about `900 mA` total USB input
current.

## Probe Points And Expected Safe States

| Signal | CH592 pad/function | Net | Probe target | Expected safe state |
|---|---|---|---|---|
| DRV8837 A IN1 | pad 32 `TMR2` | `/PWM_A1` | U10 IN1 or MCU pad | Low after reset |
| DRV8837 A IN2 | pad 1 `TMR1_` | `/PWM_A2` | U10 IN2 or MCU pad | Low after reset |
| DRV8837 B IN1 | pad 17 `PWM9` | `/PWM_B1` | U11 IN1 or MCU pad | Low after reset |
| DRV8837 B IN2 | pad 18 `PWM7` | `/PWM_B2` | U11 IN2 or MCU pad | Low after reset |
| DRV8837 G IN1 | pad 30 `PWM5` | `/PWM_G1` | U9 IN1 or MCU pad | Low after reset |
| DRV8837 G IN2 | pad 31 `PWM4` | `/PWM_G2` | U9 IN2 or MCU pad | Low after reset |
| DRV8837 global SLEEP | pad 3 `PB0` | `/SLEEP` | U9/U10/U11 `~SLEEP` or MCU pad | Low after reset and after `motor off`; high only during armed bounded motor tests |
| RGB data | pad 28 `PA15` | `/LED` | first LED DIN | Low after reset, no boot pulse expected |
| WT2003 UART TX | pad 13 `TXD1_` | through R12 to `/RX1` | R12/WT RXD | Input/safe until audio command opens UART; idle high when UART enabled |
| WT2003 BUSY | pad 29 `PA14` | `/BUSY` | WT BUSY | Input, do not drive |
| Hall 1 | pad 2 `PB6` | `/HALL1` | sensor output | Input, raw level depends magnet/sensor |
| Hall 2 | pad 26 `PA4` | `/HALL2` | sensor output | Input, raw level depends magnet/sensor |
| Touch SPD- | pad 7 `AIN10` | `/SPD--` | touch pad | Analog/input, not driven |
| Touch RUN | pad 8 `AIN11` | `/RUN` | touch pad | Analog/input, not driven |
| Touch SPD+ | pad 9 `AIN12` | `/SPD++` | touch pad | Analog/input, not driven |
| Touch MUSIC | pad 27 `AIN1` | `/MUSIC` | touch pad | Analog/input, not driven |
| I2C SCL / WCH TCK | pad 11 `SCL` | `/SWDCK`, through R14 to `/SCL` | J3 pin 4, R14, U7 SCL | Pull-up/high when idle; unavailable during active WCH-LinkE debug |
| I2C SDA / WCH TIO | pad 12 `SDA` | `/SWDIO`, through R15 to `/SDA` | J3 pin 2, R15, U7 SDA | Pull-up/high when idle; unavailable during active WCH-LinkE debug |
| IP5209 INT | pad 10 `PA9` | `/INT` | U7 INT | Input; level depends PMIC |
| USB D+ / D- | pads 15/16 | `/DP`, `/DN` | USB connector | Enumerates as CDC when enabled |
| WT2003 USB update +5V | J4 pin 1 | unconnected | J4 pin 1 | BLOCKED: expected USB/update +5 V is missing |
| WT2003 USB update D+ | WT2003 pad 5 | `/DP2` | J4 pin 2 | Data path present, but update mode blocked until +5 V path is fixed |
| WT2003 USB update D- | WT2003 pad 4 | `/DM2` | J4 pin 4 | Data path present, but update mode blocked until +5 V path is fixed |

## Target-Board I2C / IP5209 Baseline

The first target-board I2C test showed that PB14/PB15 stayed in CH592 runtime debug mode after boot. Before releasing those pins, `i2c lines` showed idle-high lines but `i2c scan` found no devices. After:

```text
i2c release-debug
```

the CH592 pin alternate register changed to `0x2000`, `ip5209 probe` returned `rc=0`, and `i2c scan` found `0x75`.

Use this sequence for IP5209 validation:

```text
i2c lines
i2c release-debug
ip5209 probe
ip5209 status
ip5209 dump
i2c scan
```

Expected:

```text
ip5209 probe addr=0x75 rc=0
ip5209 addr=0x75 present=1 ...
i2c found=1 0x75
```

`ip5209 status` prints `boost_cfg`, decoded from IP5209 register `0x01` bit 2. Treat it as a configuration/status bit only. It is not a measurement of the +5 V rail.

Do not make IP5209 configuration writes during first bring-up unless there is a specific register-level reason and the existing register value has been read first.

## Connector Pinouts

J3 WCH-LinkE/debug:

| Pin | Function |
|---:|---|
| 1 | 3.3V target reference |
| 2 | TIO / SWDIO / PB14 / SDA-side MCU net |
| 3 | NC unless reset is later wired |
| 4 | TCK / SWDCK / PB15 / SCL-side MCU net |
| 5 | GND |
| 6 | NC |

J4 WT2003 USB update:

| Pin | Function |
|---:|---|
| 1 | BLOCKED: expected +5V, actual unconnected on current PCB |
| 2 | D+ |
| 3 | NC |
| 4 | D- |
| 5 | GND |
| 6 | NC |

J4 is not ARM SWD. Do not use it for WT2003 USB update until the missing +5 V path is fixed or a rework procedure is documented.

## WT2003 Audio Validation

Run this only after USB CDC, safe pins, RGB idle, BLE advertising, Hall/touch raw checks, and I2C non-hanging behavior are understood.

1. Do not start this sequence until the J4 pin 1 +5 V issue is fixed or a documented rework powers the WT2003 USB/update path.
2. Copy one file named `0001.mp3` to WT2003 external flash through the corrected WT2003 USB update path.
3. Disconnect the WT2003 USB cable.
4. Power-cycle the board.
5. Wait at least 1 s after WT2003 power-up.
6. Run `audio version`.
7. Run `audio qperiph`.
8. Run `audio qcount-ext`.
9. Run `audio volume 5`.
10. Run `audio play-index 1`.
11. Check BUSY goes high while playing.
12. Run `audio stop`.
13. Check BUSY returns low.

Do not send serial commands while WT2003 is connected to a PC as USB storage. Do not assume file index order equals filename order.

## Stop Conditions

Stop testing immediately if:

- 3.3 V is out of tolerance.
- Any DRV8837 input is high before an explicit motor command.
- Any motor input remains active after its command timeout.
- The board heats unexpectedly.
- USB or BLE testing causes resets.
- I2C scan hangs longer than the command timeout expectations.

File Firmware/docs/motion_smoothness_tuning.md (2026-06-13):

# Motion Smoothness Tuning

This page tracks the move from coarse 32-step motor motion to the original-like
NorthPole approach:

- A/B sine phases are 90 degrees apart.
- The runtime wave engine uses a 32-bit phase accumulator and 256 phase
  positions per electrical cycle.
- The control update tick is fixed, default `4000 Hz`, so low electrical speeds
  do not collapse into audible 32-step updates.
- The guard rail defaults to fixed inward force instead of a third sine phase.
- Motion start/stop and speed changes ramp instead of jumping immediately.

## Baseline Command

Keep the coarse path as the regression reference:

```text
motor wave-run 3000 1000 20000 all sleep1 fwd guard-fwd
```

That command uses the proven 32-position timing path. The smoother path is
isolated behind `wave-run-smooth` and `motion`, so a failed smooth test should
not invalidate the moving baseline.

The first smooth-motion checkpoint should use the known-moving preset while the
motor is stopped:

```text
motion tune proven
motion tune status
motion start
```

The `proven` preset maps to the command that moved the sled on Rev-A:

```text
carrier_hz=20000
control_update_hz=4000
sine_table_size=256
speed_target_hz_x1000=3000
amplitude_target=1000
guard=forward
guard_duty=1000
ramp_start_ms=0
ramp_stop_ms=0
ramp_speed_ms=0
```

Use the original-like preset only after the `proven` preset is repeatable:

```text
motion tune original-like
motion tune status
motion start
```

The preset sets:

```text
carrier_hz=100000
control_update_hz=4000
sine_table_size=256
speed_target_hz_x1000=8000
amplitude_target=700
guard=forward
guard_duty=600
ramp_start_ms=500
ramp_stop_ms=300
ramp_speed_ms=500
```

Startup ramps both amplitude and speed from zero toward these targets. This is
important for the `8 Hz` original-like preset: jumping directly to full target
speed from rest failed to capture the sled reliably.

Bench note: on 2026-06-12 the `original-like` preset reported `running=1`,
`last_rc=0`, and advancing update ticks, but did not visibly move the sled. That
points to tuning/force limits rather than a parser or zero-output software bug.
The `proven` preset is the production checkpoint until the higher-carrier
original-like tuning is made to move reliably.
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

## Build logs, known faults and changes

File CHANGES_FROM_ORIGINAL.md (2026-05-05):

# Changes From Original NorthPoleCircuit

This fork started from the original Janky Jingle Crew NorthPoleCircuit and explores a BLE/audio redesign.

## System Changes

| Area | Original project | BLE audio card redesign |
|---|---|---|
| Controller | CH32V003-based original control architecture | CH592X BLE MCU |
| Wireless | Not a primary feature | BLE control/configuration target |
| Power | USB-C powered card | USB-C plus 1S LiPo charge/boost path |
| Audio | Original buzzer/music approach | Dedicated audio playback IC, flash, and speaker path |
| Motor drive | Original magnetic propulsion driver design | 3 x DRV8837 H-bridge phase drive |
| Position feedback | Original track concept | 2 Hall checkpoint sensors |
| User input | Original buttons | 4 capacitive touch buttons |
| Lighting | Original decorative lighting | 6 addressable 1010 RGB LEDs |
| PCB | Original North Pole Circuit artwork/layout | Revised KiCad 10 PCB postcard layout |

## Hardware Changes

- Added CH592X BLE MCU.
- Added WCH-style PCB antenna footprint and RF keepout considerations.
- Added IP5209 LiPo charge/boost power path.
- Added ME6211 3.3 V logic regulator.
- Added WT2003H4-24SS audio playback IC and SPI NOR flash.
- Added speaker body/wire-pad helper footprints.
- Added 2 Hall sensors for sled position checkpoints.
- Added 4 capacitive touch electrodes.
- Added 6 addressable RGB LEDs.
- Updated RGB LED sourcing to JLCPCB `C41347988` / `TZ-H1010-RGB/A-BU08UF-TA1305NA/W109`.
- Added explicit JLCPCB/LCSC/MPN metadata to the KiCad project.
- Added Fabrication Toolkit rotation-offset properties for IC placement.

## PCB And Manufacturing Changes

- Migrated the active hardware project to KiCad 10.
- Preserved the magnetic-track concept while adding new electronics around it.
- Added local custom symbols and footprints needed by the new layout.
- Added draft JLCPCB production outputs under `PCB/production/`.
- Added local STEP models for selected custom footprints.

## Firmware Status

The new firmware is not written yet.

The original upstream `Code/` directory is kept as reference material. New firmware for this BLE/audio version should live under `Firmware/`.

## Open Items Before A Public Release

- Validate the PCB on real hardware.
- Re-run and review ERC/DRC before ordering.
- Re-export manufacturing files from the exact final KiCad state.
- Confirm JLCPCB stock and assembly status for every part.
- Resolve WT2003H4/audio IC sourcing.
- Verify BLE antenna stackup and keepout.
- Verify LiPo charge current and battery safety.
- Write and test the CH592X firmware.
- Add final photos/video after first board bring-up.

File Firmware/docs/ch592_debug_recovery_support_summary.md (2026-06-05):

# CH592 Debug Recovery Support Summary

Date: 2026-05-17

This note summarizes the CH592X-EVT-R1-LinkE upload/debug investigation for external review.

## Hardware Under Test

- Board: CH592X-EVT-R1-LinkE development board
- Target MCU: CH592 / CH59x family
- Programmer/debug probe: onboard/attached WCH-LinkE
- Native USB download pin: PB22 Download button
- Native USB bootloader VID:PID observed by `wchisp`: `4348:55E0`
- WCH-LinkE VID:PID observed by `wlink`: `1A86:8010`
- WCH-Link firmware observed by `wlink`: `v2.18(v38)`, `WCH-LinkE-CH32V305`

## Tool Versions Seen

- MounRiver Studio: installed/reinstalled during investigation
- WCH-LinkUtility: V2.90
- WCHISPStudio: V3.9
- WCHISPTool_CH57x-59x inside WCHISPStudio: V3.10
- PlatformIO CH32V platform: `Community-PIO-CH32V/platform-ch32v`
- PlatformIO `tool-wlink` package: `0.23.241116+sha.f44158e`
- Bundled `wlink.exe` version: `wlink 0.1.1`
- External `wlink 0.1.2`:
  - x86 build worked like 0.1.1 in earlier test
  - x64 build listed the probe but failed with an incompatible-driver USB error
- PlatformIO `tool-wchisp` package: `0.23.240914`
- Standalone `wchisp 0.3.0` also tested
- WCHISPTool_CMD package:
  - Linux/macOS binaries and source exist
  - Windows folder only contained a README pointing back to the WCHISPTool installer
  - no Windows `WCHISPTool_CMD.exe` was found in the tested package

## Known Working Results

### WCHISPStudio Native USB ISP

WCHISPStudio V3.9 can flash the CH592 through the native USB Download mode.

Known working settings:

- Chip series: `CH59x`
- Chip model: `CH592`
- Download port: `USB`
- Download cfg pin: `PB22`
- RST as manual reset input pin: checked in the GUI during successful flashes
- No-key serial port download: checked in the GUI during successful flashes
- Run target program after download: checked in the GUI during successful flashes
- Erase / program / verify: passed

Known working files flashed by WCHISPStudio:

- `Firmware/build/bringup/northpole_ch592_bringup.hex`
- `Firmware/mounriver_ch592_led_probe/obj/mounriver_ch592_led_probe.hex`

WCHISPStudio reports success with erase/program/verify.

### Earlier Working WCH-Link / wlink Path

Before the current failure state, WCH-LinkUtility V2.90 could flash:

- Core: `RISC-V`
- Series: `CH590/1/2`
- Address: `0x00000000`
- Clock speed: `Low`
- Active WCH-Link mode: `WCH-LinkRV`
- Operations: erase all, program, verify, reset and run

Earlier standalone `wlink` command also worked when the target was placed in Download mode first:

```powershell
& "$env:USERPROFILE\.platformio\packages\tool-wlink\wlink.exe" --chip CH59X --speed low status
& "$env:USERPROFILE\.platformio\packages\tool-wlink\wlink.exe" flash --chip CH59X --speed low --erase "Firmware\mounriver_ch592_led_probe\obj\mounriver_ch592_led_probe.hex"
```

Earlier successful `wlink status` identified:

```text
Attached chip: CH59X [CH592] (ChipID: 0x92000000)
RISC-V ISA: RV32ACIMUX
RISC-V arch: WCH-V4C
```

## Resolved Root Cause

The board had been put into a protected CH592 state. WCHISPStudio V3.9 could still flash through
native USB Download mode, but WCH-LinkUtility, MounRiver, and `wlink` could not attach because
debug/read access was disabled.

The working recovery was:

```powershell
# Put CH592 into USB Download mode.
# Use Zadig to bind USB Module / 4348:55E0 to WinUSB.
# Do not change WCH-Link / 1A86:8010 interfaces.
$wchisp = "$env:USERPROFILE\.platformio\packages\tool-wchisp\wchisp.exe"
& $wchisp config unprotect
```

After `config unprotect`, WCH-LinkUtility and MounRiver identified the chip again.

## Previously Broken State

### WCH-LinkE Debug Attach

WCH-LinkUtility and `wlink` can see the WCH-LinkE probe, but cannot attach to the target MCU.

Current WCH-LinkUtility symptoms:

```text
Connected RISC-V mode WCH-Link Cnt:1
Succeeded to connect with WCH-Link!
Begin to set chip type...
Failed, the chip type is not matched or status of chip is wrong!
```

Current `wlink` symptom:

```powershell
& "$env:USERPROFILE\.platformio\packages\tool-wlink\wlink.exe" --chip CH59X --speed low status
```

```text
Connected to WCH-Link v2.18(v38) (WCH-LinkE-CH32V305)
Error: Probe is not attached to an MCU, or debug is not enabled. (hint: use wchisp to enable debug)
```

### CH592 Config Readback

At one point, `wchisp config info` reported:

```text
USER_CFG: 0x4FFF0F4D
CFG_RESET_EN 0x1
  `- Enable
CFG_DEBUG_EN 0x0
  `- Disable
CFG_BOOT_EN 0x1
  `- Enable
CFG_ROM_READ 0x0
  `- Disable the programmer to read out, and keep the program secret
```

The earlier working development config was:

```text
USER_CFG: 0x4FFF0FD5
CFG_RESET_EN 0x0
  `- Disable
CFG_DEBUG_EN 0x1
  `- Enable
CFG_BOOT_EN 0x1
  `- Enable
CFG_ROM_READ 0x1
  `- Read enable
```

This suggests debug/read access may have been disabled by an ISP configuration/protection setting.

### `wchisp config set` Cannot Repair It

Attempted:

```powershell
$wchisp = "$env:USERPROFILE\.platformio\packages\tool-wchisp\wchisp.exe"
& $wchisp config set 4FFF0FD5
```

Result:

```text
[INFO] setting cfg value 4FFF0FD5
thread 'main' panicked at src/main.rs:277:21:
not implemented
```

The same `not implemented` panic was seen earlier for other config values. Therefore the tested `ch32-rs/wchisp` build cannot currently restore CH592 config words.

## Driver State Observations

WCHISPStudio and `ch32-rs/wchisp` use different Windows driver bindings for the CH592 native USB bootloader interface:

- WCHISPStudio V3.9 works with WCH's official CH375/WCHLink-style driver stack.
- `ch32-rs/wchisp` expects WinUSB/libusb/nusb access.

After using WCHISPStudio, `wchisp` may fail with:

```text
Failed to open USB device: Bus 004 Device 001: ID 4348:55e0
It's likely no WinUSB/LibUSB drivers installed.
```

Attempts to install Zadig on the CH592 bootloader interface later failed with:

```text
Driver installation failed
```

Do not install Zadig on the WCH-LinkE probe interfaces unless intentionally abandoning official WCH-Link/MounRiver tools.

## North Pole Firmware Observations

North Pole bring-up firmware builds successfully:

```powershell
powershell -ExecutionPolicy Bypass -File Firmware\tools\build.ps1 -Profile bringup
```

The build now runs the KiCad audit and produces:

```text
Firmware\build\bringup\northpole_ch592_bringup.hex
```

Historical note: this section captures the earlier failing state before the dev-board BLE/USB CDC smoke tests passed.

After flashing North Pole bring-up firmware with WCHISPStudio, Windows reported:

```text
Unknown USB Device (Device Descriptor Request Failed)
```

This was initially interpreted as a likely custom USB CDC enumeration problem in the application firmware, not as a flashing failure. It has since been superseded by a dev-board pass where Windows enumerated USB CDC and the shell/reset-recovery test passed.

BLE scan initially did not show `NorthPole BLE`. That has also been superseded by dev-board tests where `NorthPole BLE` advertised and the diagnostic GATT service was readable. The original fallback baseline was to flash the unmodified WCH BLE `Peripheral` example and scan for:

```text
Simple Peripheral
```

## Experiments Performed

1. Confirmed dev board requires manual USB Download mode using PB22 Download button during reset/power-cycle.
2. Confirmed WCHISPStudio V3.9 can flash CH592 in USB Download mode.
3. Confirmed MounRiver LED/LCD probe project can build and previously ran on the dev board.
4. Confirmed WCH-LinkUtility V2.90 previously flashed the MounRiver LED probe through WCH-LinkE.
5. Confirmed standalone `wlink 0.1.1` previously attached/flashed when the board was in Download mode.
6. Confirmed `wlink 0.1.2` x86 behaved similarly to 0.1.1 in earlier tests.
7. Confirmed `wlink 0.1.2` x64 had USB driver incompatibility on this Windows setup.
8. Confirmed PlatformIO/wchisp native USB ISP could identify the CH592 with WinUSB installed, but flashing had verify mismatch / no-run problems before the official WCHISPStudio path was proven.
9. Installed WCHISPStudio V3.9 / WCHISPTool_CH57x-59x V3.10; WCH official GUI ISP works.
10. Reinstalled MounRiver; WCH-Link target attach still fails.
11. Tried `wchisp config set`; it panics as not implemented for this target/tool path.
12. Tried Zadig later for the target USB device; driver installation failed.

## Current Questions For External Help

1. How can `CFG_DEBUG_EN` be restored on CH592 when open-source `wchisp config set` is not implemented?
2. Does WCHISPStudio V3.9 have a reliable GUI path to restore CH592 config to development defaults?
3. Which WCHISPStudio checkboxes map to `CFG_DEBUG_EN`, `CFG_ROM_READ`, and `CFG_RESET_EN` on CH592?
4. Did enabling `Code and data protection mode` in WCHISPStudio likely change `USER_CFG` from `0x4FFF0FD5` to `0x4FFF0F4D`?
5. Is there a Windows version of `WCHISPTool_CMD` that can write CH592 config words through the official WCH driver?
6. Can WCH-LinkUtility recover a CH592 once `CFG_DEBUG_EN` is disabled, or must recovery be done through native USB ISP?
7. What is the safest sequence to return the board to:

```text
CFG_DEBUG_EN = Enable
CFG_ROM_READ = Read enable
WCH-LinkE attach works
WCHISPStudio still flashes
```

## Avoid Doing For Now

- Do not click `Disable Two-Line Interface` in WCH-LinkUtility.
- Do not install Zadig on WCH-LinkE interfaces.
- Do not enable code/data protection during bring-up.
- Do not rely on `wchisp config set` unless a fixed version is found.
- Treat North Pole USB CDC as dev-board validated only. It still needs target-board and Linux validation before it becomes the only diagnostic path.

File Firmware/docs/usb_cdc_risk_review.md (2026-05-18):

# USB CDC Risk Review

Status: `NEEDS_TARGET_BOARD`.

The custom CDC shell is intentionally small. It has enumerated and passed the dev-board smoke test on the CH592X-EVT-R1-LinkE board, but it still needs target-board validation before production use.

## References Compared

Official WCH examples checked:

```text
C:\WCH\CH592EVT\EVT\EXAM\USB\Device\COM\src\Main.c
C:\WCH\CH592EVT\EVT\EXAM\BLE\BLE_USB\APP\app_usb.c
```

North Pole implementation:

```text
Firmware/northpole_ch592_bringup/APP/northpole/usb_cdc_shell.c
```

## Descriptor Parity

| Area | WCH USB Device COM | North Pole CDC shell | Review |
|---|---|---|---|
| Device descriptor | CDC class `0x02`, VID `0x1A86`, PID `0x8040`, EP0 64 bytes | Same class, VID/PID, EP0 size | `MATCHES_WCH_EXAMPLE` except product version/string values |
| Configuration total length | `0x0043` | `0x0043` | `MATCHES_WCH_EXAMPLE` |
| Interfaces | CDC communication interface 0 and data interface 1 | Same | `MATCHES_WCH_EXAMPLE` |
| CDC ACM descriptors | Header, ACM, union, call-management descriptors | Same byte layout | `MATCHES_WCH_EXAMPLE` |
| Interrupt IN endpoint | `0x84`, interrupt, 8 bytes | `0x84`, interrupt, 8 bytes | `INTENTIONAL_DIFFERENCES`: interval is `0x10` instead of WCH `0x01`; endpoint is left NAK-only |
| Bulk OUT endpoint | `0x01`, bulk, 64 bytes | Same | `MATCHES_WCH_EXAMPLE` |
| Bulk IN endpoint | `0x81`, bulk, 64 bytes | Same | `MATCHES_WCH_EXAMPLE` |
| Strings | WCH manufacturer/product/serial | North Pole manufacturer/product/serial | `INTENTIONAL_DIFFERENCES` |

## Control Transfers

| Request | WCH COM example | North Pole behavior | Review |
|---|---|---|---|
| `GET_DESCRIPTOR` | Device/config/string handled over EP0 chunks | Same basic EP0 chunking | `MATCHES_WCH_EXAMPLE` |
| `SET_ADDRESS` | Address applied after status IN | Same | `MATCHES_WCH_EXAMPLE` |
| `SET_CONFIGURATION` | Sets configured state and endpoint ACK/NAK state | Same for EP1/EP4 used by CDC shell | `INTENTIONAL_DIFFERENCES`: does not configure unused EP2/EP3 |
| `GET_CONFIGURATION` | Returns current config | Same | `MATCHES_WCH_EXAMPLE` |
| `GET_INTERFACE` / `GET_STATUS` | Returns zero status | Same | `MATCHES_WCH_EXAMPLE` |
| `CLEAR_FEATURE` | Clears endpoint halt/toggle for supported endpoints | Simplified for EP1 data endpoint | `INTENTIONAL_DIFFERENCES` |
| `SET_LINE_CODING` | Accepts 7-byte CDC line coding | Same | `MATCHES_WCH_EXAMPLE` |
| `GET_LINE_CODING` | Returns stored line coding | Same | `MATCHES_WCH_EXAMPLE` |
| `SET_CONTROL_LINE_STATE` | ACKs request | Same | `MATCHES_WCH_EXAMPLE` |

The custom code does not implement WCH CH341/vendor-mode requests from the standalone COM example. That is intentional because this firmware exposes CDC ACM only.

## Endpoint And DMA Setup

| Register/setup | WCH COM example | North Pole behavior | Review |
|---|---|---|---|
| `R8_UEP4_1_MOD` | Enables EP4 TX, EP1 TX, EP1 RX | Same | `MATCHES_WCH_EXAMPLE` |
| `R8_UEP2_3_MOD` | Also enables EP2 and EP3 for vendor/extra paths | `0x00` | `INTENTIONAL_DIFFERENCES`: unused endpoints disabled |
| `R16_UEP0_DMA` | EP0 buffer | EP0 buffer | `MATCHES_WCH_EXAMPLE` |
| `R16_UEP1_DMA` | 128-byte EP1 OUT/IN buffer | 128-byte EP1 OUT/IN buffer | `MATCHES_WCH_EXAMPLE` |
| `R16_UEP2_DMA` / `R16_UEP3_DMA` | Allocated in WCH examples for extra endpoints | Only `R16_UEP3_DMA` is assigned to an EP4 placeholder buffer | `NEEDS_HARDWARE_TEST` |
| EP4 interrupt buffer | WCH examples do not actively use CDC notification payloads | North Pole keeps EP4 NAK-only | `NEEDS_HARDWARE_TEST` |

The EP4 notification endpoint is the highest-risk mismatch. The descriptor exposes it because Windows CDC ACM expects a notification endpoint, but the firmware does not send serial-state notifications. This should still be acceptable for many hosts, but enumeration must be tested on Windows and Linux.

## Interrupt And Data Path

| Area | WCH behavior | North Pole behavior | Review |
|---|---|---|---|
| USB ISR model | Standalone COM queues IRQ events; BLE_USB handles transfer work in `USB_DevTransProcess()` | Custom ISR handles setup, EP0, and EP1 directly | `INTENTIONAL_DIFFERENCES` |
| EP1 OUT | Copies received packet to an application buffer | Pushes packet bytes into a nonblocking shell RX ring | `INTENTIONAL_DIFFERENCES` |
| EP1 IN | Copies application data to EP1 IN buffer and ACKs | Pulls from shell TX ring and ACKs | `INTENTIONAL_DIFFERENCES` |
| Blocking behavior | Example code is demo-oriented | Shell drops TX when ring is full and polls RX | `INTENTIONAL_DIFFERENCES`, chosen to avoid blocking BLE/app safety |
| USB reset | Clears address and endpoint states | Clears address/configured state and endpoint states | `MATCHES_WCH_EXAMPLE` for active CDC endpoints |

## Dev-Board Findings

Validated on CH592X-EVT-R1-LinkE with:

```powershell
python Firmware\tools\usb_shell_smoke_test.py --profile dev-board --port COM19 --timeout 3 --reset-recovery --ble-name "NorthPole BLE"
```

Findings:

- Windows enumerated the shell as `USB-SERIAL CH9340 (COM19)` with VID/PID `1A86:8040`.
- `help`, `version`, `status`, `faults`, `settings show`, `audio status`, `pins verify`, `safe check`, and `motor status` responded.
- `reset` disconnected and reconnected COM19; `version` worked after reset.
- BLE advertising resumed after reset and was visible as `NorthPole BLE`.
- A CDC TX bug was found: a response exactly equal to the 64-byte bulk endpoint size was held by Windows until later traffic. The firmware now sends a zero-length packet after a full-size IN packet when the TX ring is empty.

## Enumeration Expectations

Expected later validation:

- Windows: appears as a USB serial COM port without a vendor driver requirement.
- Linux: appears as `cdc_acm`, typically `/dev/ttyACM*`.
- `version`, `status`, `pins verify`, and `safe check` work through the virtual COM port.
- Disconnect/reconnect and host USB reset do not leave motor pins or `/SLEEP` unsafe.

## Fallback If CDC Fails

1. Build with USB CDC disabled:

   ```powershell
   powershell -ExecutionPolicy Bypass -File Firmware\tools\build.ps1 -Profile bringup -ExtraDefine APP_USB_CDC_SHELL_ENABLE=0
   ```

2. Use BLE diagnostic reads for identity/status once BLE is validated.
3. Use a temporary UART fixture only if UART1 is isolated from WT2003.

## Decision

Do not rewrite the USB stack before target-board validation. The implementation has descriptor parity for the CDC shape, intentional simplifications for the shell use case, and one CH592 dev-board Windows pass. Endpoint 4 notification handling, DMA/register behavior under target-board load, and Linux enumeration remain `NEEDS_TARGET_BOARD`.

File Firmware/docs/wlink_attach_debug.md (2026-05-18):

# WCH-LinkE / wlink Attach Debug

Purpose:

Track WCH-LinkE debug attach separately from USB ISP flashing. The current MounRiver GUI download path works. PlatformIO `wlink` also works when the CH592 is manually placed in Download mode first.

## CRITICAL: PROTECTED CH592 LOOKS LIKE A BROKEN WCH-LINK

If the chip was accidentally protected, WCH-LinkE attach fails even though wiring, target power,
and the WCH-LinkE driver are fine.

Observed protected-state symptoms:

```text
WCH-LinkUtility:
Failed, the chip type is not matched or status of chip is wrong!

wlink:
Probe is not attached to an MCU, or debug is not enabled.
```

Observed bad config:

```text
CFG_DEBUG_EN = Disable
CFG_ROM_READ = Disable
```

Recovery that worked:

```powershell
# Put CH592 into USB Download mode.
# Bind only 4348:55E0 / USB Module to WinUSB with Zadig.
$wchisp = "$env:USERPROFILE\.platformio\packages\tool-wchisp\wchisp.exe"
& $wchisp config unprotect
```

After this, WCH-LinkUtility and MounRiver could identify the chip again. See
`docs/ch592_unprotect_recovery.md`.

If no WCH-Link attach is possible and the USB bootloader only flickers briefly, use
`docs/ch592_brick_recovery.md`.

## Current Result

WCH-LinkE programming through WCH-LinkUtility V2.90 is confirmed working:

```text
Core: RISC-V
Series: CH590/1/2
Active WCH-Link Mode: WCH-LinkRV
Target: Firmware/mounriver_ch592_led_probe/obj/mounriver_ch592_led_probe.hex
Erase All + Program + Verify + Reset and Run: PASS
```

That result proves the WCH-LinkE hardware path is good enough for WCH's GUI programming flow.

PlatformIO bundled `wlink` sees the WCH-LinkE probe, but target attach fails while the CH592 is running normally:

```text
Probe is not attached to an MCU, or debug is not enabled.
```

Earlier PlatformIO OpenOCD `wch-link` result:

```text
WCH-Link failed to connect with riscvchip
Make sure the two-line debug interface has been opened.
Please check your physical link connection.
```

Summary of the upload investigation:

```text
PlatformIO wlink while not in Download mode: WCH-LinkE is detected, then AttachChip fails.
PlatformIO wlink in Download mode: WCH-LinkE is detected, CH592 attaches, flash succeeds.
PlatformIO wch-link/OpenOCD while not in Download mode: WCH-LinkE is detected, then riscvchip connect fails.
USB ISP with PlatformIO wchisp: verify mismatch with the known-good MounRiver HEX.
USB ISP with WCHISPStudio V3.9 / WCHISPTool_CH57x-59x V3.10: PASS through official WCH driver.
```

Architecture note:

```text
PlatformIO tool-wlink package version: 0.23.241116+sha.f44158e
Bundled executable version: wlink 0.1.1
Bundled executable PE machine: 0x014C, x86 / PE32
```

The downloaded upstream `wlink 0.1.2` x86 build also works in Download mode. The downloaded `wlink 0.1.2` x64 build can list the probe through `nusb`, but status/flash fail with:

```text
USB error: incompatible driver is installed for this interface
```

Confirmed working `wlink` condition:

```text
Put CH592 into Download mode first.
Run wlink with explicit chip CH59X and low speed.
```

Important nuance from the 2026-05-17 recovery session:

```text
WCH-Link status/attach can succeed while wlink flash still fails during fast programming.
```

Observed after restoring USER_CFG `0x4FFF0FD5` with the USB recovery script:

```text
wlink status: PASS, attached CH59X [CH592]
wlink unprotect: PASS, read protected false
wlink flash small LED probe: FAIL, protocol 0x55 / fastprogram error
```

Therefore, do not assume `status` success proves the command-line flash path is healthy. If flash
fails but attach works, retry the exact manual Download-mode sequence or use MounRiver/WCH-LinkUtility
GUI before changing config bits again.

Working command:

```powershell
C:\Users\lukin\.platformio\packages\tool-wlink\wlink.exe flash --chip CH59X --speed low --erase --address 0x00000000 "Firmware\mounriver_ch592_led_probe\obj\mounriver_ch592_led_probe.hex"
```

Observed attach result in Download mode:

```text
Attached chip: CH59X [CH592] (ChipID: 0x92000000)
RISC-V ISA(misa): RV32ACIMUX
RISC-V arch(marchid): WCH-V4C
```

## Known Device State

| Item | Current note |
|---|---|
| WCH-LinkE VID/PID | `1A86:8010` when visible as WCH-Link |
| CH592 USB Download VID/PID | `4348:55E0` |
| WCH-LinkE mode | RV/RISC-V mode |
| Target power | Powered from board USB/switch |
| Target reference voltage | WCH-LinkE 3.3 V reference not required for this dev-board setup once target is powered |
| Debug wires | TIO/SWDIO, TCK/SWDCK, GND connected |
| Download mode | Required for current MounRiver GUI download flow and confirmed PlatformIO `wlink` upload flow |
| CH592 config | `CFG_DEBUG_EN = Enable`, `CFG_BOOT_EN = Enable`, `CFG_ROM_READ = Read enable` |
| WCH-LinkUtility GUI programming | PASS with `CH590/1/2`, address `0x00000000`, low clock |
| WCHISPStudio GUI native USB ISP | PASS with WCHISPStudio V3.9 / WCHISPTool_CH57x-59x V3.10 |

## Checks To Run

1. Confirm WCH-LinkE is in RV/RISC-V mode.
2. Confirm target is powered before attach.
3. Confirm common GND.
4. Confirm TIO/SWDIO and TCK/SWDCK continuity.
5. If attach suddenly stopped after ISP/config experiments, run `wchisp config unprotect`.
6. Try attach with target in normal run mode.
7. Try attach immediately after reset.
8. Try attach while target is held in Download mode.
9. Confirm MounRiver GUI still downloads successfully after any change.
10. Save `wlink status` or upload logs under `Firmware/docs/upload_logs/`.

## Interpretation

Because WCH-LinkUtility can erase, program, verify, reset, and then read back real code bytes from `0x00000000`, basic WCH-LinkE wiring and the HEX image are known good. The `wlink` path is also good when entered from Download mode.

They are not currently explained by:

```text
bad HEX file
missing target power
missing common ground
wrong TIO/TCK wiring
WCH-LinkE not being in RV mode
```

The likely remaining difference is board state: Download mode enables the WCH-LinkE attach/programming path on this dev board. Normal running firmware is not attachable by `wlink`/OpenOCD with the current setup.

Do not change the working WCH-LinkUtility driver binding just to satisfy `wlink` x64 unless we deliberately decide to risk the proven GUI flashing path. The `wlink` x86 path already reaches the WCHLinkDLL backend and works when the CH592 is in Download mode.

## Native USB ISP Driver Note

Native USB ISP is separate from WCH-LinkE. It uses the CH592 bootloader device:

```text
VID:PID 4348:55E0
```

On Windows, official WCHISPStudio and `ch32-rs/wchisp` expect different drivers for that same
device:

```text
WCHISPStudio V3.9: WCH CH375/WCHLink driver stack
wchisp / nusb / libusb: WinUSB/libusb-compatible binding
```

Only one binding can be active at a time. After the official WCH driver is active, `wchisp` reports
that no WinUSB/libusb driver is installed. This is a driver binding conflict, not a target wiring
problem.

## NorthPole Board Note

On the NorthPole board, PB14/PB15 are shared with IP5209 I2C through R15/R14 0 ohm links.

If debug attach is unreliable during board bring-up:

```text
Leave R14/R15 unpopulated temporarily, or remove them, so PB14/PB15 are dedicated to WCH-LinkE debug.
```

Normal firmware can use PB14/PB15 as IP5209 SDA/SCL only after debug/programming reliability is understood.

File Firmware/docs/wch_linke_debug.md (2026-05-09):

# WCH-LinkE Debug

J3 is the WCH-LinkE/debug connector.

| J3 pin | Function |
|---:|---|
| 1 | 3.3V target reference |
| 2 | TIO / SWDIO / PB14 / SDA-side MCU net |
| 3 | NC unless reset is later wired |
| 4 | TCK / SWDCK / PB15 / SCL-side MCU net |
| 5 | GND |
| 6 | NC |

PB14/PB15 are shared with IP5209 I2C through 0 ohm links:

| Link | Debug-side net | IP5209-side net |
|---|---|---|
| R15 | `/SWDIO` / PB14 / SDA | `/SDA` |
| R14 | `/SWDCK` / PB15 / SCL | `/SCL` |

Normal firmware uses PB14/PB15 as SDA/SCL. WCH-LinkE uses them as TIO/TCK. Do not expect IP5209 I2C access during active WCH-Link debugging.

If debug communication is unreliable, remove R14/R15 or leave them unpopulated temporarily so the IP5209 bus cannot load the debug pins.

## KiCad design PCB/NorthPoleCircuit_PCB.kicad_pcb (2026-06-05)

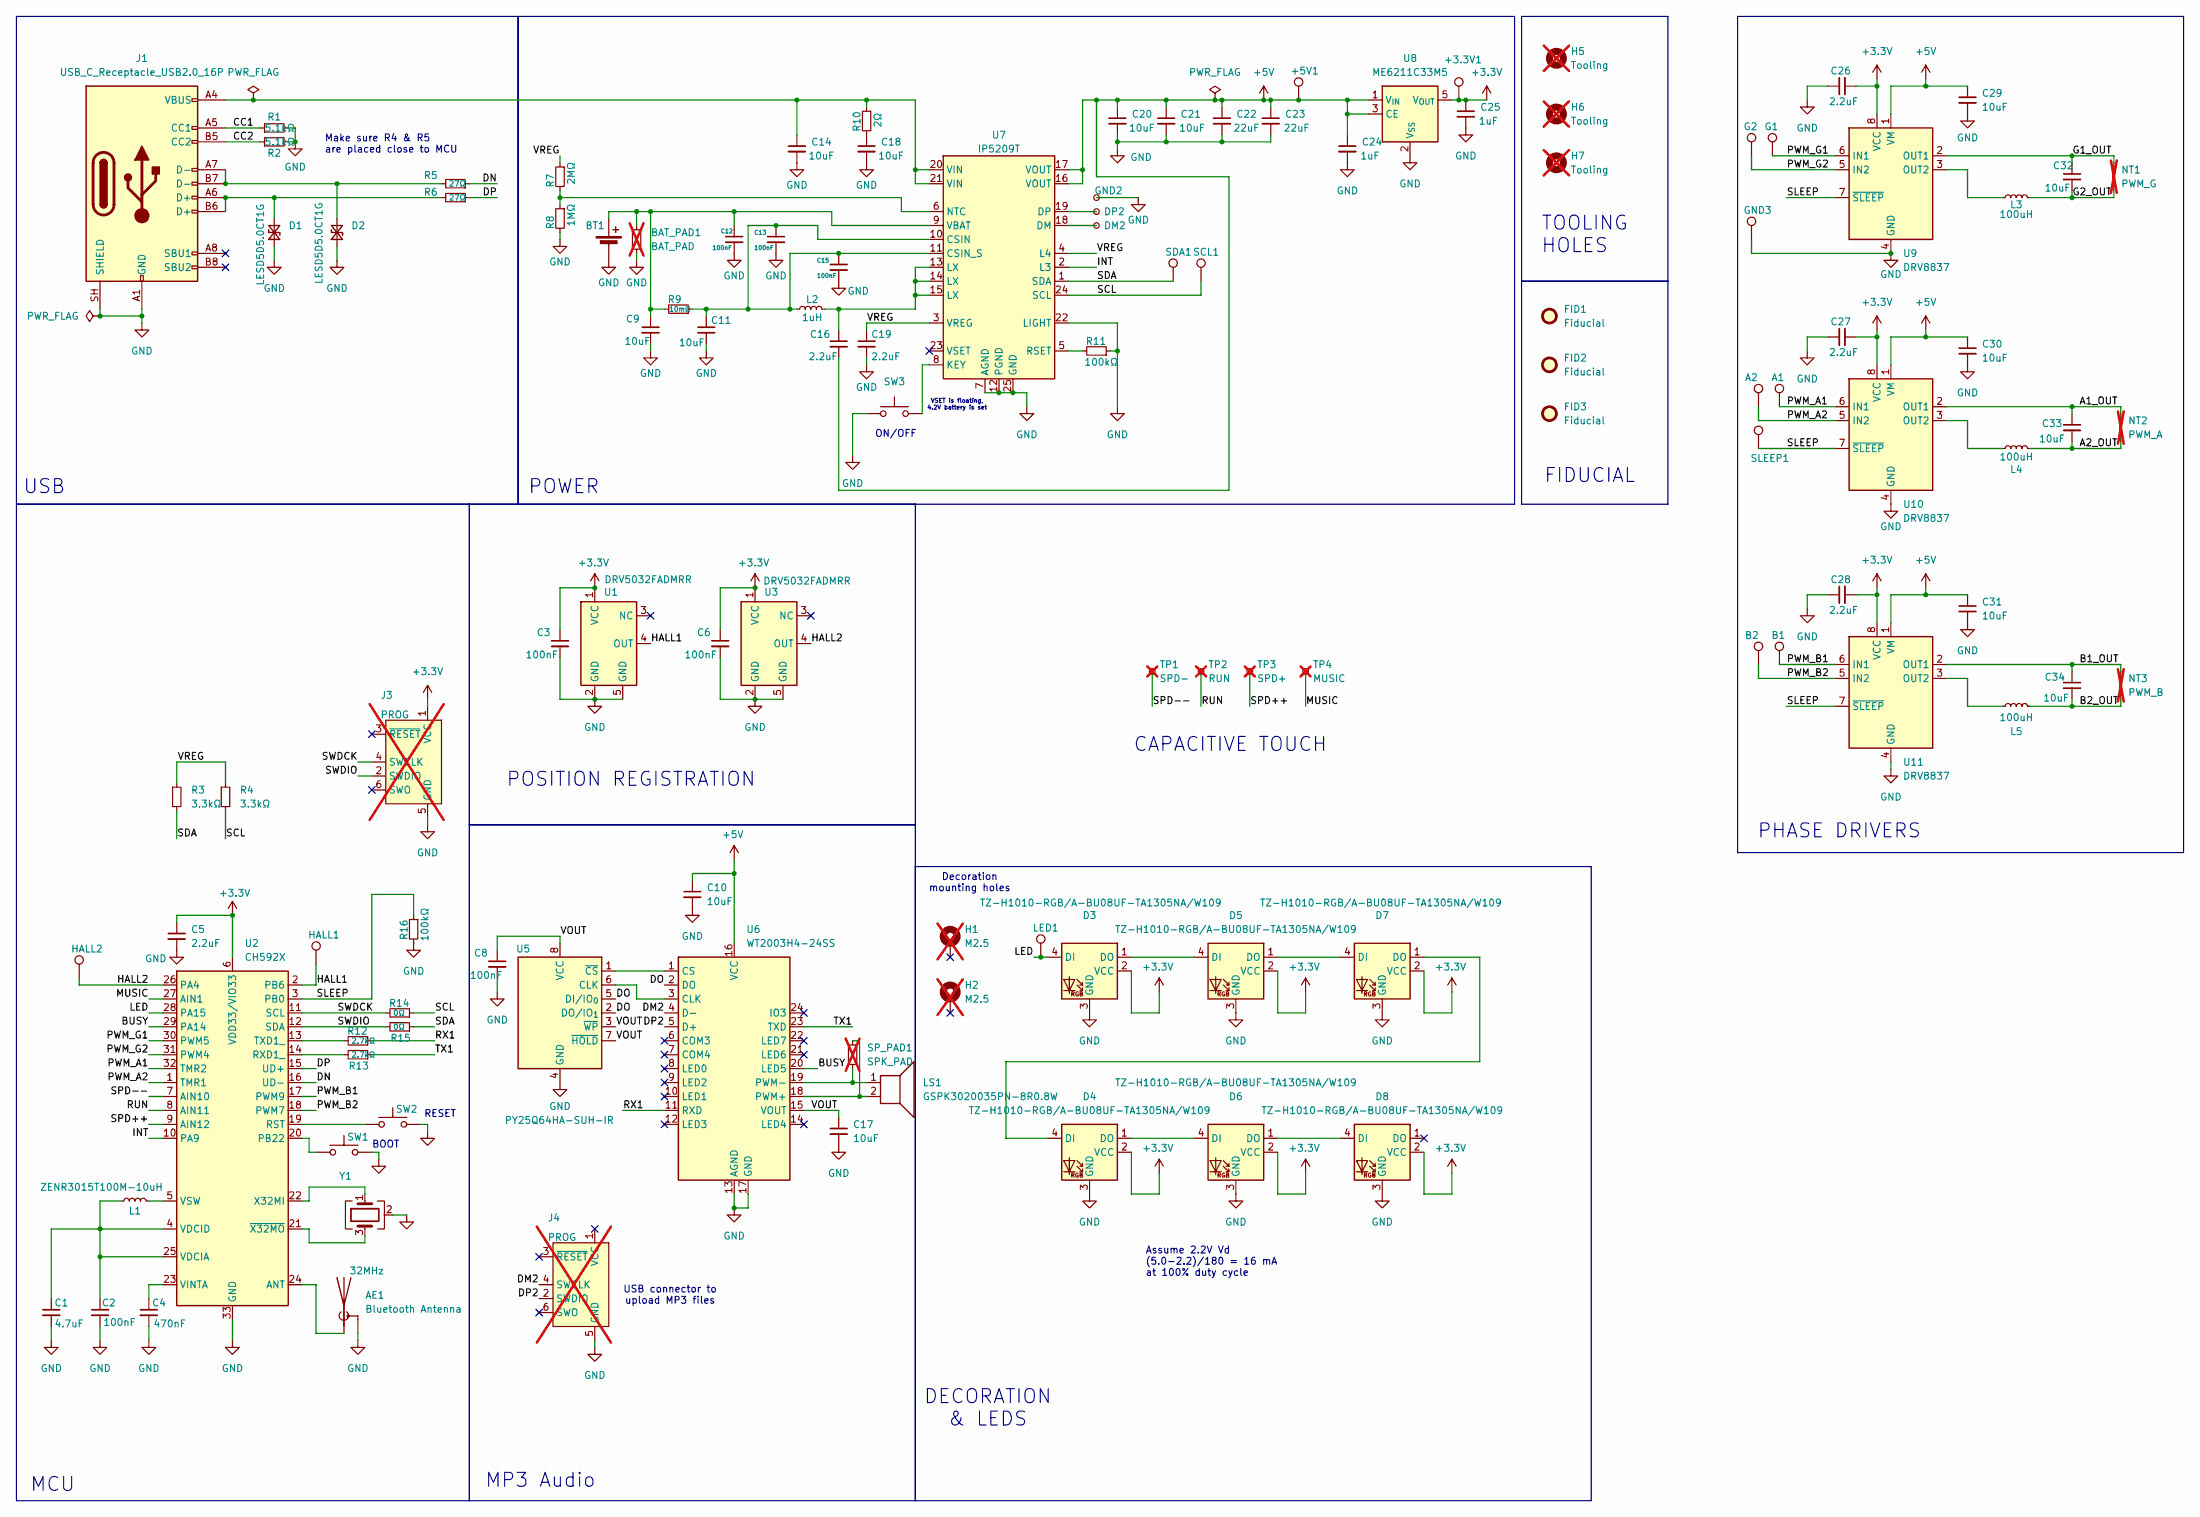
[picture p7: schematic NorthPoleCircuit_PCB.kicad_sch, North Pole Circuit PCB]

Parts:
+3.3V1: +3.3V; TestPoint_Pad_D1.5mm
+5V1: +5V; TestPoint_Pad_D1.5mm
A1: A1; TestPoint_Pad_D1.5mm
A2: A2; TestPoint_Pad_D1.5mm
AE1: Bluetooth Antenna; WCH_ANT_F_1_2_4G_1p0mmFR4_12p3x5p6
B1: B1; TestPoint_Pad_D1.5mm
B2: B2; TestPoint_Pad_D1.5mm
BAT_PAD1: BAT_PAD; Battery_LiPo_500mAh_30x35x4mm_WirePads; not fitted
BT1: LiPo_1S_500mAh; Battery_LiPo_500mAh_30x35x4mm_Body
C1: 4.7uF; C_1206_3216Metric; MPN CL31B475KAHNNNE; JLCPCB C1872
C2, C3, C6, C8, C12, C13, C15: 100nF; C_0402_1005Metric; MPN CL05B104KO5NNNC; JLCPCB C1525
C4: 470nF; C_1206_3216Metric; MPN CL31B474KBHNNNE; JLCPCB C71084
C5, C16, C19, C26, C27, C28: 2.2uF; C_1206_3216Metric; MPN CL31B225KBHNNNE; JLCPCB C50254
C9, C10, C11, C14, C17, C18, C20, C21, C29, C30, C31, C32, C33, C34: 10uF; C_1206_3216Metric; MPN CL31A106KBHNNNE; JLCPCB C13585
C22, C23: 22uF; C_1206_3216Metric; MPN CL31A226KAHNNNE; JLCPCB C12891
C24, C25: 1uF; C_1206_3216Metric; MPN CL31B105KBHNNNE; JLCPCB C1848
D1, D2: LESD5D5.0CT1G; D_SOD-523; MPN LESD5D5.0CT1G(UMW); JLCPCB C5199850
D3, D4, D5, D6, D7, D8: TZ-H1010-RGB/A-BU08UF-TA1305NA/W109; ws2812b_1010; MPN TZ-H1010-RGB/A-BU08UF-TA1305NA/W109; JLCPCB C41347988
DM2: TestPoint_Small; TestPoint_Pad_D1.0mm
DP2: TestPoint_Small; TestPoint_Pad_D1.0mm
FID1, FID2, FID3: Fiducial; Fiducial_0.75mm_Mask1.5mm
G1: G1; TestPoint_Pad_D1.5mm
G2: G2; TestPoint_Pad_D1.5mm
GND2: TestPoint_Small; TestPoint_Pad_D1.0mm
GND3: HALL2; TestPoint_Pad_D1.5mm
H1, H2: M2.5; MountingHole_2.7mm_M2.5_DIN965_Pad; not fitted
H5, H6, H7: Tooling; tooling_hole; not fitted
HALL1: HALL1; TestPoint_Pad_D1.5mm
HALL2: HALL2; TestPoint_Pad_D1.5mm
J1: USB_C_Receptacle_USB2.0_16P; USB_C_Receptacle_HRO_TYPE-C-31-M-12; MPN TYPE-C-31-M-12; JLCPCB C165948
J3, J4: PROG; Tag-Connect_TC2030-IDC-NL_2x03_P1.27mm_Vertical; not fitted
L1: ZENR3015T100M-10uH; L_Taiyo-Yuden_NR-30xx; MPN ZENR3015T100M-10uH; JLCPCB C42427989
L2: 1uH; L_Wuerth_HCI-7030; MPN MAPM0630F-1R0M-LF; JLCPCB C280920
L3, L4, L5: 100uH; SMMS0650-101M; MPN SMMS0650-101M; JLCPCB C2894722
LED1: LED; TestPoint_Pad_D1.5mm
LS1: GSPK3020035PN-8R0.8W
NT1: PWM_G; NetTie_1.25mm; not fitted
NT2: PWM_A; NetTie_1.25mm; not fitted
NT3: PWM_B; NetTie_1.25mm; not fitted
R1, R2: 5.1kΩ; R_0402_1005Metric; MPN 0402WGF5101TCE; JLCPCB C25905
R3, R4: 3.3kΩ; R_0402_1005Metric; MPN 0402WGF3301TCE; JLCPCB PN C25890
R5, R6: 27Ω; R_0402_1005Metric; MPN 0402WGF270JTCE; JLCPCB C25100
R7: 2MΩ; R_0805_2012Metric; MPN 0805W8J0205T5E; JLCPCB C40088
R8: 1MΩ; R_0402_1005Metric; MPN 0402WGF1004TCE; JLCPCB C26083
R9: 10mΩ; R_1206_3216Metric; MPN FRM121WFR010TM; JLCPCB C7467248
R10: 2Ω; R_0402_1005Metric; MPN 0402WGJ020JTCE; JLCPCB C25157
R11, R16: 100kΩ; R_0402_1005Metric; MPN 0402WGF1003TCE; JLCPCB C25741
R12, R13: 2.7kΩ; R_0402_1005Metric; MFR.Part # 0402WGF2701TCE; LCSC Part C25885
R14, R15: 0Ω; R_0402_1005Metric; MFR.Part # 0402WGF0000TCE; LCSC Part C17168
SCL1: SCL; TestPoint_Pad_D1.5mm
SDA1: SDA; TestPoint_Pad_D1.5mm
SLEEP1: SLEEP; TestPoint_Pad_D1.5mm
SP_PAD1: SPK_PAD; Speaker_GSPK3020035PN_WirePads; not fitted
SW1, SW2: TS-1088-AR02016; SW_Push_SPST_NO_Alps_SKRK; MPN TS-1088-AR02016; JLCPCB C720477
SW3: TS-1187A-C-E-B; SW_SPST_SKQG_WithStem; MPN TS-1187A-C-E-B; JLCPCB C318887
TP1: SPD-; Cap_Touch_10mm; not fitted
TP2: RUN; Cap_Touch_10mm; not fitted
TP3: SPD+; Cap_Touch_10mm; not fitted
TP4: MUSIC; Cap_Touch_10mm; not fitted
U1, U3: DRV5032FADMRR; Texas_X2SON-4-1EP_1.1x1.4mm_P0.5mm_EP0.8x0.6mm; MPN DRV5032FADMRR; JLCPCB C2152496
U2: CH592X; QFN-32-1EP_4x4mm_P0.4mm_EP2.65x2.65mm; MPN CH592X; JLCPCB C42442063
U5: PY25Q64HA-SUH-IR; SOIC-8_5.3x5.3mm_P1.27mm; MPN PY25Q64HA-SUH-IR; JLCPCB C22438999
U6: WT2003H4-24SS; SSOP-24_3.9x8.7mm_P0.635mm; MPN WT2003H4-24SS; JLCPCB C2931181
U7: IP5209T; QFN-24-1EP_4x4mm_P0.5mm_EP2.5x2.5mm; MPN IP5209T; JLCPCB C284964
U8: ME6211C33M5; SOT-23-5; MPN ME6211C33M5G-N; JLCPCB C82942
U9, U10, U11: DRV8837; WSON-8-1EP_2x2mm_P0.5mm_EP0.9x1.6mm; MPN DRV8837DSGR; JLCPCB C39159
Y1: 32MHz; Crystal_SMD_3225-4Pin_3.2x2.5mm; MPN X322532MOB4SI; LCSC Part C9009

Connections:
+3.3V: +3.3V1.1 (1_1), C3.1, C5.1, C6.1, C25.1, C26.2, C27.2, C28.2, D3.2 (VCC), D4.2 (VCC), D5.2 (VCC), D6.2 (VCC), D7.2 (VCC), D8.2 (VCC), J3.1 (VCC), U1.1 (VCC), U2.6 (VDD33/VIO33), U3.1 (VCC), U8.5 (V_{OUT}), U9.8 (VCC), U10.8 (VCC), U11.8 (VCC)
+5V: +5V1.1 (1_1), C10.1, C16.2, C20.1, C21.1, C22.1, C23.1, C24.1, C29.1, C30.1, C31.1, U6.16 (VCC), U7.16 (VOUT), U7.17 (VOUT), U8.1 (V_{IN}), U8.3 (CE), U9.1 (VM), U10.1 (VM), U11.1 (VM)
/A1_OUT: C33.1, NT2.2, U10.2 (OUT1)
/A2_OUT: C33.2, L4.2, NT2.1
/B1_OUT: C34.1, NT3.2, U11.2 (OUT1)
/B2_OUT: C34.2, L5.2, NT3.1
/BUSY: U2.29 (PA14), U6.20 (LED5)
/CC1: J1.A5 (CC1), R1.1
/CC2: J1.B5 (CC2), R2.1
/DM2: J4.4 (SWCLK), U6.4 (D-)
/DN: R5.1, U2.16 (UD-)
/DO: U5.2 (DO/IO_{1}), U5.5 (DI/IO_{0}), U6.2 (DO)
/DP: R6.1, U2.15 (UD+)
/DP2: J4.2 (SWDIO), U6.5 (D+)
/G1_OUT: C32.1, NT1.2, U9.2 (OUT1)
/G2_OUT: C32.2, L3.2, NT1.1
/INT: U2.10 (PA9), U7.2 (L3)
/LED: D3.4 (DI), LED1.1 (1_1), U2.28 (PA15)
/MUSIC: TP4.1 (1_1), U2.27 (AIN1)
/PWM_A1: A1.1 (1_1), U2.32 (TMR2), U10.6 (IN1)
/PWM_A2: A2.1 (1_1), U2.1 (TMR1), U10.5 (IN2)
/PWM_B1: B1.1 (1_1), U2.17 (PWM9), U11.6 (IN1)
/PWM_B2: B2.1 (1_1), U2.18 (PWM7), U11.5 (IN2)
/PWM_G1: G1.1 (1_1), U2.30 (PWM5), U9.6 (IN1)
/PWM_G2: G2.1 (1_1), U2.31 (PWM4), U9.5 (IN2)
/RUN: TP2.1 (1_1), U2.8 (AIN11)
/RX1: R12.1, U6.11 (RXD)
/SCL: R4.2, R14.1, SCL1.1 (1_1), U7.24 (SCL)
/SDA: R3.2, R15.1, SDA1.1 (1_1), U7.1 (SDA)
/SLEEP: R16.1, SLEEP1.1 (1_1), U2.3 (PB0), U9.7 (~SLEEP), U10.7 (~SLEEP), U11.7 (~SLEEP)
/SPD++: TP3.1 (1_1), U2.9 (AIN12)
/SPD--: TP1.1 (1_1), U2.7 (AIN10)
/SWDCK: J3.4 (SWCLK), R14.2, U2.11 (SCL)
/SWDIO: J3.2 (SWDIO), R15.2, U2.12 (SDA)
/TX1: R13.1, U6.23 (TXD)
/VOUT: C8.1, C17.1, U5.3 (~WP), U5.7 (~HOLD), U5.8 (VCC), U6.15 (VOUT)
/VREG: C19.1, R3.1, R4.1, R7.1, U7.3 (VREG), U7.4 (L4)
unnamed: AE1.1 (A), U2.24 (ANT)
unnamed: C14.1, J1.A4 (VBUS), J1.A9 (VBUS), J1.B4 (VBUS), J1.B9 (VBUS), R10.1, U7.20 (VIN), U7.21 (VIN)
unnamed: C16.1, L2.2, U7.13 (LX), U7.14 (LX), U7.15 (LX)
unnamed: C18.1, R10.2
unnamed: D1.2 (A2), J1.A6 (D+), J1.B6 (D+), R6.2
unnamed: D2.2 (A2), J1.A7 (D-), J1.B7 (D-), R5.2
unnamed: D3.1 (DO), D5.4 (DI)
unnamed: D4.4 (DI), D7.1 (DO)
unnamed: D4.1 (DO), D6.4 (DI)
unnamed: D5.1 (DO), D7.4 (DI)
unnamed: D6.1 (DO), D8.4 (DI)
unnamed: R13.2, U2.14 (RXD1_)
unnamed: R12.2, U2.13 (TXD1_)
unnamed: SW1.1, U2.20 (PB22)
unnamed: SW2.1, U2.19 (RST)
unnamed: C1.1, C2.1, L1.1, U2.4 (VDCID), U2.25 (VDCIA)
unnamed: C4.1, U2.23 (VINTA)
unnamed: L1.2, U2.5 (VSW)
unnamed: U2.22 (X32MI), Y1.1
unnamed: U2.21 (~X32MO), Y1.3
unnamed: U5.6 (CLK), U6.3 (CLK)
unnamed: U5.1 (~CS), U6.1 (CS)
unnamed: LS1.2, SP_PAD1.1, U6.18 (PWM+)
unnamed: LS1.1, SP_PAD1.2, U6.19 (PWM-)
unnamed: C11.1, C13.1, C15.1, L2.1, R9.1, U7.10 (CSIN), U7.11 (CSIN_S)
unnamed: DM2.1 (1_1), U7.18 (DM)
unnamed: DP2.1 (1_1), U7.19 (DP)
unnamed: SW3.2, U7.8 (KEY)
unnamed: R7.2, R8.1, U7.6 (NTC)
unnamed: R11.2, U7.5 (RSET)
unnamed: BAT_PAD1.1, BT1.1 (+), C9.1, C12.1, R9.2, U7.9 (VBAT)
unnamed: L3.1, U9.3 (OUT2)
unnamed: L4.1, U10.3 (OUT2)
unnamed: L5.1, U11.3 (OUT2)

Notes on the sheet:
MCU
RESET
DECORATION & LEDS
USB
POWER
FIDUCIAL
CAPACITIVE TOUCH
USB connector to upload MP3 files
POSITION REGISTRATION
ON/OFF
Decoration mounting holes
TOOLING HOLES
MP3 Audio
Assume 2.2V Vd (5.0-2.2)/180 = 16 mA at 100% duty cycle
Make sure R4 & R5 are placed close to MCU
BOOT
PHASE DRIVERS
VSET is floating, 4.2V battery is set

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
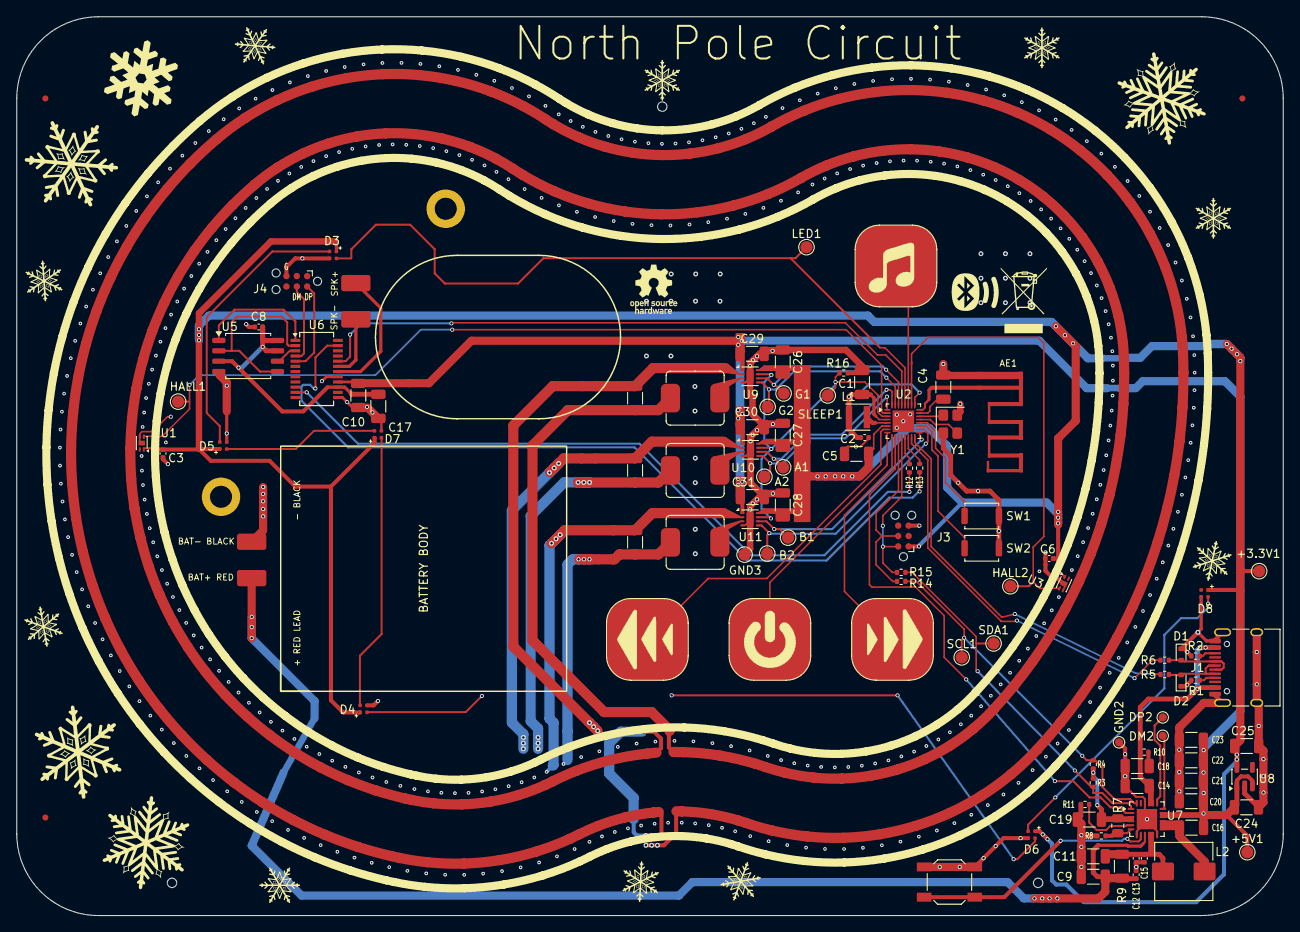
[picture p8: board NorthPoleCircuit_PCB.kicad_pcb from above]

Board: 4 copper layers, 155.0 x 110.0 mm, 117 parts (0 on the bottom side), 74 nets.

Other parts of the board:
BT1_BODY: LiPo_1S_500mAh; Battery_LiPo_500mAh_30x35x4mm_Body
LS1_BODY: GSPK3020035PN-8R0.8W; Speaker_GSPK3020035PN_Body

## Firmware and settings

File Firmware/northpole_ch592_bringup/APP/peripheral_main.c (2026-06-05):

/********************************** (C) COPYRIGHT *******************************
 * File Name          : peripheral_main.c
 * Author             : WCH / North Pole firmware bring-up
 * Version            : V0.1
 * Description        : CH592 BLE peripheral startup with North Pole safe bring-up.
 ********************************************************************************/

#include "CONFIG.h"
#include "HAL.h"
#include "app_bringup.h"
#include "app_config.h"
#include "gattprofile.h"
#include "northpole_broadcaster.h"
#include "northpole_ch592_port.h"
#include "peripheral.h"

__attribute__((aligned(4))) uint32_t MEM_BUF[BLE_MEMHEAP_SIZE / 4];

#if(defined(BLE_MAC)) && (BLE_MAC == TRUE)
const uint8_t MacAddr[6] = {0x84, 0xC2, 0xE4, 0x03, 0x02, 0x02};
#endif

__HIGH_CODE
__attribute__((noinline))
void Main_Circulation(void)
{
    while(1)
    {
        TMOS_SystemProcess();
#if (!APP_DEV_BOARD_BLE_SMOKE || APP_DEV_BOARD_BRINGUP_APP_SMOKE) && !APP_DEV_BOARD_BLE_BROADCASTER_SMOKE
        app_bringup_poll();
#endif
    }
}

int main(void)
{
#if(defined(DCDC_ENABLE)) && (DCDC_ENABLE == TRUE)
    PWR_DCDCCfg(ENABLE);
#endif

    SetSysClock(CLK_SOURCE_PLL_60MHz);
#if !APP_DEV_BOARD_SKIP_NORTHPOLE_SAFE_PINS && APP_TARGET_ENABLE_EARLY_SAFE_PINS
    northpole_ch592_early_safe_pins();
#endif

#if(defined(HAL_SLEEP)) && (HAL_SLEEP == TRUE)
    GPIOA_ModeCfg(GPIO_Pin_All, GPIO_ModeIN_PU);
    GPIOB_ModeCfg(GPIO_Pin_All, GPIO_ModeIN_PU);
    /* HAL sleep examples blanket-configure GPIOs. Reassert motor-safe outputs
     * immediately so DRV8837 IN pins and PB0 /SLEEP are safe before BLE/HAL/app init.
     * Dev-board smoke builds deliberately skip this because NorthPole motor
     * pins conflict with CH592X-EVT-R1-LinkE crystal/USB/LCD pins.
     */
#if !APP_DEV_BOARD_SKIP_NORTHPOLE_SAFE_PINS && APP_TARGET_ENABLE_EARLY_SAFE_PINS
    northpole_ch592_early_safe_pins();
#endif
#endif

#if APP_DEV_BOARD_BLE_SMOKE || APP_DEV_BOARD_BLE_BROADCASTER_SMOKE || APP_DEV_BOARD_BRINGUP_APP_SMOKE || APP_TARGET_USE_EVT_UART_DEBUG_STARTUP
#ifdef DEBUG
    /* Keep dev-board BLE smoke startup close to WCH EVT examples. The proven
     * Broadcaster path initializes default UART1 and prints VER_LIB before
     * CH59x_BLEInit(); preserve that sequence while isolating BLE startup.
     * On target hardware this routes UART1 to the WT2003 path, so it is only
     * enabled by explicit debug-isolation builds.
     */
    GPIOA_SetBits(bTXD1);
    GPIOA_ModeCfg(bTXD1, GPIO_ModeOut_PP_5mA);
    UART1_DefInit();
#endif
    PRINT("%s\n", VER_LIB);
#else
#ifdef DEBUG
    northpole_ch592_debug_uart_init();
#endif
#endif

    CH59x_BLEInit();
    HAL_Init();
#if APP_DEV_BOARD_BLE_BROADCASTER_SMOKE
    GAPRole_BroadcasterInit();
    NorthPole_Broadcaster_Init();
#else
    GAPRole_PeripheralInit();
    Peripheral_Init();
#if !APP_DEV_BOARD_BLE_SMOKE || APP_DEV_BOARD_BRINGUP_APP_SMOKE
    app_bringup_init();
#endif
#endif
    Main_Circulation();
}

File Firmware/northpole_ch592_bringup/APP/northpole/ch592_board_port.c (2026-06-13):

#include "northpole_ch592_port.h"

#include "CONFIG.h"
#include "app_config.h"
#include "audio_wt2003.h"
#include "board.h"
#include "i2c_bus.h"
#include "motor_drv8837.h"
#include "power_ip5209.h"
#include "rgb_ws2812.h"
#include "shell.h"
#include "timebase.h"
#include "usb_cdc_shell.h"

#include <stddef.h>
#include <stdint.h>
#include <string.h>

#ifndef NORTHPOLE_ENABLE_UART1_LOG
#define NORTHPOLE_ENABLE_UART1_LOG 0
#endif

#ifndef NORTHPOLE_ENABLE_WT2003_UART
#define NORTHPOLE_ENABLE_WT2003_UART 1
#endif

#if APP_TARGET_SAFE_ENABLE_MOTOR_A
#define CH592_GPIOA_MOTOR_A_SAFE_MASK (bTMR1 | bTMR2)
#else
#define CH592_GPIOA_MOTOR_A_SAFE_MASK 0u
#endif

#if APP_TARGET_SAFE_ENABLE_MOTOR_G
#define CH592_GPIOA_MOTOR_G_SAFE_MASK (bPWM5 | bPWM4)
#else
#define CH592_GPIOA_MOTOR_G_SAFE_MASK 0u
#endif

#if APP_TARGET_SAFE_ENABLE_MOTOR_B
#define CH592_GPIOB_MOTOR_B_SAFE_MASK (bPWM9 | bPWM7)
#else
#define CH592_GPIOB_MOTOR_B_SAFE_MASK 0u
#endif

#if APP_TARGET_SAFE_ENABLE_MOTOR_SLEEP
#define CH592_GPIOB_MOTOR_SLEEP_SAFE_MASK (GPIO_Pin_0)
#else
#define CH592_GPIOB_MOTOR_SLEEP_SAFE_MASK 0u
#endif

#define CH592_GPIOA_RGB_PA15_MASK (GPIO_Pin_15)
#define CH592_GPIOA_RGB_PA14_MASK (GPIO_Pin_14)
#define CH592_GPIOA_RGB_SPI0_MOSI_MASK CH592_GPIOA_RGB_PA14_MASK

#if APP_RGB_WS2812_USE_SPI0_MOSI_PA14 || APP_RGB_WS2812_USE_PA14_BITBANG
#define CH592_GPIOA_RGB_MASK CH592_GPIOA_RGB_PA14_MASK
#else
#define CH592_GPIOA_RGB_MASK CH592_GPIOA_RGB_PA15_MASK
#endif

#if APP_TARGET_SAFE_ENABLE_RGB_DATA
#define CH592_GPIOA_RGB_SAFE_MASK CH592_GPIOA_RGB_MASK
#else
#define CH592_GPIOA_RGB_SAFE_MASK 0u
#endif

#define CH592_GPIOA_SAFE_OUTPUT_LOW_MASK \
    (CH592_GPIOA_MOTOR_A_SAFE_MASK | CH592_GPIOA_MOTOR_G_SAFE_MASK | CH592_GPIOA_RGB_SAFE_MASK)
#define CH592_GPIOB_SAFE_OUTPUT_LOW_MASK \
    (CH592_GPIOB_MOTOR_B_SAFE_MASK | CH592_GPIOB_MOTOR_SLEEP_SAFE_MASK)

#define MOTOR_PWMX_CHANNELS (CH_PWM4 | CH_PWM5 | CH_PWM7 | CH_PWM9)
#define MOTOR_PWMX_CLOCK_DIV 4u
#define MOTOR_WAVE_TARGET_A NORTHPOLE_MOTOR_WAVE_TARGET_A
#define MOTOR_WAVE_TARGET_B NORTHPOLE_MOTOR_WAVE_TARGET_B
#define MOTOR_WAVE_TARGET_G NORTHPOLE_MOTOR_WAVE_TARGET_G
#define MOTOR_WAVE_DMA_MAX_ENTRIES 256u
#define MOTOR_WAVE_TABLE_SIZE 256u
#define MOTOR_WAVE_PHASE_SHIFT_90 64u

#if defined(FREQ_SYS) && (FREQ_SYS != APP_WS2812_BITBANG_ASSUMED_FREQ_SYS_HZ)
#warning "WS2812 bit-bang timing assumes 60 MHz FREQ_SYS; validate timing or retune NOP counts before using RGB."
#endif

typedef enum {
    HW_PORT_NONE = 0,
    HW_PORT_A,
    HW_PORT_B,
} hw_port_t;

typedef struct {
    hw_port_t port;
    uint32_t mask;
} hw_pin_t;

static uint8_t audio_uart_ready;
static uint8_t debug_uart_ready;
static uint32_t motor_pwm_hz = APP_MOTOR_PWM_DEFAULT_HZ;
static uint32_t motor_control_update_hz = APP_MOTOR_CONTROL_UPDATE_HZ;
static uint32_t motor_timer_cycle_ticks;
static uint16_t motor_pwmx_cycle_ticks;
static uint8_t motor_pwm_platform_initialized;

typedef struct {
    volatile uint8_t running;
    volatile uint8_t target_flags;
    volatile uint8_t sleep_high;
    volatile uint8_t dma_mode;
    volatile uint8_t dma_error;
    volatile uint8_t phase;
    volatile int8_t direction;
    volatile uint8_t guard_mode;
    volatile uint16_t sine_table_size;
    volatile uint16_t amplitude_permille;
    volatile uint16_t guard_duty_permille;
    volatile uint32_t control_update_hz;
    volatile uint32_t electrical_hz_x1000;
    volatile uint32_t actual_electrical_hz_x1000;
    volatile uint32_t phase_acc;
    volatile uint32_t phase_inc;
    volatile uint32_t sample_ticks;
    volatile uint32_t tick_count;
    volatile uint32_t missed_update_count;
    volatile uint32_t dma_entries;
    volatile uint32_t dma_repeat_per_sample;
} motor_wave_runtime_t;

static motor_wave_runtime_t motor_wave;

#if APP_MOTOR_PWM_BACKEND_ENABLE
static __attribute__((aligned(4))) uint32_t motor_wave_dma_a1[MOTOR_WAVE_DMA_MAX_ENTRIES];
static __attribute__((aligned(4))) uint32_t motor_wave_dma_a2[MOTOR_WAVE_DMA_MAX_ENTRIES];
#endif
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

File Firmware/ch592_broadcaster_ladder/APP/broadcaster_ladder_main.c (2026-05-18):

#include "CONFIG.h"
#include "HAL.h"
#include "broadcaster_ladder.h"

#ifndef LADDER_USE_NORTHPOLE_BROADCASTER
#define LADDER_USE_NORTHPOLE_BROADCASTER 0
#endif

#ifndef LADDER_LINK_NORTHPOLE_MODULES
#define LADDER_LINK_NORTHPOLE_MODULES 0
#endif

#ifndef LADDER_INIT_NORTHPOLE_CORE
#define LADDER_INIT_NORTHPOLE_CORE 0
#endif

#ifndef LADDER_INIT_NORTHPOLE_BOARD_SAFE
#define LADDER_INIT_NORTHPOLE_BOARD_SAFE 0
#endif

#ifndef LADDER_LINK_FULL_NORTHPOLE_APP
#define LADDER_LINK_FULL_NORTHPOLE_APP 0
#endif

#if LADDER_USE_NORTHPOLE_BROADCASTER
#include "northpole_broadcaster.h"
#endif

#if LADDER_INIT_NORTHPOLE_CORE
#include "fault.h"
#include "log.h"
#include "settings.h"
#include "timebase.h"
#endif

#if LADDER_INIT_NORTHPOLE_BOARD_SAFE
#include "board.h"
#endif

__attribute__((aligned(4))) uint32_t MEM_BUF[BLE_MEMHEAP_SIZE / 4];

#if(defined(BLE_MAC)) && (BLE_MAC == TRUE)
const uint8_t MacAddr[6] = {0x84, 0xC2, 0xE4, 0x03, 0x02, 0x02};
#endif

__HIGH_CODE
__attribute__((noinline))
void Main_Circulation(void)
{
    while(1) {
        TMOS_SystemProcess();
    }
}

int main(void)
{
#if(defined(DCDC_ENABLE)) && (DCDC_ENABLE == TRUE)
    PWR_DCDCCfg(ENABLE);
#endif

    SetSysClock(CLK_SOURCE_PLL_60MHz);

#if LADDER_INIT_NORTHPOLE_CORE
    timebase_init();
    log_init(LOG_LEVEL_INFO);
    fault_init();
    settings_init();
#endif

#if LADDER_INIT_NORTHPOLE_BOARD_SAFE
    board_init_safe_pins();
#endif

#if(defined(HAL_SLEEP)) && (HAL_SLEEP == TRUE)
    GPIOA_ModeCfg(GPIO_Pin_All, GPIO_ModeIN_PU);
    GPIOB_ModeCfg(GPIO_Pin_All, GPIO_ModeIN_PU);
#endif

#ifdef DEBUG
    GPIOA_SetBits(bTXD1);
    GPIOA_ModeCfg(bTXD1, GPIO_ModeOut_PP_5mA);
    UART1_DefInit();
#endif

    PRINT("%s\n", VER_LIB);

#if LADDER_LINK_NORTHPOLE_MODULES
    PRINT("NorthPole support modules linked\n");
#endif

    CH59x_BLEInit();
    HAL_Init();
    GAPRole_BroadcasterInit();
#if LADDER_USE_NORTHPOLE_BROADCASTER
    NorthPole_Broadcaster_Init();
#else
    Broadcaster_Ladder_Init();
#endif
    Main_Circulation();
}

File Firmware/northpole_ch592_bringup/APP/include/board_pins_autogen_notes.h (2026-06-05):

/* Auto-generated by Firmware/tools/extract_kicad_pinmap.py. */
/* Do not edit by hand; rerun the extractor after KiCad changes. */
#ifndef BOARD_PINS_AUTOGEN_NOTES_H
#define BOARD_PINS_AUTOGEN_NOTES_H

#define BOARD_AUTOGEN_PCB_SHA256 "80ec7a54917bd0ee"
#define BOARD_AUTOGEN_SCH_SHA256 "a72fa80a1a631e47"
#define BOARD_AUTOGEN_AUDIO_UART_CONNECTED 1
#define BOARD_AUTOGEN_AUDIO_HW_BLOCKED 0
#define BOARD_AUTOGEN_RGB_LED_COUNT 6

#define BOARD_U2_PAD_1_FUNCTION "TMR1_1"
#define BOARD_U2_PAD_1_NET "/PWM_A2"
#define BOARD_U2_PAD_1_PINTYPE "bidirectional"
#define BOARD_U2_PAD_2_FUNCTION "PB6_2"
#define BOARD_U2_PAD_2_NET "/HALL1"
#define BOARD_U2_PAD_2_PINTYPE "bidirectional"
#define BOARD_U2_PAD_3_FUNCTION "PB0_3"
#define BOARD_U2_PAD_3_NET "/SLEEP"
#define BOARD_U2_PAD_3_PINTYPE "bidirectional"
#define BOARD_U2_PAD_4_FUNCTION "VDCID_4"
#define BOARD_U2_PAD_4_NET "Net-(U2-VDCIA)"
#define BOARD_U2_PAD_4_PINTYPE "passive"
#define BOARD_U2_PAD_5_FUNCTION "VSW_5"
#define BOARD_U2_PAD_5_NET "Net-(U2-VSW)"
#define BOARD_U2_PAD_5_PINTYPE "passive"
#define BOARD_U2_PAD_6_FUNCTION "VDD33/VIO33_6"
#define BOARD_U2_PAD_6_NET "+3.3V"
#define BOARD_U2_PAD_6_PINTYPE "power_in"
#define BOARD_U2_PAD_7_FUNCTION "AIN10_7"
#define BOARD_U2_PAD_7_NET "/SPD--"
#define BOARD_U2_PAD_7_PINTYPE "input"
#define BOARD_U2_PAD_8_FUNCTION "AIN11_8"
#define BOARD_U2_PAD_8_NET "/RUN"
#define BOARD_U2_PAD_8_PINTYPE "input"
#define BOARD_U2_PAD_9_FUNCTION "AIN12_9"
#define BOARD_U2_PAD_9_NET "/SPD++"
#define BOARD_U2_PAD_9_PINTYPE "input"
#define BOARD_U2_PAD_10_FUNCTION "PA9_10"
#define BOARD_U2_PAD_10_NET "/INT"
#define BOARD_U2_PAD_10_PINTYPE "bidirectional"
#define BOARD_U2_PAD_11_FUNCTION "SCL_11"
#define BOARD_U2_PAD_11_NET "/SWDCK"
#define BOARD_U2_PAD_11_PINTYPE "bidirectional"
#define BOARD_U2_PAD_12_FUNCTION "SDA_12"
#define BOARD_U2_PAD_12_NET "/SWDIO"
#define BOARD_U2_PAD_12_PINTYPE "bidirectional"
#define BOARD_U2_PAD_13_FUNCTION "TXD1__13"
#define BOARD_U2_PAD_13_NET "Net-(U2-PB13)"
#define BOARD_U2_PAD_13_PINTYPE "output"
#define BOARD_U2_PAD_14_FUNCTION "RXD1__14"
#define BOARD_U2_PAD_14_NET "Net-(U2-PB12)"
#define BOARD_U2_PAD_14_PINTYPE "input"
#define BOARD_U2_PAD_15_FUNCTION "UD+_15"
#define BOARD_U2_PAD_15_NET "/DP"
#define BOARD_U2_PAD_15_PINTYPE "bidirectional"
#define BOARD_U2_PAD_16_FUNCTION "UD-_16"
#define BOARD_U2_PAD_16_NET "/DN"
#define BOARD_U2_PAD_16_PINTYPE "bidirectional"
#define BOARD_U2_PAD_17_FUNCTION "PWM9_17"
#define BOARD_U2_PAD_17_NET "/PWM_B1"
#define BOARD_U2_PAD_17_PINTYPE "output"
#define BOARD_U2_PAD_18_FUNCTION "PWM7_18"
#define BOARD_U2_PAD_18_NET "/PWM_B2"
#define BOARD_U2_PAD_18_PINTYPE "output"
#define BOARD_U2_PAD_19_FUNCTION "RST_19"
#define BOARD_U2_PAD_19_NET "Net-(U2-PB23)"
#define BOARD_U2_PAD_19_PINTYPE "bidirectional"
#define BOARD_U2_PAD_20_FUNCTION "PB22_20"
#define BOARD_U2_PAD_20_NET "Net-(U2-PB22)"
#define BOARD_U2_PAD_20_PINTYPE "bidirectional"
#define BOARD_U2_PAD_21_FUNCTION "~{X32MO}_21"
#define BOARD_U2_PAD_21_NET "Net-(U2-~{X32MO})"
#define BOARD_U2_PAD_21_PINTYPE "output"
#define BOARD_U2_PAD_22_FUNCTION "X32MI_22"
#define BOARD_U2_PAD_22_NET "Net-(U2-X32MI)"
#define BOARD_U2_PAD_22_PINTYPE "input"
#define BOARD_U2_PAD_23_FUNCTION "VINTA_23"
#define BOARD_U2_PAD_23_NET "Net-(U2-VINTA)"
#define BOARD_U2_PAD_23_PINTYPE "passive"
#define BOARD_U2_PAD_24_FUNCTION "ANT_24"
#define BOARD_U2_PAD_24_NET "Net-(AE1-A)"
#define BOARD_U2_PAD_24_PINTYPE "bidirectional"
#define BOARD_U2_PAD_25_FUNCTION "VDCIA_25"
#define BOARD_U2_PAD_25_NET "Net-(U2-VDCIA)"
#define BOARD_U2_PAD_25_PINTYPE "passive"
#define BOARD_U2_PAD_26_FUNCTION "PA4_26"
#define BOARD_U2_PAD_26_NET "/HALL2"
#define BOARD_U2_PAD_26_PINTYPE "bidirectional"
#define BOARD_U2_PAD_27_FUNCTION "AIN1_27"
#define BOARD_U2_PAD_27_NET "/MUSIC"
#define BOARD_U2_PAD_27_PINTYPE "input"
#define BOARD_U2_PAD_28_FUNCTION "PA15_28"
#define BOARD_U2_PAD_28_NET "/LED"
#define BOARD_U2_PAD_28_PINTYPE "bidirectional"
#define BOARD_U2_PAD_29_FUNCTION "PA14_29"
#define BOARD_U2_PAD_29_NET "/BUSY"
#define BOARD_U2_PAD_29_PINTYPE "bidirectional"
#define BOARD_U2_PAD_30_FUNCTION "PWM5_30"
#define BOARD_U2_PAD_30_NET "/PWM_G1"
#define BOARD_U2_PAD_30_PINTYPE "output"
#define BOARD_U2_PAD_31_FUNCTION "PWM4_31"
#define BOARD_U2_PAD_31_NET "/PWM_G2"
#define BOARD_U2_PAD_31_PINTYPE "output"
#define BOARD_U2_PAD_32_FUNCTION "TMR2_32"
#define BOARD_U2_PAD_32_NET "/PWM_A1"
#define BOARD_U2_PAD_32_PINTYPE "bidirectional"
#define BOARD_U2_PAD_33_FUNCTION "GND_33"
#define BOARD_U2_PAD_33_NET "GND"
#define BOARD_U2_PAD_33_PINTYPE "power_in"

#endif /* BOARD_PINS_AUTOGEN_NOTES_H */

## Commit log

2026-05-05 Add BLE audio card hardware revision
    [NorthPoleCircuit_PCB.kicad_pcb, NorthPoleCircuit_PCB.kicad_sch, bom.csv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]
2026-05-09 Schematics and PCB update. Fiirmware v0.1
    [bom.csv, designators.csv, positions.csv]
2026-05-18 Final PCB update before ordering. Firmware update based on the CH592 Dev Board.
    [NorthPoleCircuit_PCB.kicad_pcb, NorthPoleCircuit_PCB.kicad_sch]
2026-06-05 First tests on real PCB. PCB is alive. FW comfirms most of the functionality including BLE. Hall sensor has footprint bug. IP5209 chip still not charging the battery. LED is producing only WHITE.
    [NorthPoleCircuit_PCB.kicad_pcb, NorthPoleCircuit_PCB.kicad_sch]
2026-06-09 First FW which moves the sledge. LED issue is fixed. Proper scope readouts
    [app_bringup.c, app_config.h, ch592_board_port.c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]
2026-06-13 First MVP FW which integrates all the functionality. Motion still works but not that well with other parts like Music, LEDs, Halls and Touch.
